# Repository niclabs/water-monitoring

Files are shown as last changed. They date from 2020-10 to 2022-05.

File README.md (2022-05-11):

# Sensores 🌡 

<!--
TODO: poner modelo de sensores de referencia.
TODO: poner cosas que salieron mal: medicion presión a 40cm, ...)
TODO: poner fotos de todos los experimentos para todos.
TODO: terminar de analizar íultimos datos.
TODO: poner tabla de resuemn resultados sensores.
-->

Se seleccionaron los sensores en la siguiente tabla para medir las variables fisicoquímicas de: Temperatura, Conductividad, pH, Nivel de agua y Turbidez.

| Variable | Modelo Sensor | Rango | Error | Resolución |
| --- | --- | --- | --- | --- |
| Tº | DS18B20 | \-10°C - 85°C | ±0.5 ºC | 0,0625 °C<br>(12 bit) |
| Presión | HK1100C | 0 - 1,2 MPa | 1.5% FS | 18 kPa<br>1.8 mt H2O |
| pH | Gravity: Analog pH Sensor/Meter  | 0 - 14 pH | ±0,1 pH | 0,014 pH<br>(12 bit) |
| Conductividad<br>Eléctrica | Gravity: Analog TDS Sensor/Meter | 0 - 1000ppm<br>0 - 2000 uS/cm<br>0 - 2mS/cm | ± 10% FS<br>200 uS/cm<br>0.2 mS/cm | 1,3 ppm<br>2,6 uS/cm<br>(12 bit) |
| Turbiedad | Grove - Turbidity Sensor/Meter | 0 - 3000 NTU | No indica | 4,5 NTU<br>(12 bit) |

- además se toma en cuenta los voltajes de funcionamiento de los sensores y el protocolo de comunicación.

Por lo general se sometió a los sensores a tipos de pruebas que permitieran evaluar dos dimensiones principales de su comportamiento: (1) su presición y (2) su desempeño por periodos prolongados de sumersión en medio acuático ('sensor drift'). 

## Temperatura

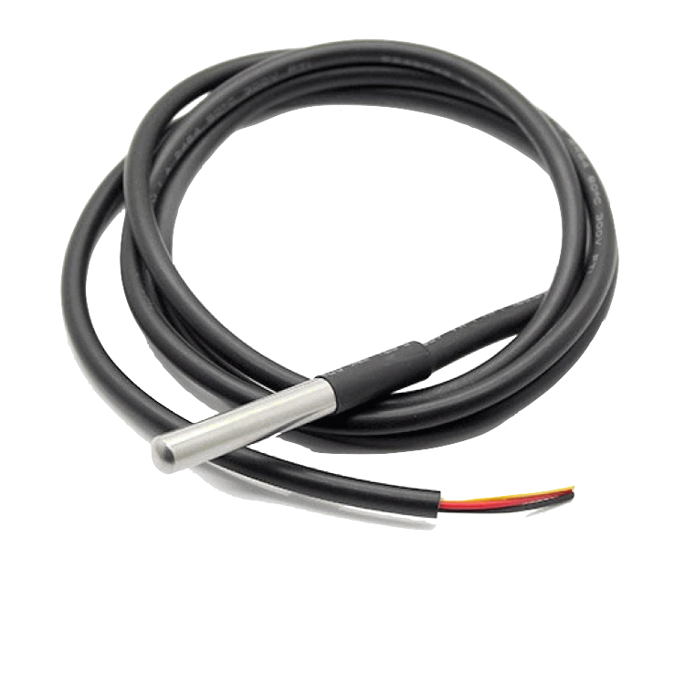
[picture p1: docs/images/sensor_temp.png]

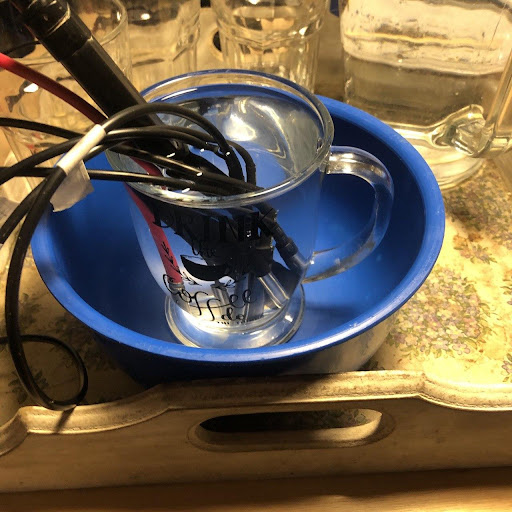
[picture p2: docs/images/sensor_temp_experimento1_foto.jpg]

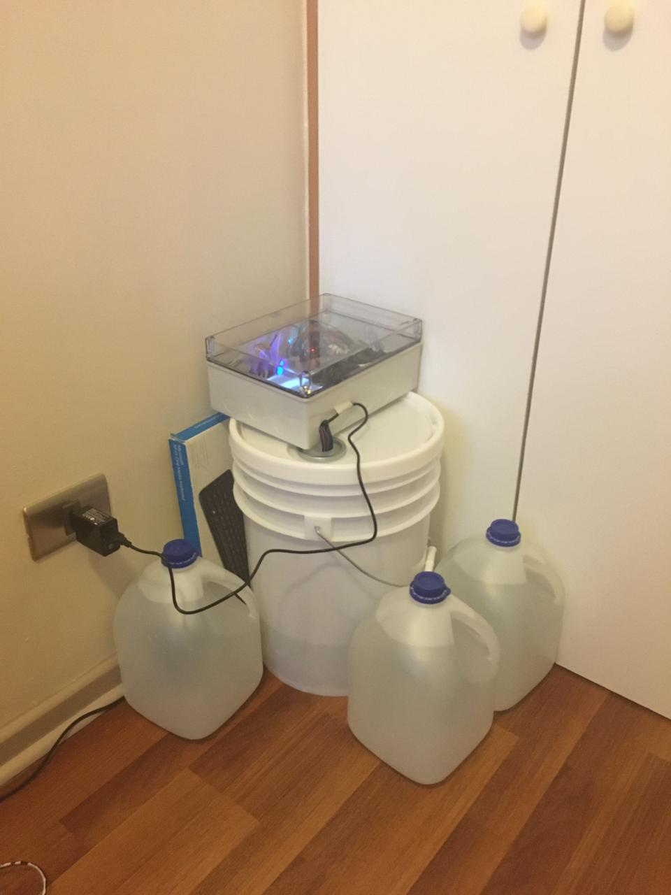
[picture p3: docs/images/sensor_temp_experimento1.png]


Experimentos demostraron un buen desempeño del sensor en su comportamiento en el tiempo

- comportamiento súper predecible.
- se debe ajustar el offset inicial.
- después de un tiempo se puede observar una leve desviación de la medidas, pero se puede corregir completamente reajustando el offset.
- errores menores a 0.5ºC y 1ºC

TODO: - Colocar sensor de referencia para saber cuál es.

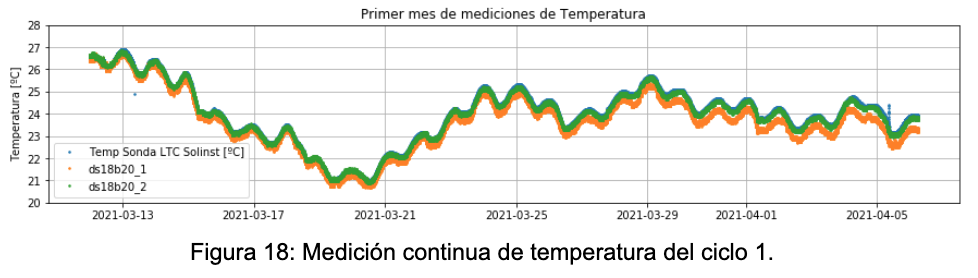
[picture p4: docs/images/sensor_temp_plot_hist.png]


- Error de dos sensores ds18b20 el primer mes de medición:
TODO: (se puede corregir por offset el error 1? indicar que sensores tenían un poco de uso ya?)

a title

- Error de sensores luego de 7 meses de uso. Experimento dura 1 mes.

a title

- Se desarrolla nueva metodología hacia últimos experimentos: ver perfil de medición en el rango. Se observa algo de histéresis en ambos sensores para la bajada.
TODO: (considerar rápidez en la toma de datos, existe histéresis en la bajada de temperatura para cambios rápidos)

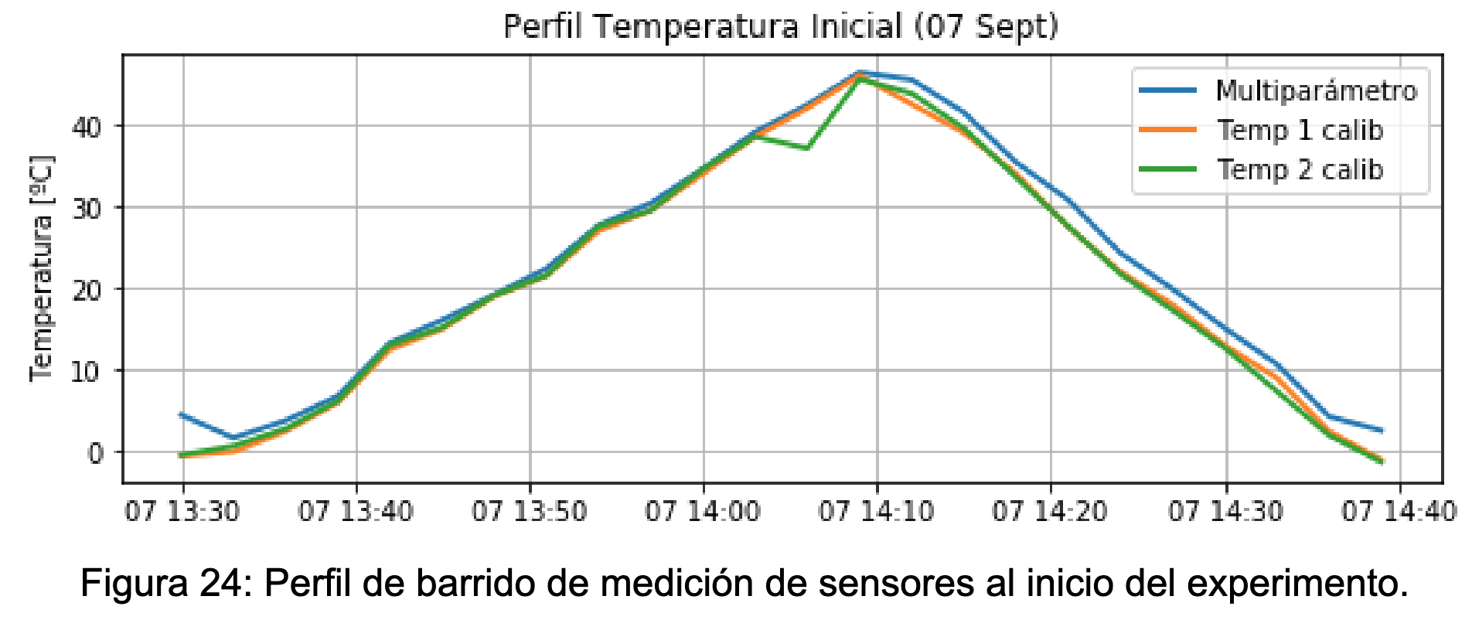
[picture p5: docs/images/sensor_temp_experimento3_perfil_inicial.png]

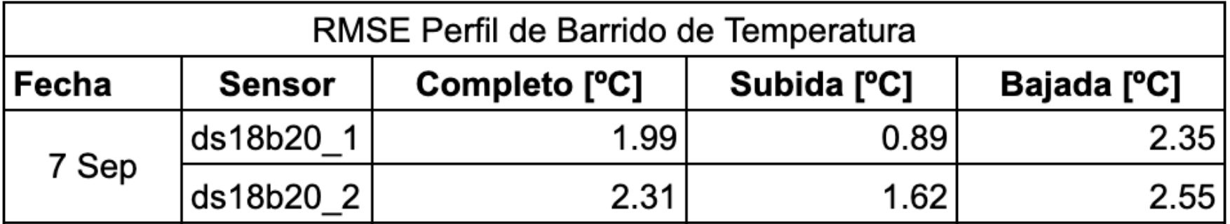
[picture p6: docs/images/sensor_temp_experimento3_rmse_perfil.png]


## Conductividad

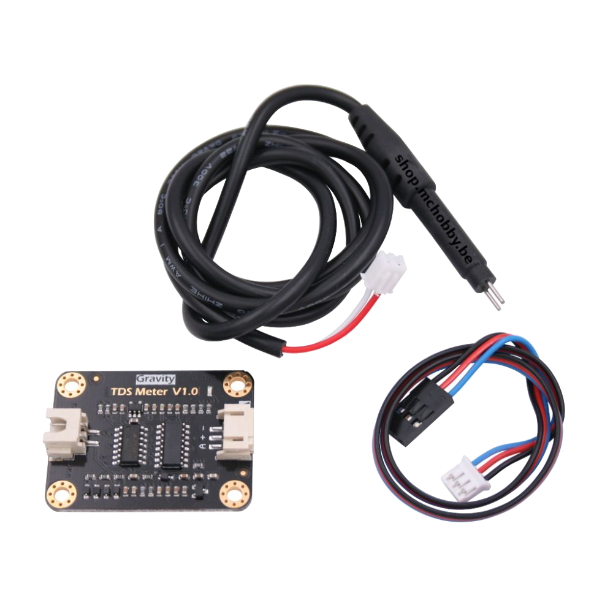
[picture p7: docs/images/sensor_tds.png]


TODO: (fotos del experimento)
TODO: al medir dos sensores de conductividad se afectan la medida. Pero el de conductividad con pH o presión o temp no.

- Ojo: Documentación indica rango [0,2000 uS/cm] ([link producto](https://www.dfrobot.com/product-1662.html))

- Perfil de medición luego de 1 mes de experimento:
    - metodología incluye sensor de control.
    - desgaste irrecuperable del sensor sumergido.
    - no se ve histéresis y tampoco en los datos

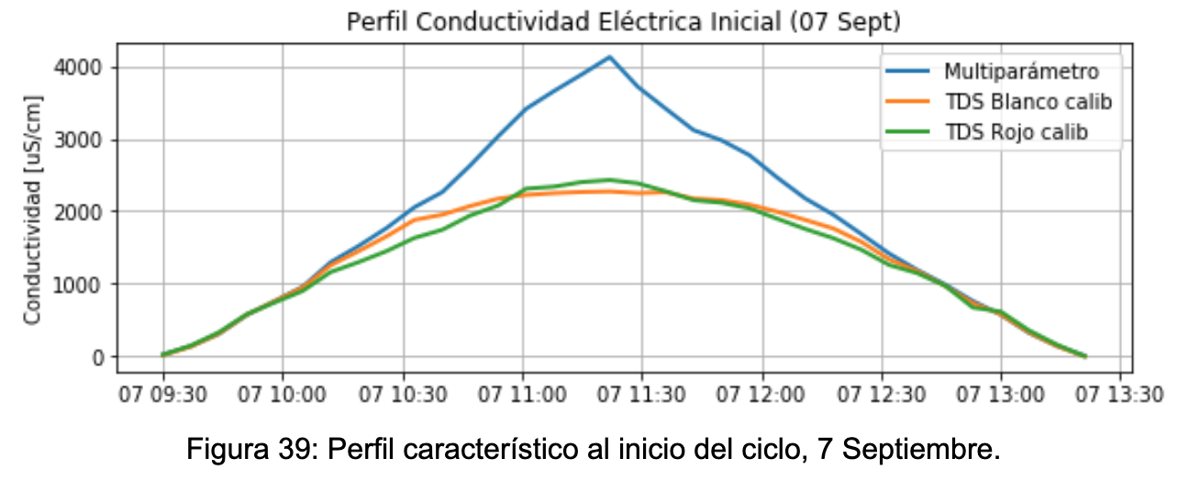
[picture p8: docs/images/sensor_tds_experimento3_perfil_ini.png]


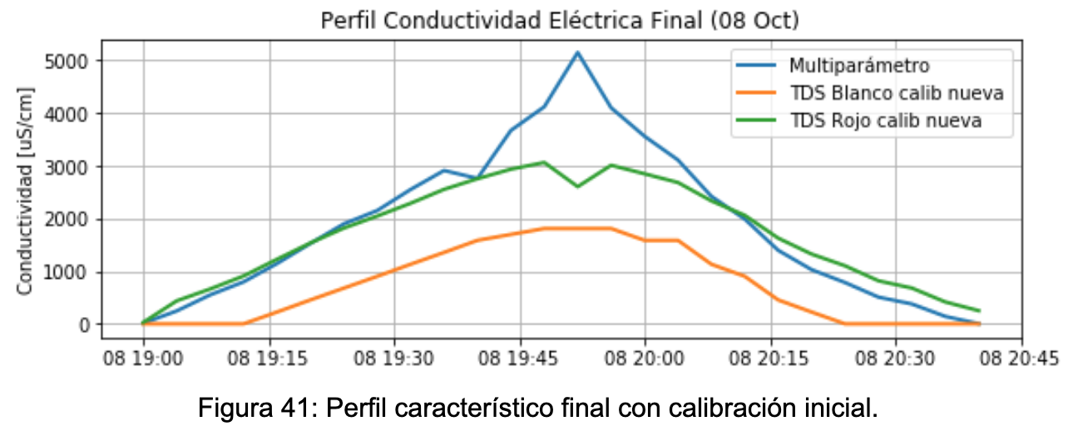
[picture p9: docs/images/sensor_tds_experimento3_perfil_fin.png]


- Si es importante la saturación sobre los valores ~1500 uS/cm y ~2000 uS/cm.

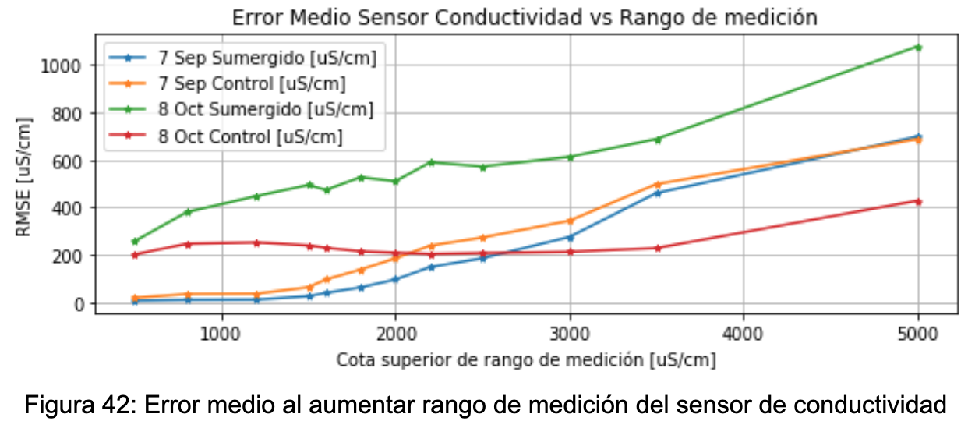
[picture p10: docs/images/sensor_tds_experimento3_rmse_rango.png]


- Se esperan más experimentos para ver si es por depositos de minerales en el sensor, o si es corregible, o fue un error puntual, o etc.

## pH

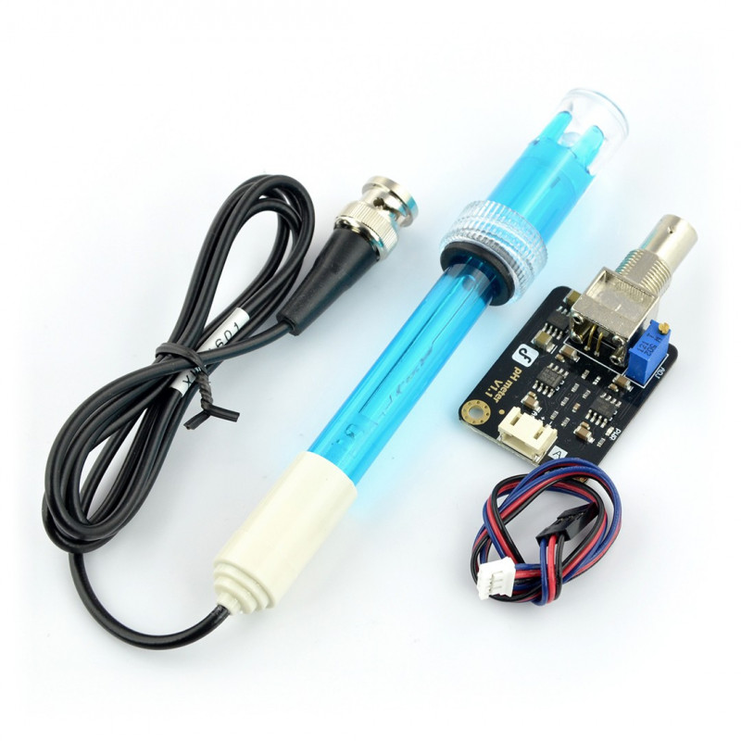
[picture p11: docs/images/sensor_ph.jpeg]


TODO: fotos experimento

- no se ve mucha histéresis
- hay harta variación en la calibración pero es posible recalibrarla y los sensores vuelven a funcionar.
- se esperar hacer más experimento para corroborar datos y además poder ir estimando que tan rápido se descalibran los datos, y cuánto se va perdiendo de presición con cada recalibración.

- Perfil inicial del experimento:
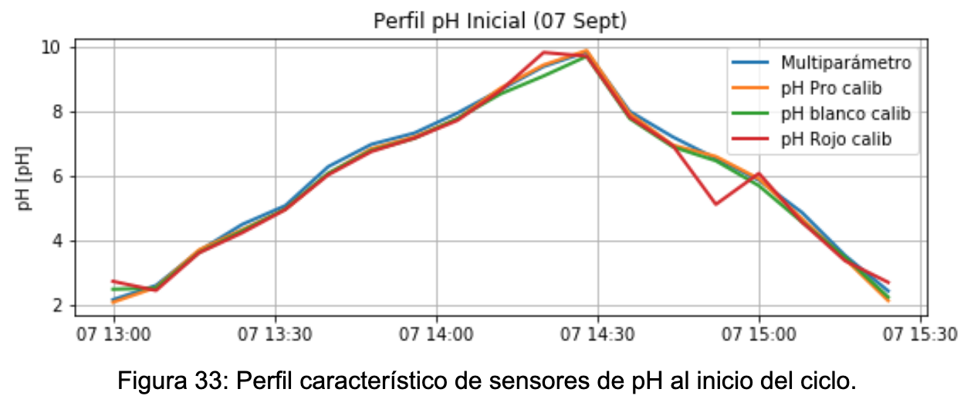
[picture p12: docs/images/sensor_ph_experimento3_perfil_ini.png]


- Perfil al final del experimento sin recalibrar:
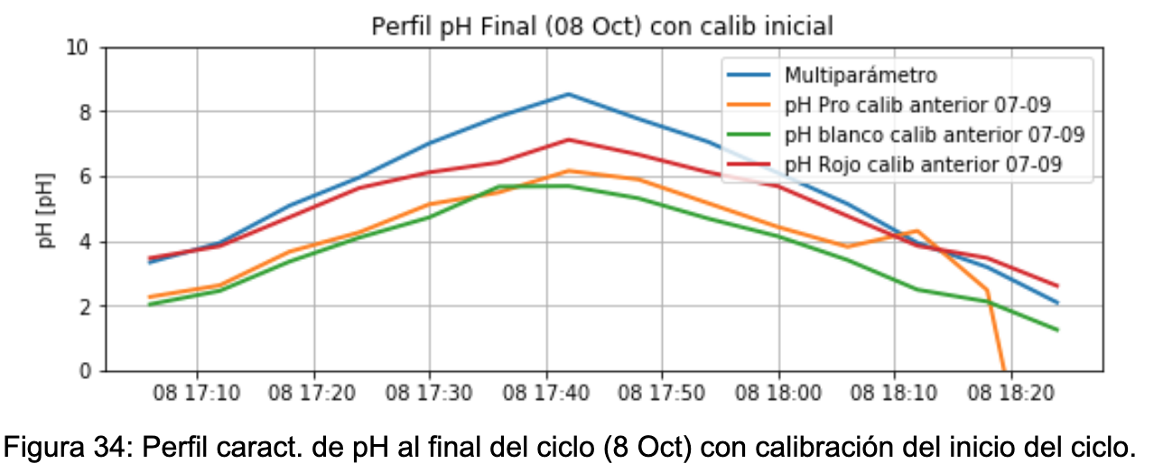
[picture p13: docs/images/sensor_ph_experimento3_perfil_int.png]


- Perfil final con recalibración de los sensores:
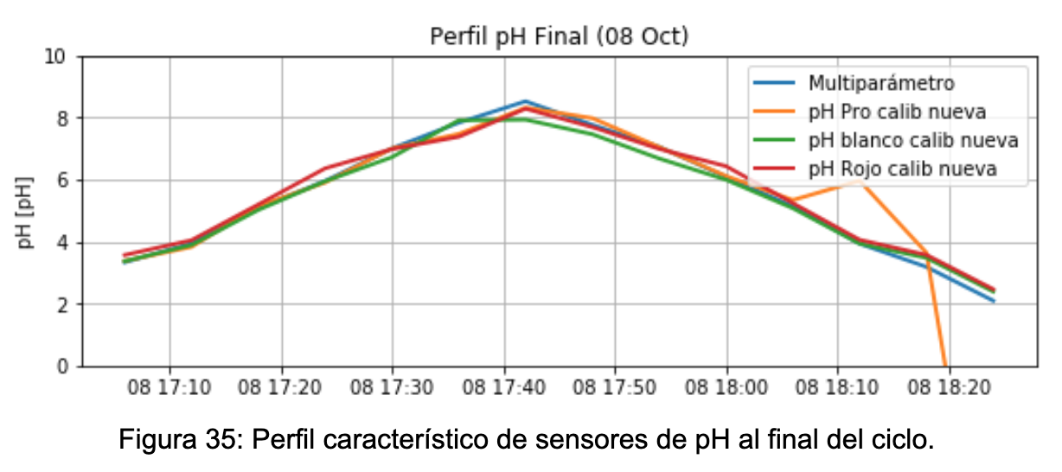
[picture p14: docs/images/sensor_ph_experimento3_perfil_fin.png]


## Nivel de Agua

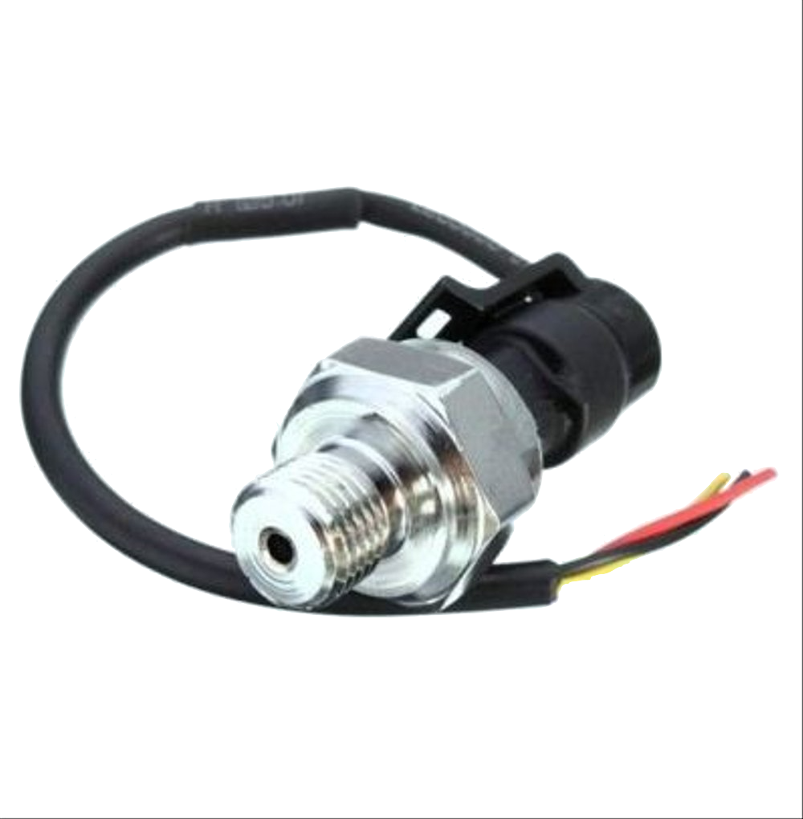
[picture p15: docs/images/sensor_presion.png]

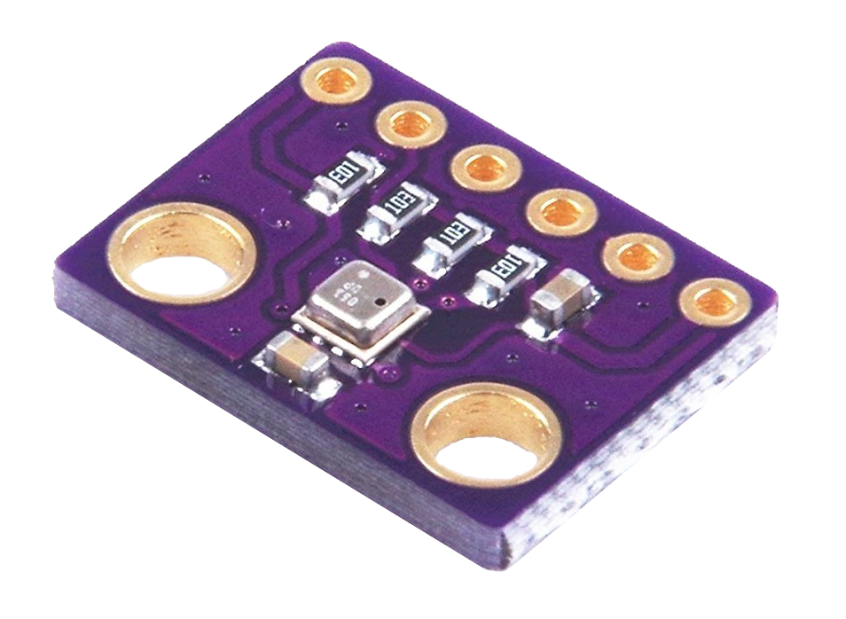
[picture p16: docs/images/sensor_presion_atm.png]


- Se utilizan dos sensores para calcular la columna de agua 
- TODO: Poner sensores dereferencia para ambos casos.

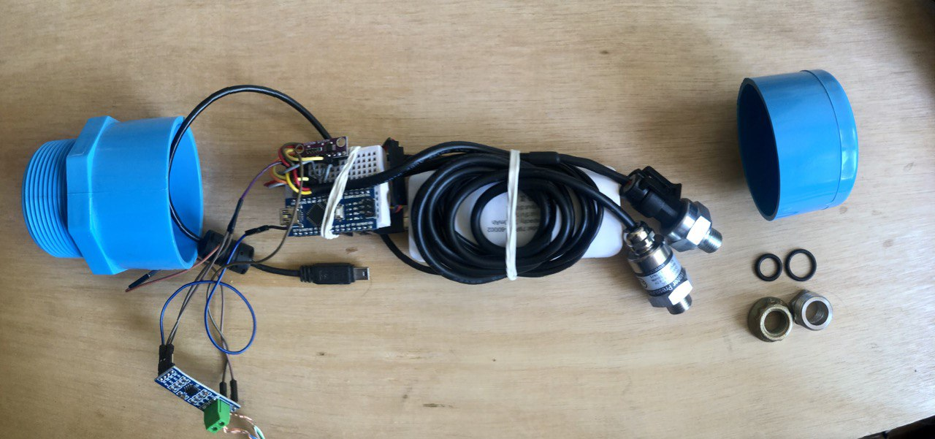
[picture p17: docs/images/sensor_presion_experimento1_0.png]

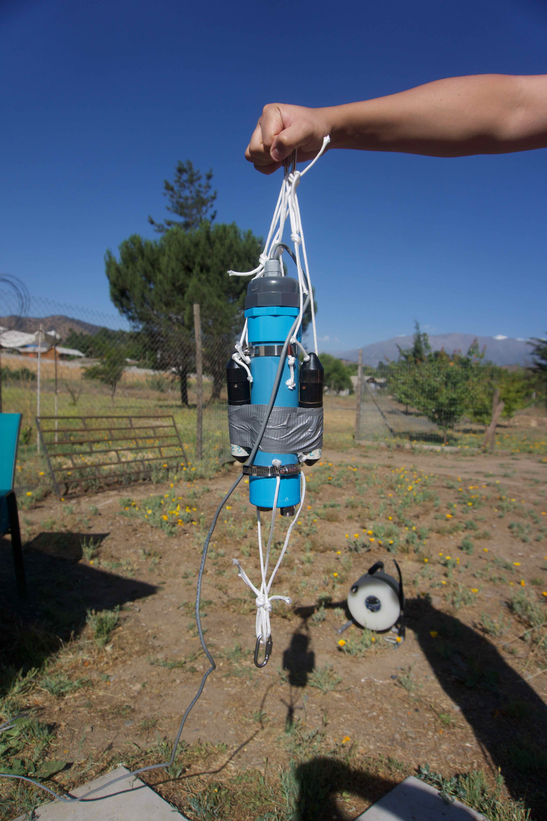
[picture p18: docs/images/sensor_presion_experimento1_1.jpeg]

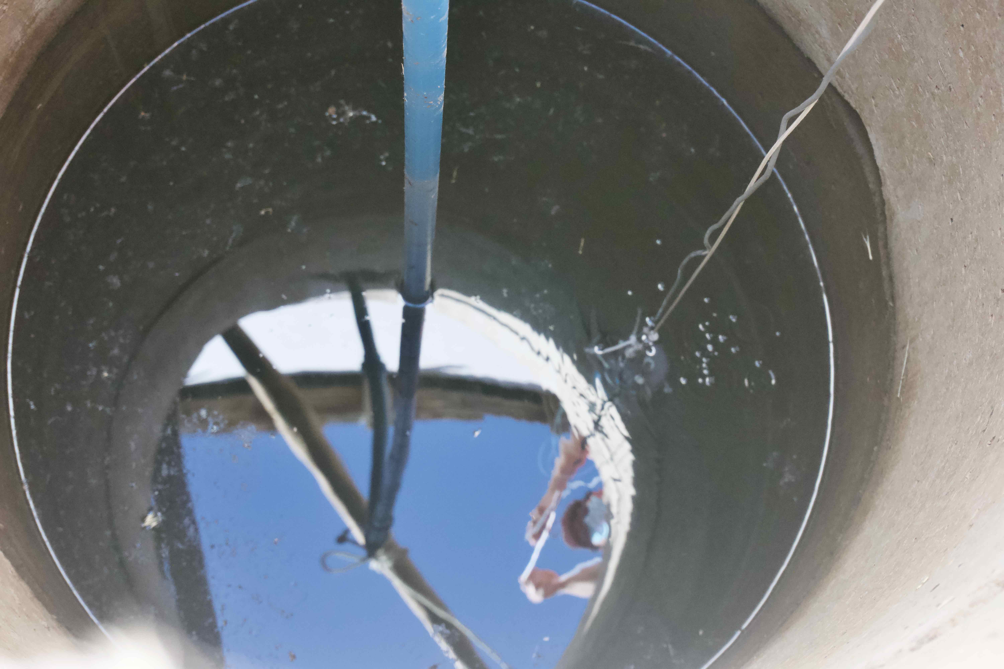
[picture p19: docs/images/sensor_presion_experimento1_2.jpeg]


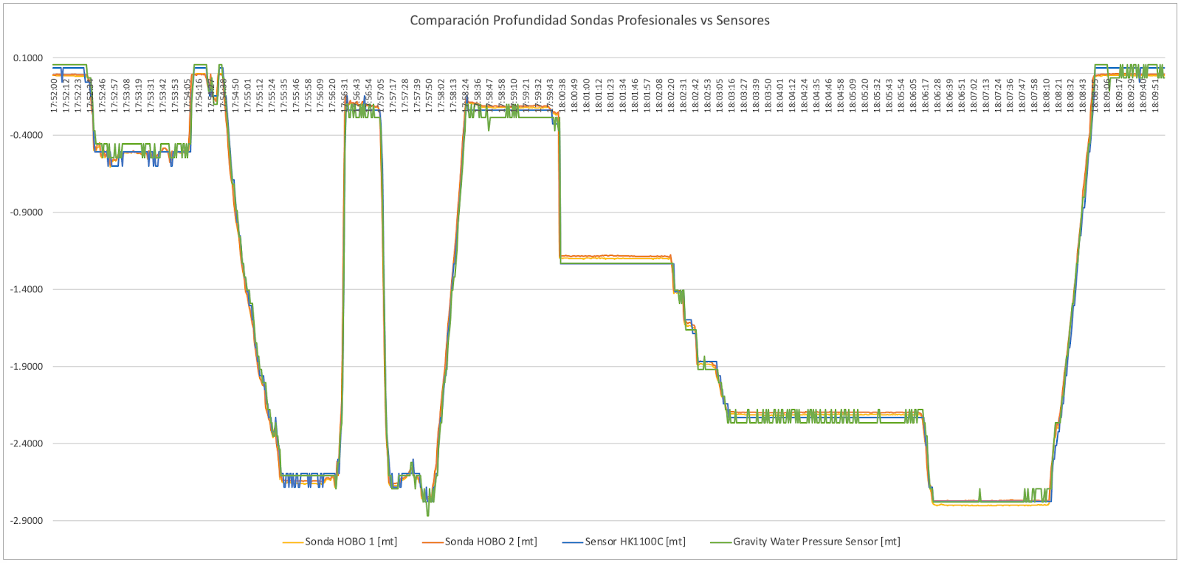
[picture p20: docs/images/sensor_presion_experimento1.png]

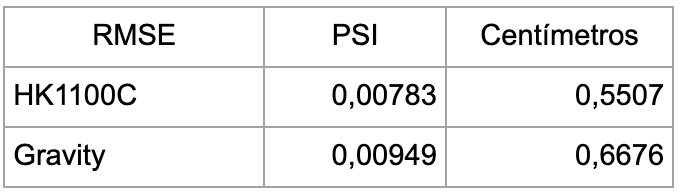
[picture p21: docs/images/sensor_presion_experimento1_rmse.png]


- últimos experimentos fueron en baldes de agua y mato, porque muy poca altura asi que el desempeño fue peor, pero este no empeoró luego de 6 meses con sensores sumergidos.

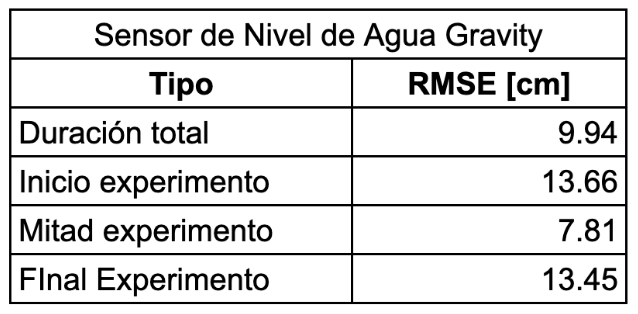
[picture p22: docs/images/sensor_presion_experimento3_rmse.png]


## turbidez

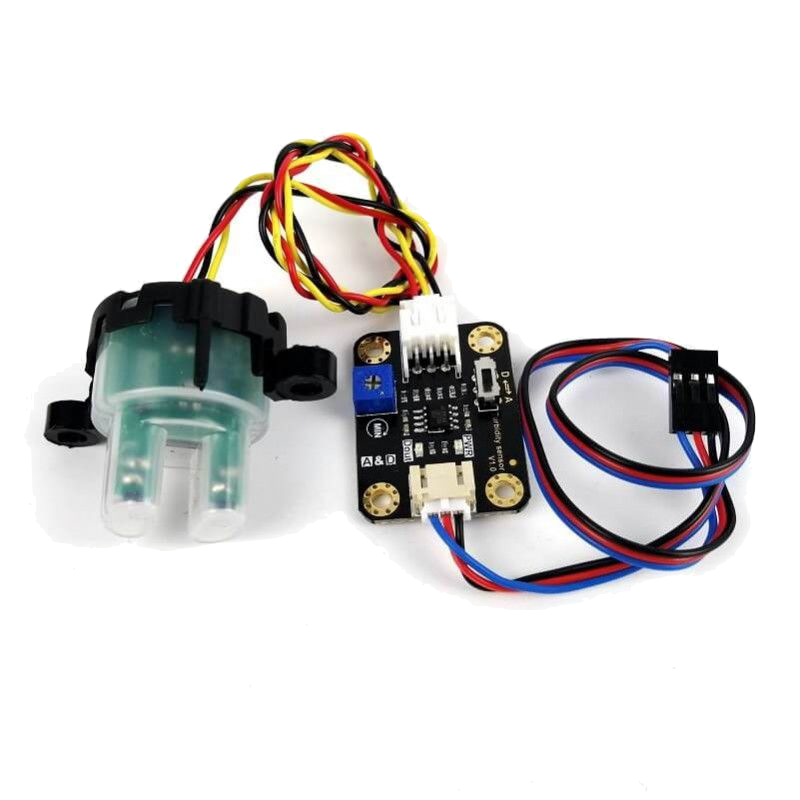
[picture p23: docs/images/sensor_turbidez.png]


- primeros experimento dieron cualquier cosa, dificultad en uso de sensor muy delicados a la luz y otras variables dificiles de controlar.

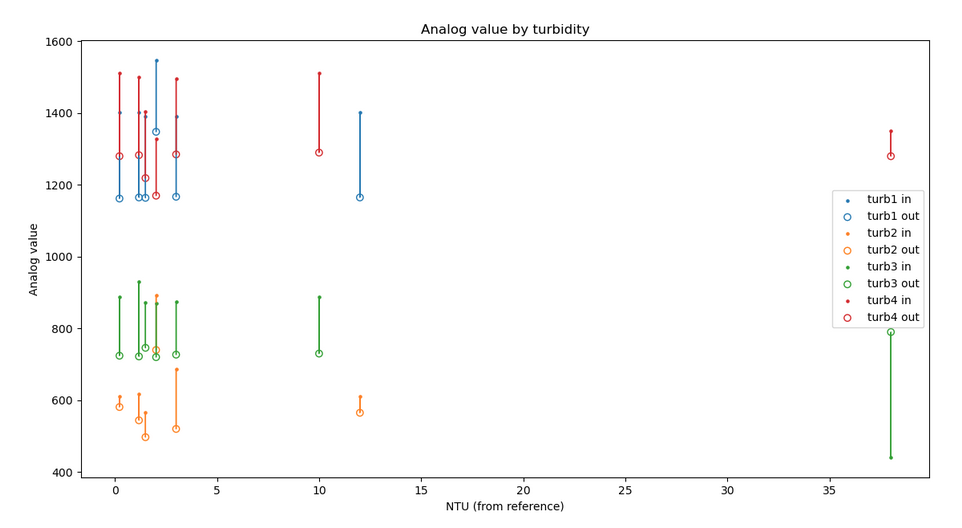
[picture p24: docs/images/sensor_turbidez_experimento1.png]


- Errores del rango de ~1000 NTU. No confiables, quizás solo apra alertas grandes pero mejor seguir buscando.

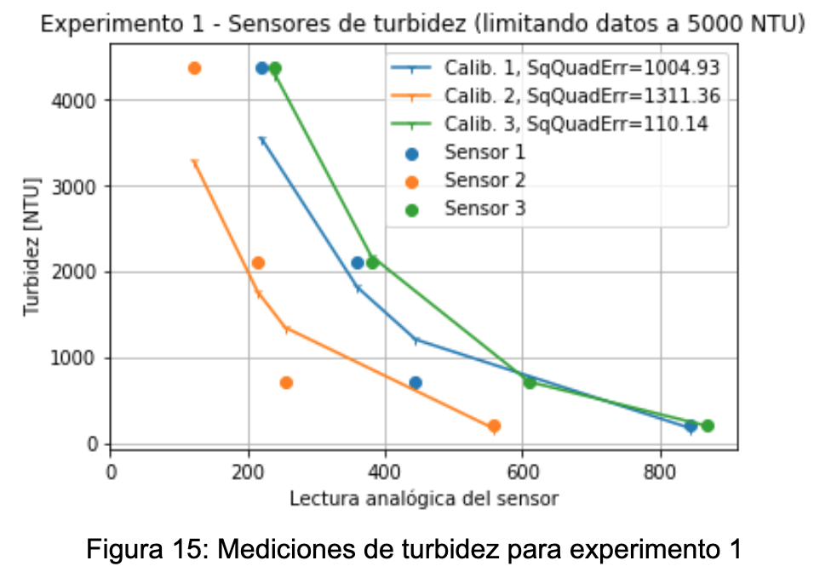
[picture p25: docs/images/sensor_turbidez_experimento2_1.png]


# 💻 Electrónica

## Diseño
El dispositivo de electronica (nodo sensor) diseñado para el monitoreo de de agua en intervalos de tiempo de manera autónoma, esta basado en tomar las medidas con sesores para ser enviadas mediante comunicación serial a un sistema de comunicación para el monitoreo de estas características, este dispositivo tomará medidas de pH, Condutividad, turbidez, temperatura y presión.

*imagen sistema completo resaltando el nodo sensor*

### Prototipo
Como prototipo  se realizó un circuito en Arduino para realizar pruebas con sesores, medidas y comunicación para obtener una versión funcional que pudiera enviar los datos. Este prototipo su funcionamiento principal se basa en dos estados principalmente Reposo (Sleep), estado en el cual se esta en bajo consumo y sin trabajo de meddidas y segundo activo que esta encargado de tomar las medidas de los sensores, guardar estos datos de manera codificada y enviarlos de manera serial con comunicación 485.

El funcinamiento básico se puede ver en el siguiente diagrama:

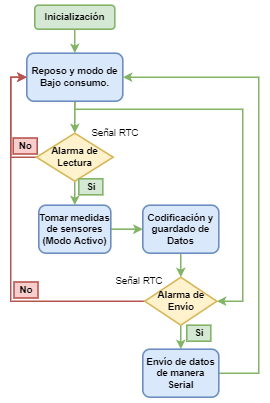
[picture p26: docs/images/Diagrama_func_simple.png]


#### Selección de componentes.
Dado lo anterior los componentes que integran este prototipo inicial son los siguientes:

1. **Arduino Nano:** Microcontrolador principal con el programa principal.
1. **ADC:** Lectura de señales analógicas a digitales de los sensores.
1. **RTC:** Encargado de establecer las alarmar de medida y envio al microcontrolaor para llevar a cabos estas tareas.   
1. **Modulo SD:** Para el guardado de los datos medidos de manera codificada.
1. **Sensores:** Temperatura, conducitividad, pH, Presión y Turbidez. 
1. **RS485:** Para realizar una comunicación serial de gran alcance(>10m).

Destacar que estos sensores seleccionados se sometieron a una serie de pruebas para comprobar su rendimiento, ver sus limitaciones y desgaste en el tiempo explicado en mas destalle en el apartado de sensores.

Por otra parte la conexión entre estos componentes esta dado se manera simplificada en el diagrama a continuación:

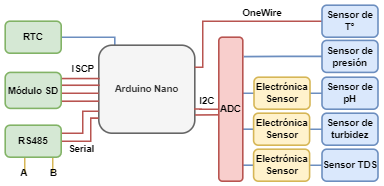
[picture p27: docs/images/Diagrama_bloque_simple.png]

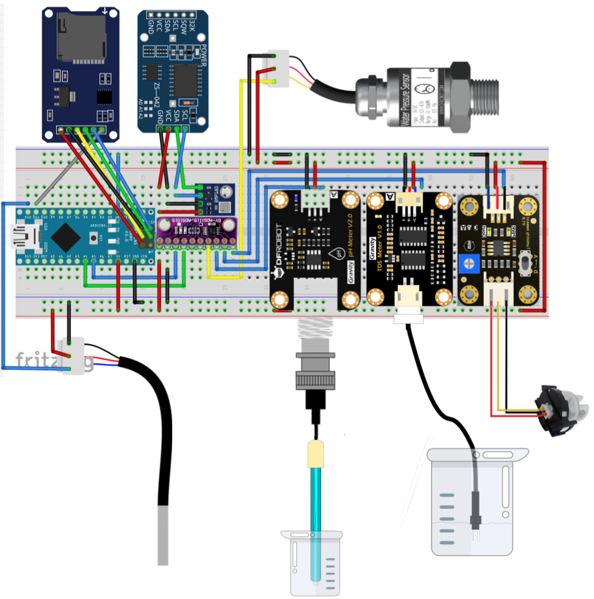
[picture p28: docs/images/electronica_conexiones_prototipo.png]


Donde los sensores TDS, pH y turbidez poseen su electrónica, el de presión entrega sus valores al ADC y el de temperatura mediante comunicación "OneWire" directamente al microcontrolador. El módulo SD se comunica con el microcontrolador a travez de conexion "ISCP", en cambio el ADC posee una conexión I2C para tener las señales de los 4 sensores y por último la imformación de los sensores es enviada de manera serial al componente 485 y es enviada mediante los canales A y B. 

Como resultados iniciales se tiene un nodo sensor capaz de obtener medidas, guardar estos datos en una microSD y además enviar estos datos de manera serial siendo un prototipo inicial lo suficientemente útil para la realización de pruebas en profundidad y analizar las limitaciones de los sensores bajo condiciones en profundidad controlada.

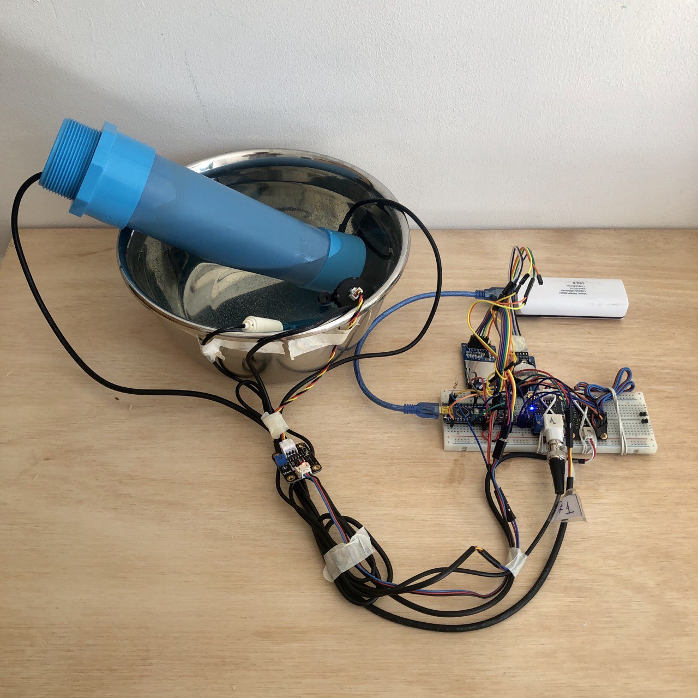
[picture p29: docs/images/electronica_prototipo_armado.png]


### PCB
Continuando con las mejoras del del nodo sensor, y el prototipo funcionando de manera adecuada, si bien es un dispositivo apto para la realización de pruebas controladas, se busca un dispositivo más apto en terrenos reales, como profundidasdes de aguas de al menos 30 metros. Para ello se relizó una integración den PCB con un frabicante local de PCB y diseño de circuitos, pasando prototipo a una PCB con mejoras incluidas dadas principalmente en el sistema de energía y espacio:

1. **Fuente energética con baterías:** Agregar al nodo un circuito de energía que sea alimentado a travéz de baterías de litio 18650 con toda su electrónica para un correcto funcionamiento (Cagardores y elevadores).
2. **Distribución energética de componentes:** Dividir la fuente de energía en una activa (5V) que siempre entrega alimentación al sistema y una de reposo (5Vs) que se apaga cuando el sistema no esta midiendo o enviado datos para aquellos componentes que puedan ser apagados para reducir el consumo lo mayor posible.
3. **Reducción de espación para Carcasa:** Optimizar el espacio creando un dispositivo con la electrónica más compacto para la utilización de la carcasa especial que fue diseñanada especialemnte para ser más apta al surmergirse.

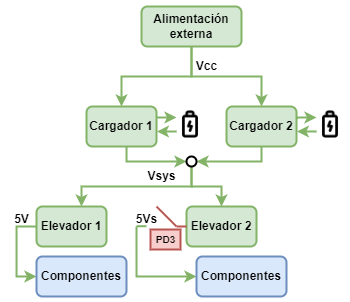
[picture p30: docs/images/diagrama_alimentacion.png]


La PCB incluye toda la electrónica de sensores y las necesarias  como reguladores de voltaje (-5V,3V,-3V y 3.3V) para compoenetes y electrónica siendo una pieza completa que se insertan los sensores para tomar las medidas. Posee además una conexion FTDI para realizar la programación del microcontrolador y un interruptor para utilizar comunicación serial directa al microcontrolador en vez de la 485 para la realización de pruebas.

a title

#### Historial de Versiones

Debido a diversos tipo de situaciones como falta de pistas o distribuciones de los componentes en diferentes fuentes de energía (5V y 5Vs) o simple optimización de esta, se obtuvieron diferentes versiones de PCB como modificaciones diferenciadas principalmente en la distribución energética a modo mejora,  estas versiones y modificaciones estan resumidas en la siguiente tabla.

| PCB | **Modificación** | **Características** | **Resultado** | **Problemas** |
|---|:---|:---|:---|:---|
| **Versión 1.a** | Primera PCB fabricada | Distribución de alimentación en reposo y continua. | Placa completamente funcional | La alimentación de resposo solo esta conectada con el compoente RS485. |
| Version 1.b | Corte y cambio de pistas para la PCB inicial | Distribucion energética de compoenetes mas eficiente. | Reducción del consumo en estado activo. | Componete RS485 de alto consumo en rposo |
| Version 1.c | Cambio de compoente RS485 manualmente | Optimización de consumo en rposo | Problema funcional de la placa, (mala practica de soldadura) | PCB sin funcionamiento. |
| **Versión 2.a** | PCB con enrrutado nuevo | Compoentes divididos en su mayoria correctamente | Placa completamente funcional | RS485 de alto consumo y en alimentación continua, falta de una pista.  |
| **Versión 3.a** | PCB con enrrutado nuevo | Correccion de la pista faltante de la version antrerior. | Placa completamente funcional | RS485 de alto consumo y en alimentación continua. |

Estas versiones se ejemplifican en esquemas a continuación para detallar los cambios de distribución energética de los compoentes que son alimentados con 5Vs y 5v respectivamente.

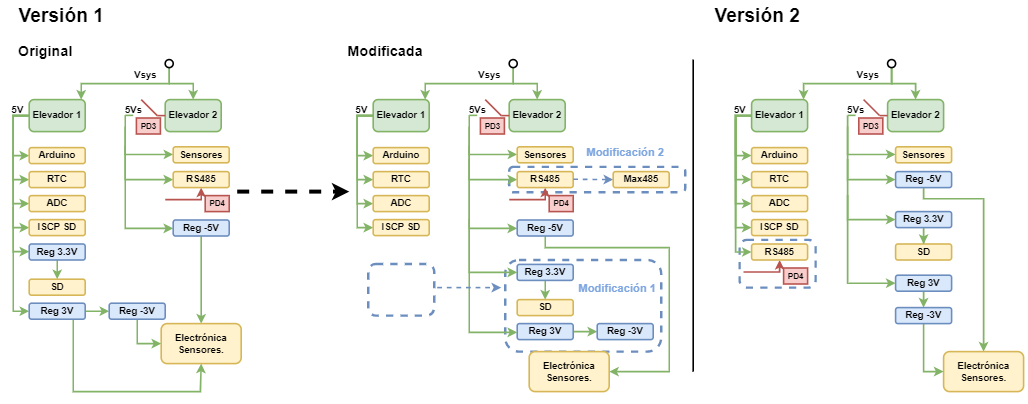
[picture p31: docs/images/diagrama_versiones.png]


<br>
- Mejoras no realizadas: como mejoras no realizadas se tiene el cambio del componente de comunicación 485 de alto consumo debido a que es antiguo, aun más en esta versión ya que esta conectado en la alimentación constante por lo que este consume con el sistema en reposo.
## Fabricación

Con los archivos de una versión funcional del sistema (Versión N°2), se realizó un estudio en la fabricación de esta placa para tener una idea y obtener un analisis en terminos de los costos que tiene finalmente el "nodo sensor". 

### Cotización:
Para cotizar se considero la posibilidad de una fabricación y ensablaje completamente externo con los componetes entregados por el fabricante.

#### 1. Fabricación y ensamblaje externo:
Consireaciones:
 * Para esta cotización se tomaron en cuenta los fabricantes: JLCPCB, PCBway, PCBgogo, EEcart, SeedStudio.
 * Los precios obtenidos son dados en base a cotizaciones rapidas entregadas por los fabricantes.
 * Los archivos requeridos para las cotizaciones Gerber (PCB), BOM (componentes) con un formato específico para cada fabricante y el *"pick and place"* en algunos casos.
 * La cotización fue realizada para una cantidad de 5 PCBs ensambladas (cantidad mínima aceptada).

 #### 2. Fabircación externa y ensamblado local:
 La cotización de esta opción la placa es fabricada de manera externa y los componetes cotizados a los distribuidores.

 Consideraciones:
* El ensamblaje se consideró de manera manual.
* Utilización de stencil para el ensamblado.
* Se realizó una cotización de 5 placas.
* No todos los componentes son fáciles de obtener, se tiene que buscar sustitutos dependiendo del stock.
* Digikey y Mouser como distribuidores de componentes (al ser los mas completos).
#### 3. Comparación de opciones:

Dado el detalle del valor de componentes se hace una comparación entre las 2 opciones de fabricado,se consideró EEcart y PCB como fabricantes por ser las mejores opciones. además de una fabricación completa externa con una optimización de precios en componentes (RTC,pH), por un lado el RTC tiene un precio elevado y por otro el conector de pH se adquiere con el sensor.

Resultados y precios:

| | **Total (5u)** | **Total+ 30%** | **Precio unitario** | **Tiempo**  |
|---|---|---|---|---|
| **Local** | $772.09 | $1003.72 | $200.74 | 3-4 semanas |
| **Externa EEcart** | $907.26 | $1179.44 | $235.89 | 5 semanas |
| **Externa PCBWay** | $888.45 | $1176.19 | $231.00 | 5.5 semanas |
| **Externa PCBWay (RTC,pH)** | $705.06 | $916.58 | $183.32 | 5 semanas |

Considerar además un precio extra en cuando a sensores y baterías del dispositivo de $100.92USD/unidad aprox.

#### 4. Pros y contras

| Fabricación Local | Fabricacion Externa |
|---|---|
| - Menos tiempo estimado de realización. <br> - Menor precio estimado. <br> - Ensamblado manual. <br> - Dificultad de obtención de algunos componentes (stock limitado).  | - La placa llega para usar directamente. <br> - Margen de optimización. <br> - Mayor tiempo de espera. <br> - Mayor precio. |

### Programación
Hablando del software del dispositivo nodo sensor se poseen 2 versiones  con y sin SD para su funcionamiento, estos posee las siguentes caracteristicas:
1. Posee variables de los períodos de medida y envvío de datos: Es una de las características más importantes para la definición de tiempos de funcinamniento del sistema. La variable "Freq_sens" indica cada cuantos segundos tomada una medida de los sensores y la variable "Freq_send" representa el intervalo en segundos en el que son enviados los datos, claramente  Freq_send > Freq_sens  ya que deben existir datos medidos para ser enviados.
2. Codificación de lectura de datos: Para realizar un envío más eficiente ya sea por velocidad, memoria, disminución de consumo energético en el momento de enviar datos se desarrolló una librería que codifique los datos para ello. Lo importante a destacar es qu exite una codificación de lectura y otra de envio explicada mas adelante.

La codificación de lectura simplemente pasa a bytes(9) la medida (valor) del sensor, tiempo(timestamp) dado por la alarma de medida del RTC en formato "Unix" y si ID del sensor (valor predeterminado).

3. Guardado de datos en un "DataBlock": Los datos de cada intervalo, es decir, el tipo (sensor ID), su valor y tiempo de medida (Timestamp) en cada sensor son codificados (explicado más adelante) en bytes al que llamaremos "sensor reading", estos son generados en cada medida y será guardado en el "Datablock" (arreglo) de 512 bytes que actuara como memoria RAM-buffer. Los "sensor reading" son lo que poseen la codificación de lectura con un largo de 9 bytes para el guardado de los datos. Dado esto la estructura del Datablock esta dada por 2 bytes para llevar el conteo de medidas, 504 bytes para "sensor reading" (56 medidas u 11 medidas de 5 sensores) y 6 bytes sobrantes como se puede ver a continuación.

Para el caso de la sd cuando el DataBlock esta lleno guarda los datos en archivos binarios dentro de la tarjeta SD y los envía junto a los valores del arreglo cuando sea el tiempo de enviado con una codificación nueva para el enviado. Si es la versión sin sd no se posee más memoria que la del arreglo por lo que esta limitado a medir una cantidad maxima de datos antes de enviar, por lo que la "Freq_send" tiene esta limitante, por ejemplo,un máximo de 11 veces la Freq_sens para 5 sensores para no perder datos en la codificación base.

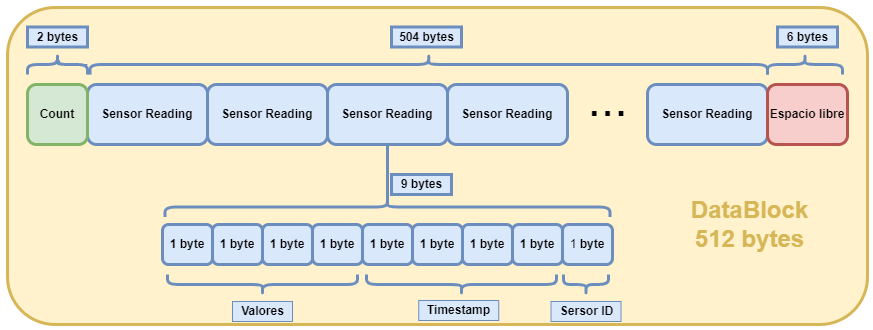
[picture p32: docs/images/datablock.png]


4. Codificación par envío de datos: Para reducir la cantidad de tamaño de los datos enviados y asi realizar un envío más rápido con menor consumo, se reali´zaron distitos tipos de codificación de enviado a modo de reducir el tamaño de los datos.
* Codificiación de envío base:  Para esta codificiación y las siguientes se define un nuevo bloque "Sensing Unit", que se divide en 1byte "Header" que posee la informacion del tipo de codificación y la ID del sensor y 6 bytes "Payload" que contiene 4bytes para el Tiemstamp y solo 2bytes para el valor del sensor, esta reducción ene le valor del sensor se debe a que los valores de los sensores al ser pequeños pueden ser prefectamente representados en 2bytes. Reduciendo la unidad "sensor reading" de 9bytes a la unidad "Sensong Unit Base" de 7bytes.

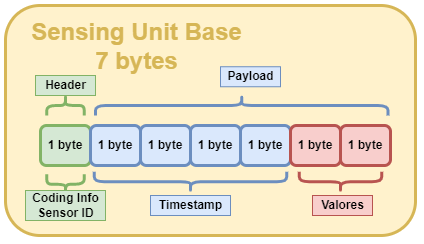
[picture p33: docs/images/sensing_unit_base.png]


* Codificación envío repetivvio:
* COdificacion envío diferencial:

4. Los datos son envidos mediante transmisión serial RS485  como paquetes de bytes: Como los datos son codificados a bytes estos son enviados de esta manera en paquetes de bytes a través de comunicación serial RS485 estos estan dados por un tamaño máximo de 51 bytes, es decir, 7 Sensing Unit (49 bytes) y 2 bytes para detección de errores. Este tamaño se define debido a que es el tamaño mínimo de un paquete en LoRa (módulo de comunicación inalámbrica utilizada en la superficie del sistema).

Código completo:
El primero es el codigo completo que utiliza la sd para el guardado de los datos, el codigo esta centro

Ejemplos del funcionamiento de medidas:

## Roadmap
backlog
pasos futuros

| N  | Título | Detalle |
| -- | --- | --- |
| 1  | Mover uSD a superficie | Hacer que la uSD sea controlada y alimentada desde el nodo de comunicaciones en vez del nodo sensor. |
| 2  | Bajar ciclos del oscilador a 8Mhz | Disminuir ciclos del oscilador de 16MHz a 8MHz. Esto disminuye la velocidad a la que opera el sistema sin afectar el funcionamiento de los programas. Funcionando a la mitad de ciclos se espera una disminución del consumo del procesador en el sistema. |
| 3  | Ocupar VCC 3.3V | Bajar alimentación del sistema de 5V a 3.3V. Se debe prototipar y validar el funcionamiento de componentes y electrónica. Con este cambio disminuye el consumo general de energía del sistema obteniendo mayor desempeño de estados de deep-sleep. |
| 4  | Amplificador universal multiplexado | Si se caracterizan debidamente las sondas y se verifica que el procesamiento de los circuitos intermediarios se pueden realizar de forma digital, una opción es tener un amplificador para todas las sondas, las cuales mediante multiplexión temporal entren a éste (opcionalmente un digipot puede ayudar a modificar la ganancia). Esto podría reducir drásticamente la cantidad de componentes en placa. |
| | Integrados de carga de baterías en paralelo | |
| 5  | Autonomía de sensores (drift) | Si se va a aumentar la autonomía del sistema, es necesario verificar si en ese horizonte de tiempo los sensores serán funcionales. |
| 8  | Optimización de componentes | Relacionado con los puntos 3 y 4, hay que repasar toda la selección de componentes en términos de funciones y equipos. También se relaciona con la programación. |
| | | |
| 6  | Autonomía energética (solar, electrónica) | Añadir un sistema de carga solar para recargar las baterías 18650 del nodo sensor podría en prácticamente cualquier caso mejorar la autonomía. |
| 7  | Batería de auto | Colocar una batería de auto para todo el sistema teóricamente aseguraría una mayor autonomía. |
| 9  | Programar nodo a distancia | \- Se podría cambiar el atmega por un esp que se programe a distancia. |
| 10 | Switch magnético de encendido | Se puede agregar un switching on/off del sistema que se puede activar desde fuera de la carcasa con un imán para de esta manera poder ahorrar energía cuando no se esté utilizando el dispositivo. |
| 11 | Modularizar datalogger de adaptadores sensores | Separar en placas separadas, pero conectables el datalogger (uC, RTC, SD, energía) de electrónica de amplificación de los sensores dfrobot (pH, turbidez, conductividad) | z<x

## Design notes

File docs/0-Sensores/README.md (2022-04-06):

# 🌡 Sensores

## Opciones

## Costo

## Resultados

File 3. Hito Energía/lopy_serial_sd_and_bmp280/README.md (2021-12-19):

# lopy_serial_sd_and_bmp280

Conexión de la LoPy con un Arduino mediante UART. Cada vez que la LoPy recibe un mensaje del Arduino, lo almacena utilizando el lector de microSD de la tarjeta de expansión.

- Código LoPy (`LoPy4_sd`) basado en `LoPy4_serial`
- Código Arduino (`dummy_data_sender`) basado en `arduino_nodo_sensor`

Cableado:
- Conectar, a través de un adaptador de nivel, los pines de comunicación serial de la LoPy y del Arduino según dice `LoPy4_serial/boot.py` y `dummy_data_sender/dummy_data_sender.ino`, respectivamente. *CAVEAT*: Usar pines P3 y P6. El P4 lo utiliza la LoPy para comunicarse con la tarjeta SD.
- Conectar la LoPy a la tarjeta de expansión
- El contenido del buffer del script de Arduino debería ser `0xF0000000000015F100000009001FF200000013000EF30000001D0010F4000000270006` (35 bytes). Esto también se incluye en el archivo `dummy.bin`.
- El mensaje recibido vía UART por la LoPy, una vez descartado el primer byte, debería ser `b'f0000000000015f100000009001ff200000013000ef30000001d0010f4000000270006'`. Esto calza con el mensaje enviado.
- Los datos decodificados son `[(0, 0, 2.1), (1, 9, 3.1), (2, 19, 1.4), (3, 29, 1.6), (4, 39, 0.6)]`, consistentes con lo codificado desde el Arduino.

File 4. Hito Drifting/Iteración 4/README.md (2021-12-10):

# Sketches Experimentos Sensores - Iteración 4

Experimentos de la <b>Iteración 4</b> corresponden a más experimentos de Presión y Conductividad. Se está evaluando nuevos experimentos de sensores de pH, junto con buscar nuevos modelos o equipos de medición para todos lo sensores anteriores.

Experimentos se desarrollan en casa de Pablo Martín y en Laguna Carén.

## Programas Arduino

### FONDEF_carcasa_arduino_datalogger

Programa para electrónica a sumergir en Laguna Carén dentro de carcasa fabricada por +D.

| Funcionamiento |
| - |
| - Lectura periódica de sensor de RTC, Sensor de Presión y BME280, almacenamiento en micro SD
- Carga de batería 18650 de 3200mAh desde alimentación externa |

| Componentes | | |
| - |  - | - |
| Arduino Mini Pro 3.3V 8MHz | Módulo SD | DS3231 |
| Batería 18650 |  TP4056 | ADS1015 |

| Sensores | |
| - | - |
| Presión | BME280 |

### FONDEF_drifting_arduino_datalogger_it4_serial2nodemcu

Programa para Iteración 4 de experimentos de presión y conductividad. Corresponde al sketch de arduino que captura periódicamente datos desde sensores y rtc, los guarda en micro SD y los envía por serial para que NodeMCU los suba a Servidor Niclabs y Telegram Bot.

### FONDEF_drifting_arduino_datalogger_it4_serial2nodemcu_v2

Igual al anterior (_FONDEF_drifting_arduino_datalogger_it4_serial2nodemcu_) pero con dos ADS1015 para medir 6 sensores en paralelo (capacidad de 1 - 8 sensores análogos).

### FONDEF_drifting_nodemcu_HTTP_POST_niclabs

Programa para Iteración 4 de experimentos de presión y conductividad. Corresponde al sketch del NodeMCU (ESP8266) que toma datos desde arduino por puerto serial y los envía a Servidor Niclabs y Telegram Bot.

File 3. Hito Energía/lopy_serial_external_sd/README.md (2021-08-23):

# lopy-serial-external-sd

Conexión de la LoPy con un Arduino mediante UART. Cada vez que la LoPy recibe un mensaje del Arduino, lo almacena utilizando un lector de SD externo (SPI)

- Código LoPy (`LoPy4_sd`) basado en `LoPy4_serial`
- Código Arduino (`dummy_data_sender`) basado en `arduino_nodo_sensor`

Cableado:
- Conectar, a través de un adaptador de nivel, los pines de comunicación serial de la LoPy y del Arduino según dice `LoPy4_serial/boot.py` y `dummy_data_sender/dummy_data_sender.ino`, respectivamente
- Conectar un módulo SD SPI del lado de 5V a la LoPy (del lado de 3,3), a los pines según dice `LoPy4_serial/boot.py`
- El contenido del buffer del script de Arduino debería ser `0xF0000000000015F100000009001FF200000013000EF30000001D0010F4000000270006` (35 bytes). Esto también se incluye en el archivo `dummy.bin`.
- El mensaje recibido vía UART por la LoPy, una vez descartado el primer byte, debería ser `b'f0000000000015f100000009001ff200000013000ef30000001d0010f4000000270006'`. Esto calza con el mensaje enviado.
- Los datos decodificados son `[(0, 0, 2.1), (1, 9, 3.1), (2, 19, 1.4), (3, 29, 1.6), (4, 39, 0.6)]`, consistentes con lo codificado desde el Arduino.

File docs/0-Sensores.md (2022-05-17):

# Sensores 🌡 

<!--
TODO: poner modelo de sensores de referencia.
TODO: poner cosas que salieron mal: medicion presión a 40cm, ...)
TODO: poner fotos de todos los experimentos para todos.
TODO: terminar de analizar íultimos datos.
TODO: poner tabla de resuemn resultados sensores.
-->

<!--
- poner figura de calidad de la medición vs costo
    - buscar tmbn alguna explicación en los informes
- poner figura del sistema completo donde sensores es input
-->

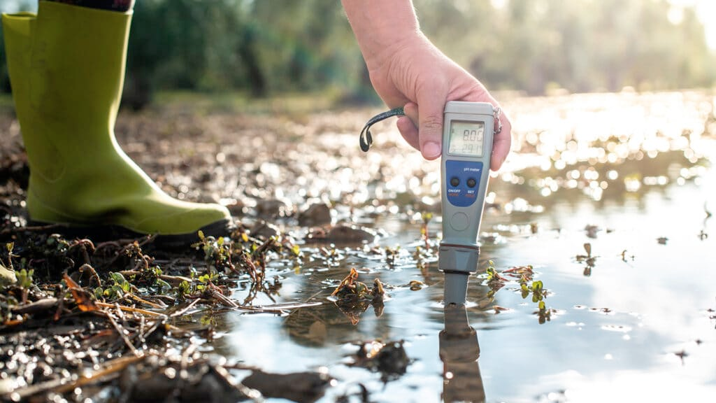
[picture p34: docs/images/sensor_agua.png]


La calidad de los datos generados que alimenten el sistema afecta directamente su desempeño y la calidad de información presentada a los usuarios del sistema, por esto los sensores a utilizar son de vital importancia. Pero a la vez mejores sensores implican un mayor precio, y el objetivo del proyecto es generar un sistema de bajo costo.

Dada esta carcterística, la caracterización del comportamiento de los sensores y definición de sus alcances permite generar un óptimo equilibrio entre costo de los equipos y desempeños esperados del sistema para los casos relevantes de uso, en los rangos definidos.

El objetivo es encontrar dispositivos de un costo bajo pero cuya calidad de medición sea la suficiente para operar el sistema. Muchas veces sensores industriales o profesionales pueden estar sobrestimados para la aplicación específica y tener una presición mayor de la necesaria para un análisis de las dinámicas y anomalías de acuíferos.

En la siguiente table encontramos los sensores en proceso de pruebas para medir 5 variables fisicoquímicas relevantes:

| Variable | Modelo Sensor | Rango | Error | Resolución |
| --- | --- | --- | --- | --- |
| Tº | - [DS18B20](https://altronics.cl/sensor-sonda-temperatura-ds18b20?search=ds18b20)  | \-10°C - 85°C | ±0.5 ºC | 0,0625 °C<br>(12 bit) |
| Presión  | - [HK1100C](https://altronics.cl/sensor-presion-hk1100c) <br> - [Gravity Pressure](https://www.dfrobot.com/product-1675.html)| 0 - 1,2 MPa | 1.5% | 18 kPa<br>1.8 mt H2O |
| pH | - [Gravity: Analog pH Sensor/Meter](https://www.dfrobot.com/product-1025.html)  | 0 - 14 pH | ±0,1 pH | 0,014 pH<br>(12 bit) |
| Conductividad Eléctrica | - [Gravity: Analog TDS Sensor/Meter](https://www.dfrobot.com/product-1662.html) <br> -[]()| 0 - 1000ppm<br>0 - 2000 uS/cm<br>0 - 2mS/cm | ± 10% FS<br>200 uS/cm<br>0.2 mS/cm | 1,3 ppm<br>2,6 uS/cm<br>(12 bit) |
| Turbiedad | - [Grove - Turbidity Sensor/Meter](https://www.dfrobot.com/product-1394.html) <br> - [Sensor turbidez](https://altronics.cl/sensor-turbidez-liquidos) | 0 - 3000 NTU | No indica | 4,5 NTU<br>(12 bit) |

Se sometió a los sensores a tipos de pruebas que permitieran evaluar dos dimensiones principales de su comportamiento: (1) su presición y (2) su desempeño por periodos prolongados de sumersión en medio acuático ('sensor drift').

Para esto se utilizó baldes de agua en condicinoes controladas que simulan las condiciones en un acuífero y un sistema de captura de datos para luego procesarlos.

a title

El resumen de los experimentos actuales puede verse en la siguiente tabla:

| Variable | Estado | Comentario |
| --- | --- | --- |
| Temperatura | ✅ Aprobado para proseguir experimentos | Operación dentro de lo esperado. Error menor a 0.5 ºC y buen desempeño en sumersión continua |
| Presión | ✅ Aprobado para proseguir experimentos | Operación dentro de lo esperado. Error menor a 1cm y buen desempeño en sumersión continua |
| pH | ✅ Aprobado para proseguir experimentos | Operación dentro de lo esperado. Error menor a 1 y buen desempeño en sumersión continua |
| Conductividad Eléctrica | ⚠️ En evaluación | Buena calidad de medición pero presentó problemas en sumersión continua. Se realizarán nuevos experimentos |
| Turbiedad | ❌ Reprobado | Error muy alto (mayor a 1000 TPU) y sensor muy sensible a variables externas |

#### Notas

Algunos comentarios sobre los diferentes sensores:
##### - Temperatura:

a title

Experimentos demostraron un buen desempeño del sensor en su comportamiento en el tiempo. Algunas observaciones:

- Comportamiento muy predecible, después de un tiempo se puede observar una muy leve desviación lineal constante de la medidas, pero se puede corregir completamente reajustando un offset.
- Errores menores a 0.5ºC luego de 2 meses  de uso prolongado sin recalibrar. Luego de 9 meses de uso error en mediciones aumento pero se mantiene menor a los 0.5ºC al recalibrar. 

a title

##### - Conductividad:

a title

Algunas observaciones:
- Al medir dos al mismo tiempo se afectan la medida.
- Es súper clara la medición dentro del rango de 0-1500 uS/cm.
    - Al medir hasta 1500 uS/cm errores se mantienen bajo los 50 uS/cm. Al medir hasta 2000 uS/cm error medio se mantiene entre 100-200 uS/cm.
- Luego de 3 meses de uso continuo, sensor pierde su calibración Se esperan más experimentos para ver si es por depositos de minerales en el sensor, o si es corregible, o fue un error puntual, o etc.
- No se ve histéresis importante.

##### - pH:

a title

- No se ve mucha histéresis. Hay harta variación en la calibración pero al recalibrar los sensores vuelven a funcionar.
- Se esperar hacer más experimento para corroborar datos y además poder ir estimando que tan rápido se descalibran los datos, y cuánto se va perdiendo de presición con cada recalibración.

##### - Nivel de Agua:

a title
a title

- Para medir el nivel de una columna de agua se usan dos sensores: uno en el fondo del pozo y otro en la superficie para corregir las variaciones en la presión atmosférica que también siente el sensor sumergido. 
- Experimentos fueron positivos, el error de medición fue menor a 1 cm en diferentes experimentos y luego de 3 meses de medición continua equipo sigue midiendo correctamente, no se observa desviación en su medición.

a title
a title
a title

##### - Turbidez:

a title

- Sensores son muy sensibles a la luz, entonces mediciones varían ampliamente dependiendo de la luz ambiente y la posición en que se coloquen, cualquier movivmiento o cambio de alguna de estas condiciones afectará la medición.
- Errores del rango de ~1000 NTU. No confiables, quizás solo apra alertas grandes pero mejor seguir buscando.

<!--
## Aprendizajes
- tener un buen setup del experimento
-->

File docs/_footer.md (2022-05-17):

<div style='opacity: 0.75; border-top: 1px dashed #9f9f9f;'>

## Licencia

Licencia :size=200

CC BY-NC-SA 4.0

**Attribution-NonCommercial_ShareAlike 4.0 International**

Open Water: Fondef IDeA ID19I10363 © 2022 by Universidad de Chile is licensed under CC BY-NC-SA 4.0. To view a copy of this license, visit http://creativecommons.org/licenses/by-nc-sa/4.0/

This license requires that reusers give credit to the creator. It allows reusers to distribute, remix, adapt, and build upon the material in any medium or format, for noncommercial purposes only. If others modify or adapt the material, they must license the modified material under identical terms.

</div>

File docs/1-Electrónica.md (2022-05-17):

# 💻 Electrónica

Primeras versiones 2 del sistema de captura de datos tenían el objetivo de ser utilizados para realizar los experimentos con los sensores y prototipar primeras versiones de la electrónica que se sumergiría en el agua.

Las funcionalidad de ambos es casi la misma: leer sensores ambientales, almacenar datos temporales. Para el caso del prototipo a sumergir en los acuíferos la información además debe ser comunicada al exterior y debe poder funcionar de manera autónoma por semanas a las vez.

a title

Como resultados iniciales se tiene un nodo sensor capaz de obtener medidas, guardar estos datos en una microSD y además enviar estos datos de manera serial siendo un prototipo inicial lo suficientemente útil para la realización de pruebas en profundidad y analizar las limitaciones de los sensores bajo condiciones en profundidad controlada.

a title

Junto a la electrónica anterior, se trabajó en la integración de todos los componentes en una PCB. Esta nueva placa debe tener el tamaño y funcionalidades suficientes para ser sumergida junto a la carcasa diseñada (más información en XXXX).

Se agregan dos nuevas funcionalidades:
1. **Fuente energética con baterías:** Agregar al nodo baterías de litio 18650 con toda su electrónica para un correcto funcionamiento (cargadores y elevadores).
2. **Distribución energética de componentes:** Dividir la fuente de energía en una que apaga los sensores cuando no están midiendo para reducir el consumo.

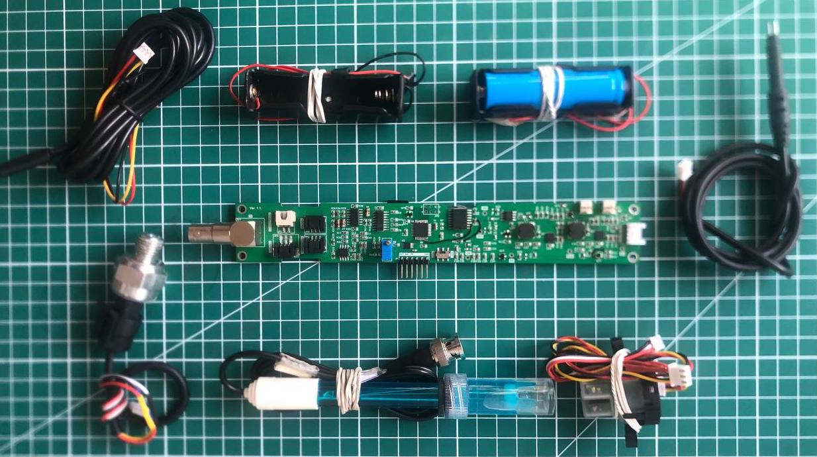
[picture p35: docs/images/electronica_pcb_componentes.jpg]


Se reviso factibilidad y detalles del proceso para fabricación de la placa, se vieron dos opciones principales:

1. Opción Externa: Fabricar y ensamblar en el extranjero
2. Opción Local: Fabricar placa en el extranjero y ensamblar componentes localmente.

<!-- La segunda opción implica hacer el trabajo de comprar todos los componentes de la placa y soldarlos. Sus ventajas son la posible reutilización de componentes dificiles de encontrar desde la electrónica original de los sensores y una consecuente optimización de costos. -->

Ambas opciones tiene un costo cercano a los 200 dolares americanos por placa. Puede ser importante evaluar la disponibilidad de componentes para decidir por una opción.

**Importante:** Considerar además un precio extra en cuando a sensores y baterías del dispositivo de $100.92USD/unidad aprox.

<!--
| Cotizaciones  | **Total (5u)** | **Total+ 30%*** | **Precio unitario USD** | **Tiempo**  |
|---|---|---|---|---|
| **Opción Local** | $772.09 | $1003.72 | $200.74 | 3-4 semanas |
| **Opción Externa EEcart** | $907.26 | $1179.44 | $235.89 | 5 semanas |
| **Opción Externa PCBWay** | $888.45 | $1176.19 | $231.00 | 5.5 semanas |
-->

## Uso y programación

a title

Para utilizar la placa considerar:

- Componentes externos
    - Baterías 18650
    - Tarjeta SD
    - Pila Reloj
- Para programar
    - Cable de energía
    - Cable de programación (FTDI)
- Sensores

Para programar la placa esta debe estar **siempre alimentada**:

6. Conectar un **adaptador FTDI-USB** para su programación en el puerto FTDI y un adaptador RS485-USB si se realiza esta comunicación en la salida 485 de la PCB.
5. Dejar el **interruptor en FTDI** (se encuentra al lado de conexión a programador).
7. Conectar **solo** el adaptador USB-FTDI al computador para pruebas.

La programación se realiza en Arduino IDE y el programa se encuentra en el siguiente [enlace](https://github.com/niclabs/water-monitoring/tree/master/6.%20Electr%C3%B3nica/PCB-MCI/Codigo_Final).

8. Seleccionar **el puerto** de conexión correspondiente en la pestaña herramientas.
9. Seleccionar  **Arduino Uno** en la pestaña herramientas.
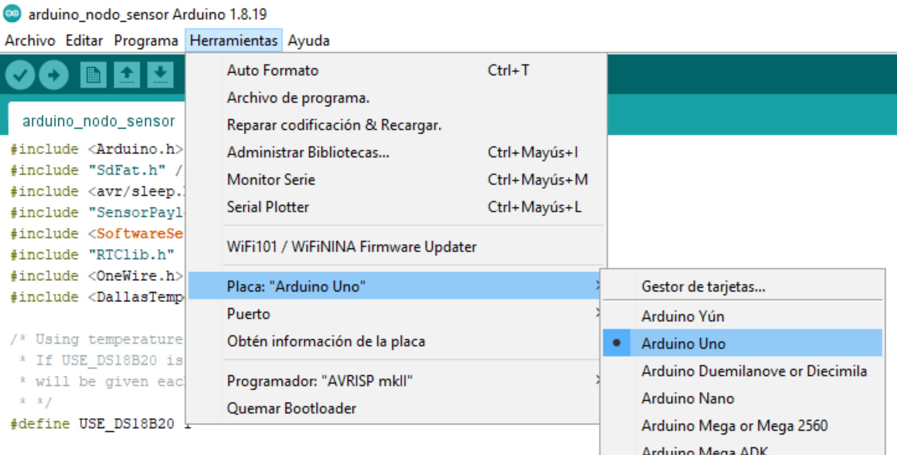
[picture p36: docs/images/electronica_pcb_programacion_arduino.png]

10. Cargar el código correspondiente.

Para realizar cambios en el código o generar uno propio se tiene:
1. Considerar el dispositivo como un **Arduino Uno**.
2. Importante habilitar el pin D3(alimentación) para la iniciar la SD.

Conexiones:

3. El **pin D2** es entrada asociada a la señal de interrupción del **RTC**.
4. El **pin D3** es salida y habilita la **Alimentación 5Vs**.
5. El **pin D4** es salida y habilita el **RS485** para que trabaje (Receptor y Emisor).
6. El **pin D9** es entrada con la señal del sensor de **temperatura** (1-wire).
7. **PC4 y PC5** conexión I2C proveniente del **ADC** que contiene los sensores de presión, turbidez, conductividad y pH.
8. La **SD** tiene una conexión **ISCP (pin 10-13)**.

## Oportunidades de mejora

#### To Do's

1. Disminuir costo de fabricación.
2. Mejorar autonomía del sistema.

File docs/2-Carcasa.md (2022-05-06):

# 📦 Carcasa sumergible

Revisaremos el diseño y construcción de una carcasa incorporada al nodo sensor con factibilidad de ser desplegada en aguas superficiales y subterráneas. Se han realizado pruebas en ambiente controlado (laboratorio) sumergiendo la carcasa en tanques de agua por diferentes períodos de tiempo y evaluando efectividad en la protección del interior de acuerdo al grado de protección IP alcanzado (norma internacional CEI 60529 Degrees of Protection).

Se fabricó un primer prototipo para realizar pruebas con los sensores de presión (nivel de agua) para sumergirlos en un pozo de unos ~5 metros. Se usaron materiales de plomería genéricos y se rellenó con arroz para absorver la humedad en caso de filtraciones.

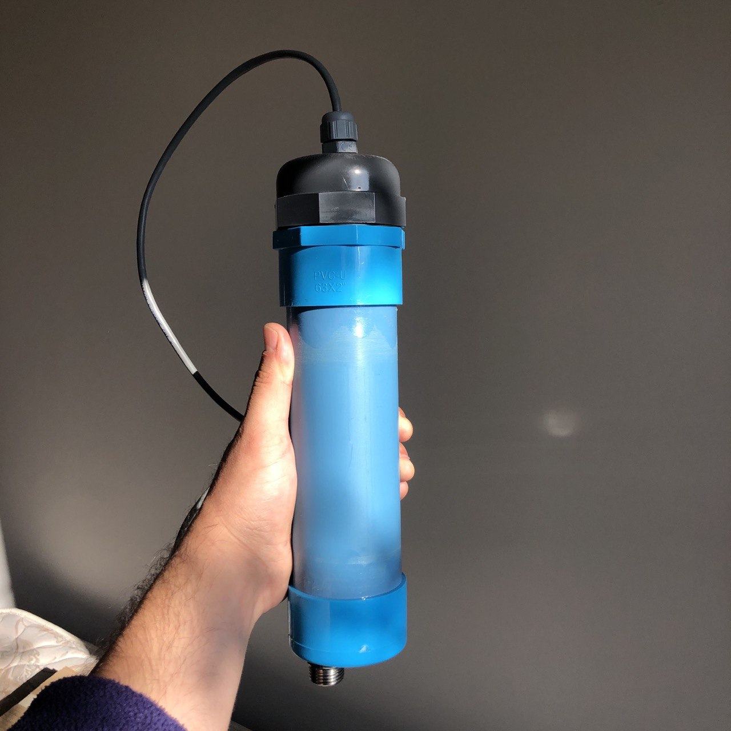
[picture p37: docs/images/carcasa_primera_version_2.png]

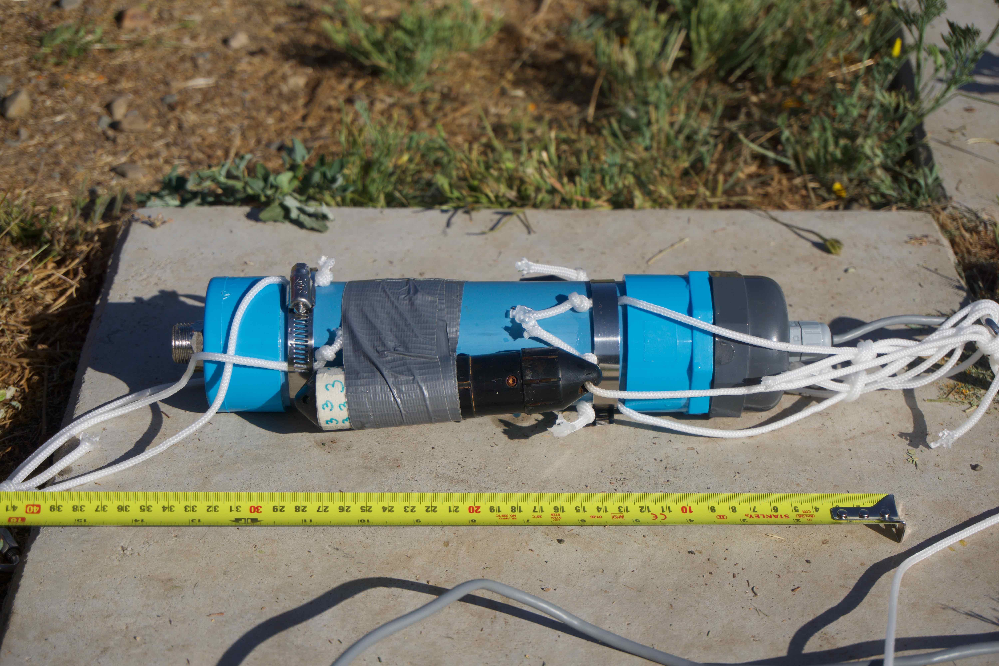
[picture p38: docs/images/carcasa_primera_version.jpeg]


Este prototipo estuvo sumergido unos 45 minutos y al sacarlo si tenía bastante humedad dentro, pero no tenía un "pozo de agua", la humedad si era suficiente para que en el tiempo dañara la electrónica. Se cree que las filtraciones fueron por las tapas de los sensores de presión.xzx

En la siguiente etapa se comenzó a diseñar a nivel general el dispositivo priorizando materiales accesibles y disponibles en el mercado local. La geometría inicial contempla un tubo de acrílico transparente, tapas y un soporte interno para la electrónica, además de espacios laterales para la salida de los sensores y cable UTP, como se muestra en la Figura 11. Las tapas laterales (Figura 12) realizan el sello total del dispositivo en esta versión, mediante o'rings y fijándose al soporte interno que es lo que mantendrá las tapas a presión dentro del sistema generando la protección deseada IP69.

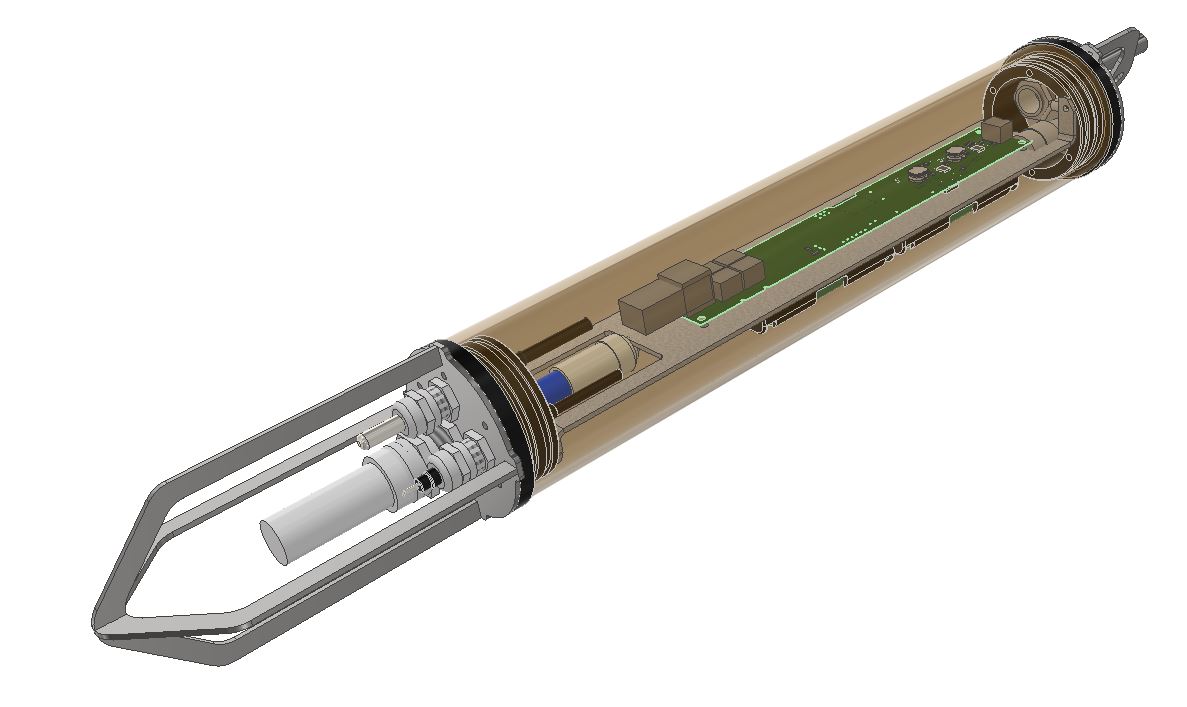
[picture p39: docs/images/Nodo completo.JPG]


El sistema se prototipo y se realizaron diferentes pruebas a  los componentes de sello de los sensores y el equipos completo en un tubo de pvc de 6 metros.

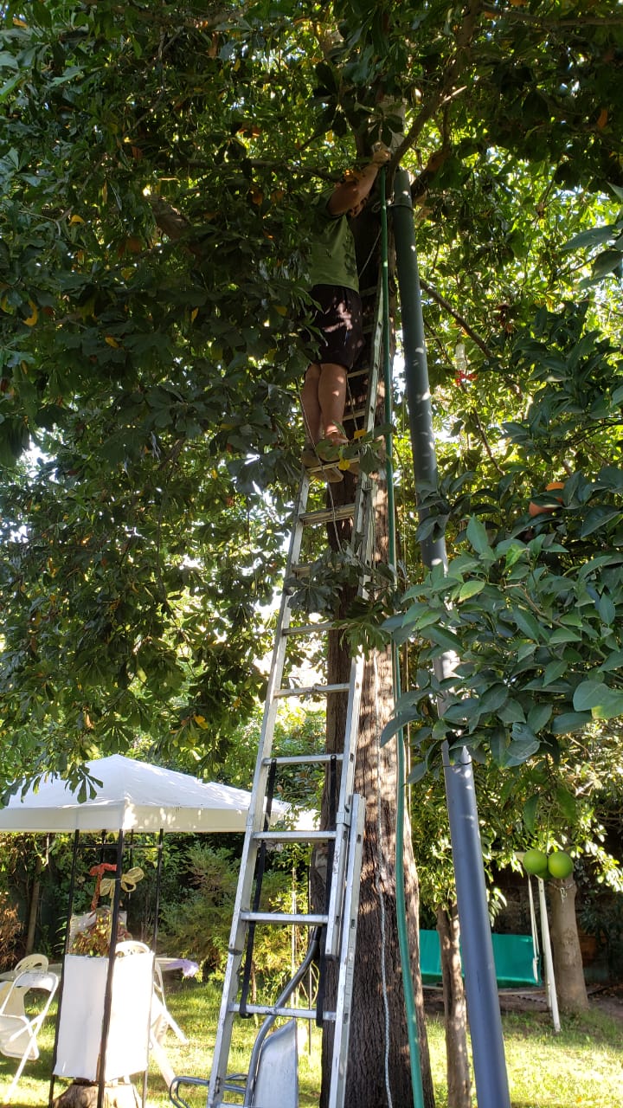
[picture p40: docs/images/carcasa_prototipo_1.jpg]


Se fueron ajustando partes hasta que no hubo filtraciones. :)

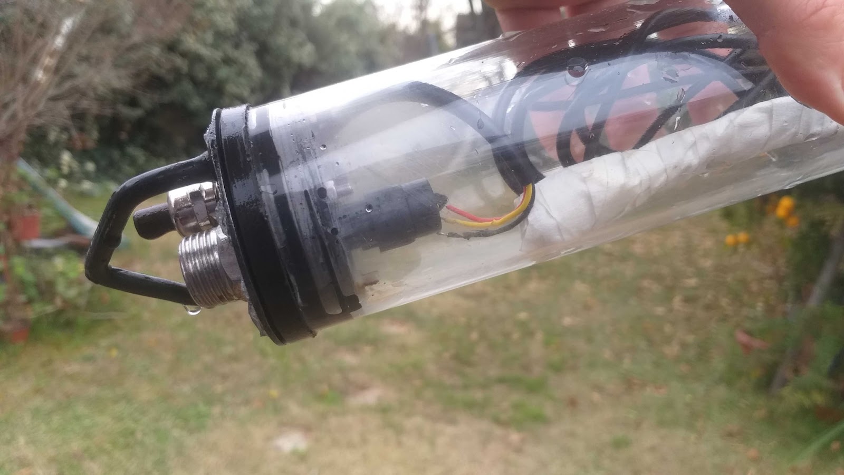
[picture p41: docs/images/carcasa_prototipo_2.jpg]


Se probó este ptototipo luego en un pozo en el sector de Laguna Caren, aquí se realizaron pruebas sumergiendolo a mayores profundidades progresivamente (10, 20, 30 y 40mt).

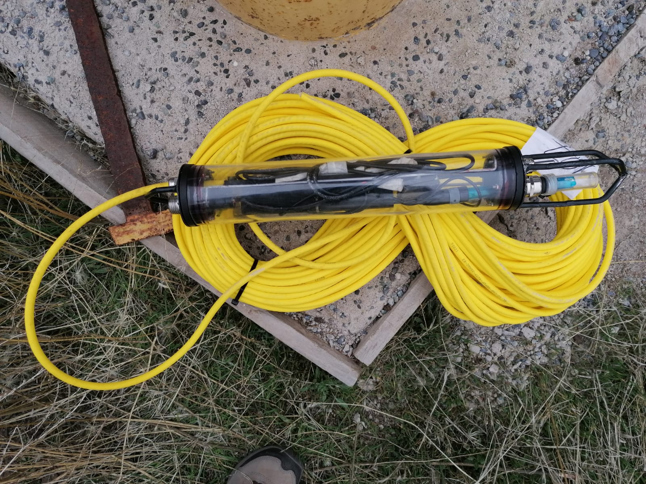
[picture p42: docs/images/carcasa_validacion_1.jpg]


Hubo de todos los resultados, positivos donde el permanecio sumergido sin filtraciones y también con filtraciones. Se observan algunos casos de carcasa con filtraciones más abajo.

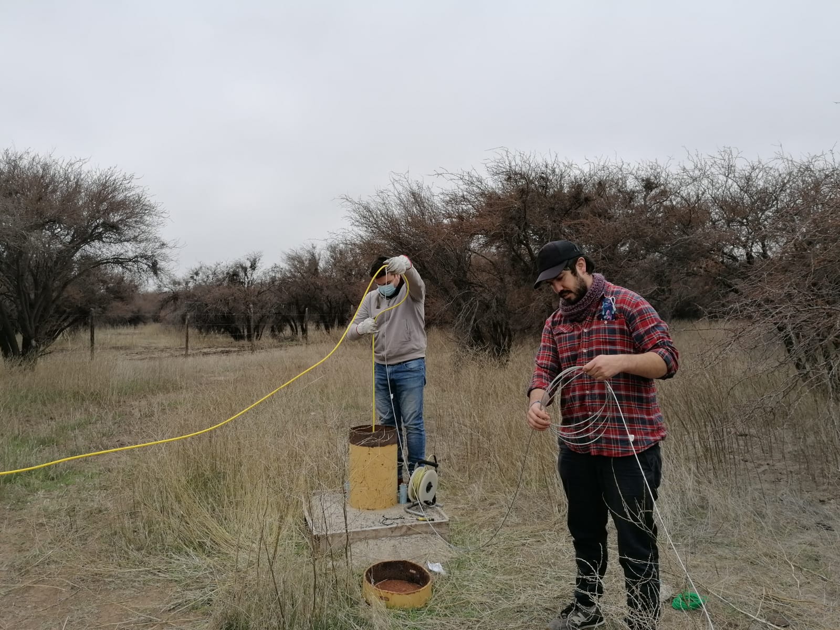
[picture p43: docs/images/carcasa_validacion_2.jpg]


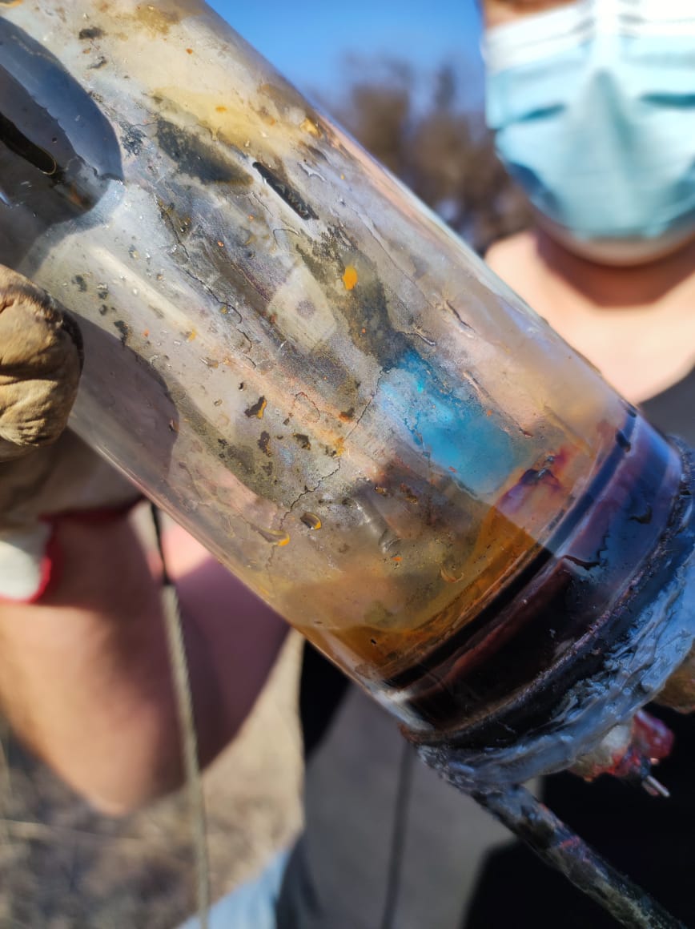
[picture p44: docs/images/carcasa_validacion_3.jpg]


### Archivos de diseño y fabricación

Se pueden encontrar los archivos de diseño, materiales e instrucciones en el siguiente link.

https://github.com/niclabs/water-monitoring/tree/master/5.%20Hito%20Carcasa

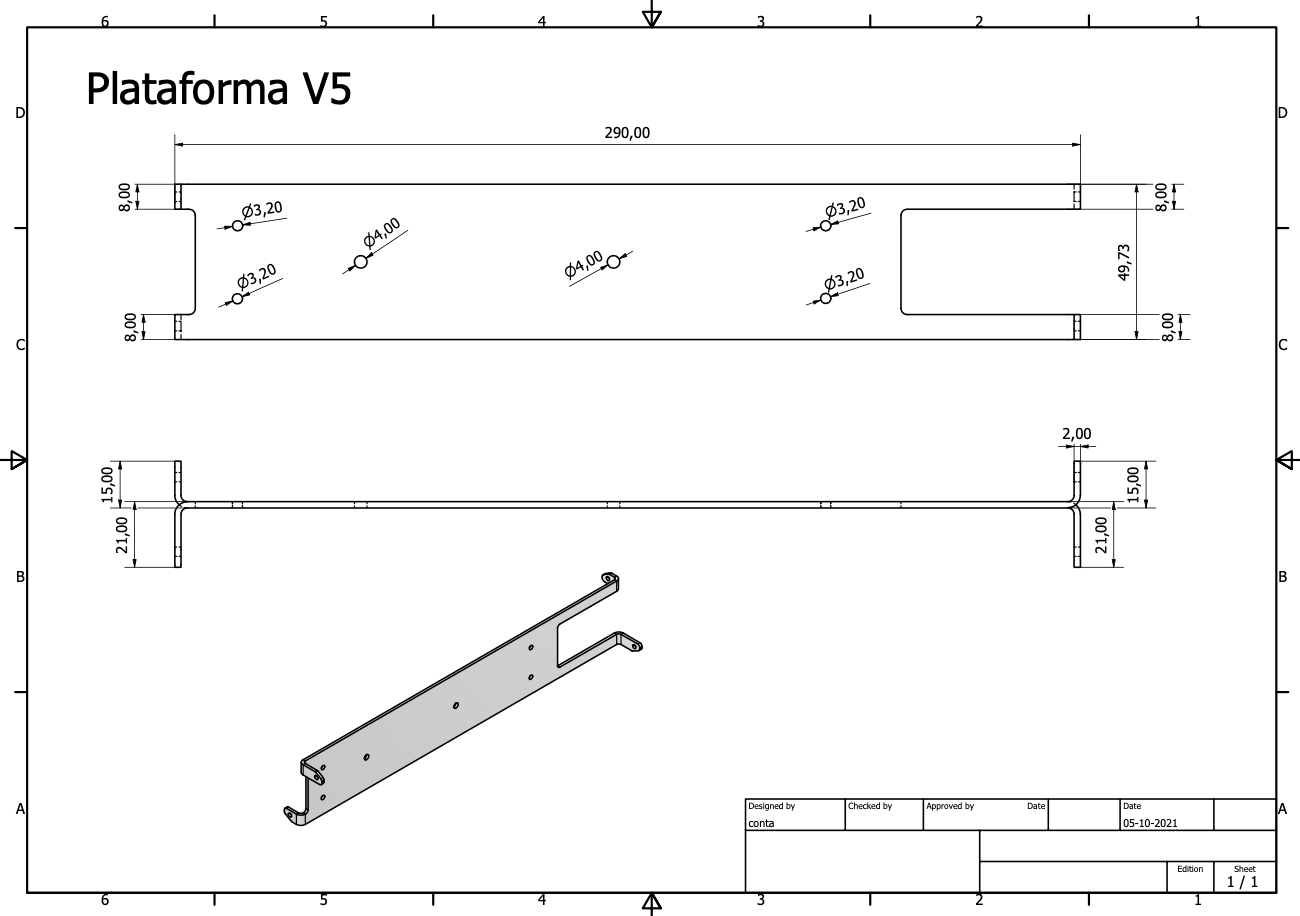
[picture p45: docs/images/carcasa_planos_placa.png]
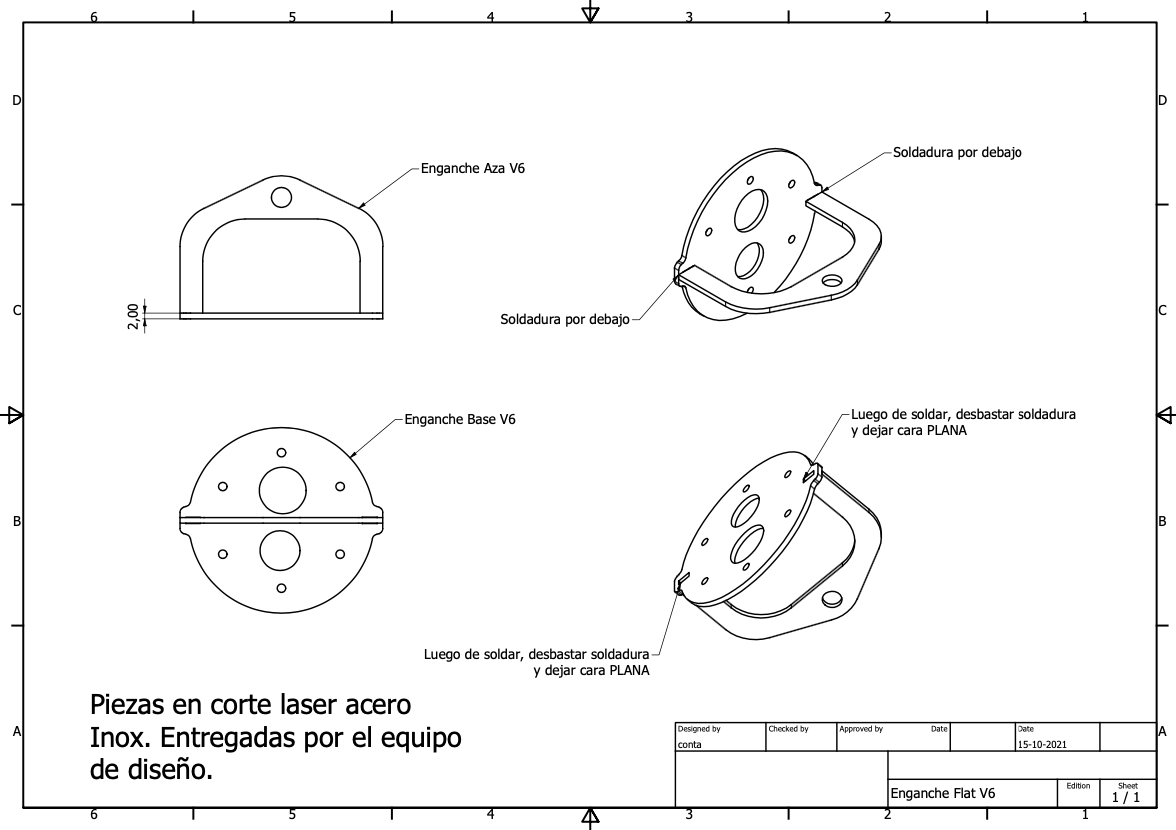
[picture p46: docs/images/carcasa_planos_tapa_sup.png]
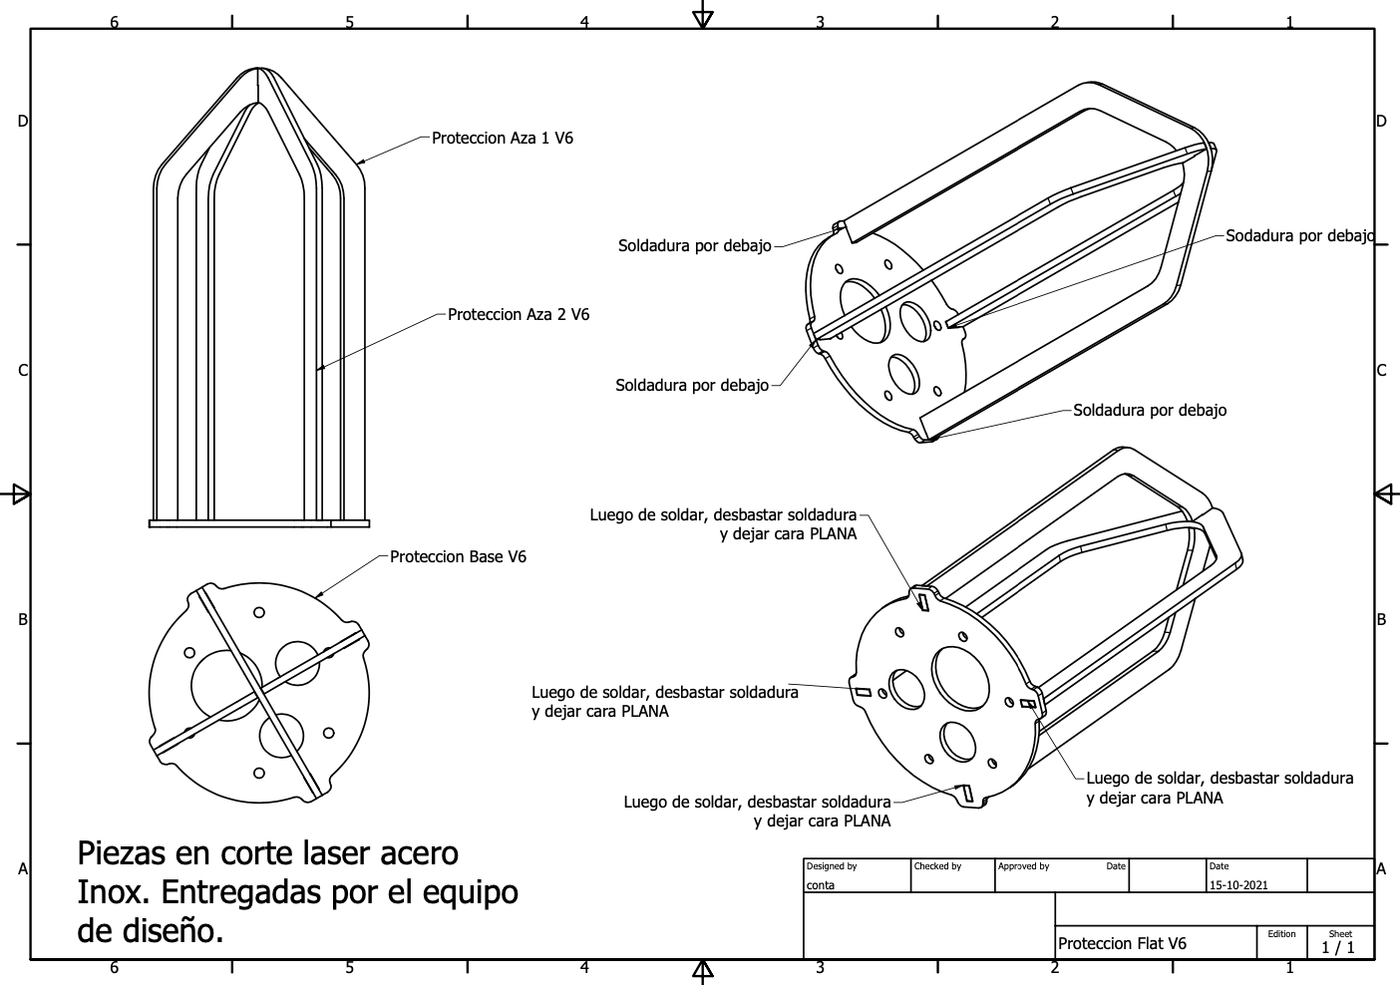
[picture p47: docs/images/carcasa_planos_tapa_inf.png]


## Siguientes pasos

Se puede ordenar el trabajo futuro en dos categorías dependiendo de su objetivo:

##### To Do's:

1. Disminución de costo de materiales.
2. Estandarización de proceso de fabricación.

##### To Fix:

1. Revisar mecanismo de sellado y filtraciones.

<!--

- mayores dificultades, tipos de pruebas, desafíos.

Diseño final y partes

## Instrucciones armado

Manual (Adjunto)

## Resultados pruebas

Método de las pruebas

pruebas en tubo rancagua

pruebas en terreno

pruebas antes de llevar a terreno

Resumen de resultados y roadmap siguiente.

Comparación de costos cable vs cable nosotros.

- Tips
- Consejos
- Desafíos

Aprendizajes.

-->

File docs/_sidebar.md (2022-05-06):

- [💧 Homepage](/)
- [🌡 Sensores](0-Sensores.md)
- [💻 Electrónica](1-Electrónica.md)
- [📦 Carcasa](2-Carcasa.md)
- [📡 Comunicación Inalámbrica](3-Comunicación-inalámbrica.md)
- [🤖 Sistema Experto](4-Sistema%20Experto.md)

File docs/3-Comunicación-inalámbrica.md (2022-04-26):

# 📡 Comunicación Inalámbrica

## Introducción
La figura 1 muestra el diagrama completo de conectividad de la solución. El sistema de comunicación a implementar utiliza un medio guiado para la comunicación entre el módulo de captura, ubicado en el fondo de la masa de agua y el módulo de comunicación, ubicado en la superficie. Se utiliza la tecnología LoRaWAN para la transmisión de datos entre el módulo de comunicación y el network server. Finalmente la comunicación entre el Network Server y el Sistema Experto es a través de tecnología Web utilizando el protocolo HTTP. Los datos de los sensores son almacenados en una Base de Datos para ser posteriormente procesados por el sistema experto.

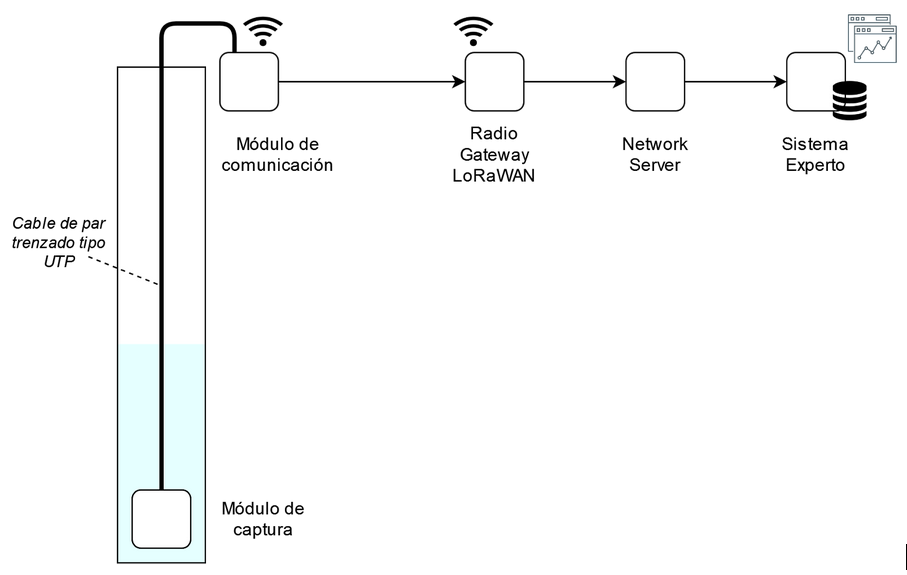
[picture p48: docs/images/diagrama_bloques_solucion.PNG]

Figura 1. Diagrama de bloques de la solución

## Nodo Sensor
### Módulo de Captura
El módulo de captura está compuesto por cuatro elementos:

 * Transductores (Presión, pH, Turbidez, Temperatura y Conductividad Eléctrica): Estos elementos son los encargados de convertir una medida física a una corriente o voltaje interpretable por un circuito electrónico.
 * Placa Electrónica o PCB: encargada del procesamiento de la información además del envío de ella hacia el módulo de comunicación ubicado en la superficie. Este módulo además cuenta con un reloj encargado de marcar las muestras con la hora de su captura.
 * Cable de par trenzado. Este cable es el encargado de transportar los datos entre el módulo de captura y el módulo de comunicación. Para ello se utiliza un cable UTP dentro de una manguera para evitar su corrosión.
 * Carcasa sumergible: Encargada de dar la protección necesaria para poder sumergir todos los elementos anteriores.

La figura 2 muestra una imagen de la placa electrónica y los transductores antes de ser ensamblados dentro de la carcasa sumergible. Esta placa incluye las funcionalidades de captura de datos de los transductores, envío de cada muestra hacia el módulo de comunicación. Cada muestra es estampada con la hora de captura más un indicativo del transductor que obtuvo la muestra.

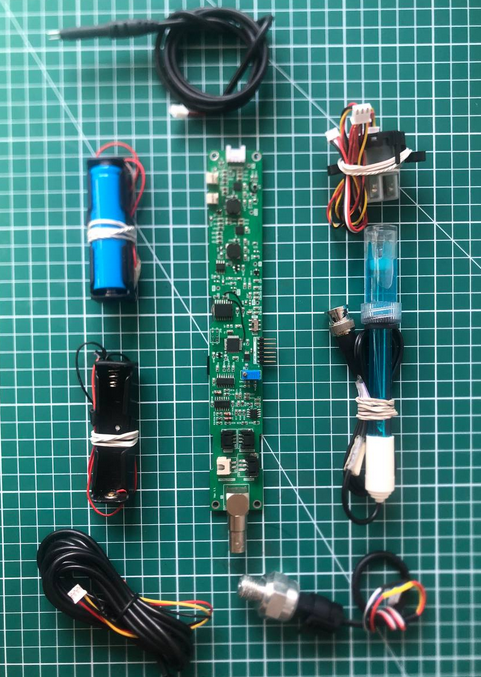
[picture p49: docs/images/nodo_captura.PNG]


Figura 2. Placa Electrónica junto a los transductores

El envío de datos desde el módulo de captura al módulo de comunicación es a través del protocolo serie RS485. Para ello ambos módulos cuentan con un conversor de protocolo de comunicación UART a RS485 como muestra la figura 3. El medio físico que une ambos módulos es un cable de par trenzado del tipo UTP (unshielded twisted pair). Para poder resistir el agua, el cable es recubierto con una manguera flexible (ver figura 4). En los extremos se utiliza un mecanismo para introducirlo a la carcasa sumergible.

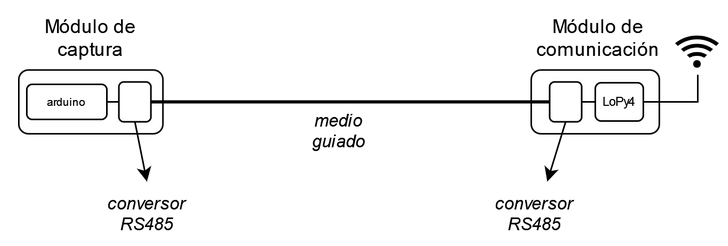
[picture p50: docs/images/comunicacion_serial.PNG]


Figura 3. Diagrama de bloques para la comunicación entre módulos en el nodo sensor

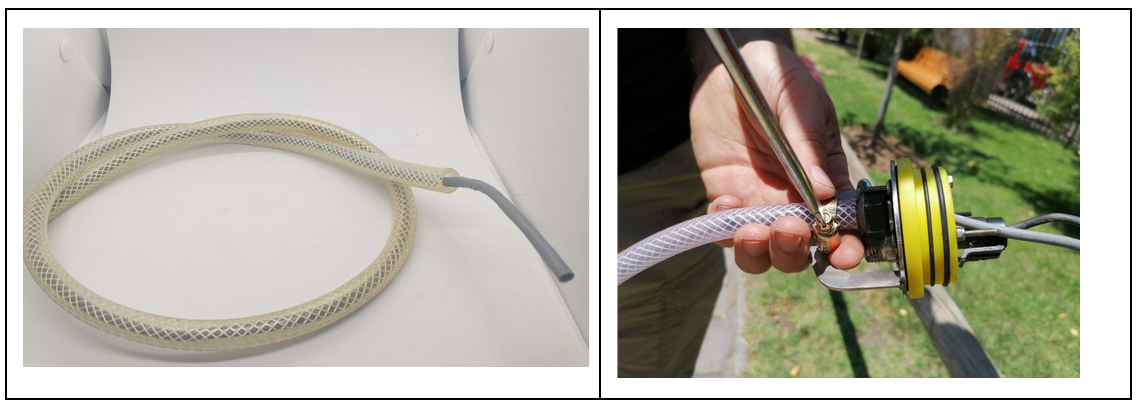
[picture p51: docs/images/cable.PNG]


Figura 4. Cable de datos UTP para la comunicación entre el módulo de captura y el módulo de comunicaciones.

La figura 5 muestra la carcasa sumergible. La carcasa está compuesta por un tubo central de acrílico de 3 pulgadas de diámetro interior y espesor de 3 mm, más dos piezas de ajuste (con sus respectivas tapas) y 3 o'rings de sellado. Las piezas que reciben los orings se han realizado en un proceso de torneado de Technyl debido a su universalidad, las tapas por otro lado, se han cortado en un proceso láser cnc por su bajo coste y precisión.

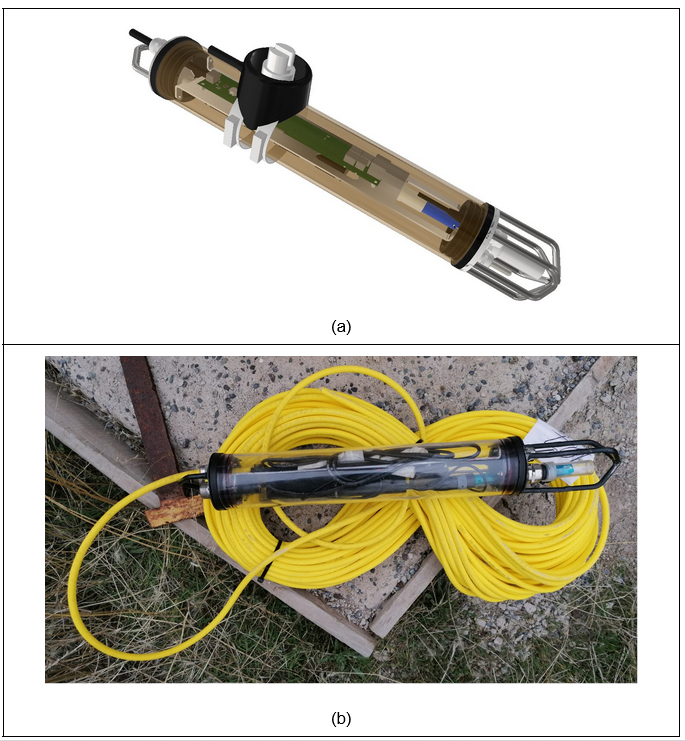
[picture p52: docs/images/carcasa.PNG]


figura 5. Carcasa Sumergible. (a) imagen renderizada de la carcasa 3D completa, con el anclaje, sensores y placa electrónica. (b) Fotografía de la carcasa con anclaje y sensores.

### Módulo de Comunicación

El módulo de comunicación está compuesto por 2 elementos:

 * submódulo LoPy4: encargado del procesamiento de la información serial proveniente del módulo de captura. Además tiene la responsabilidad de enviar las medidas a través del canal inalámbrico utilizando tecnología LoRaWAN.
 * submódulo RS-485: encargado de convertir la comunicación serial RS-485 proveniente del módulo de captura a estándar UART para que pueda ser procesada por el submódulo LoPy4.

Para poder realizar la implementación se considera el diagrama de una red LPWA (Low Power Wide Area) definida en *[1]*, el cual considera cuatro bloques: End-Nodes, Concentrado/Gateway, Network Server y Application Server tal como lo muestra la figura 6. El módulo de comunicación del nodo sensor representa a un End-Node en la arquitectura LPWA.

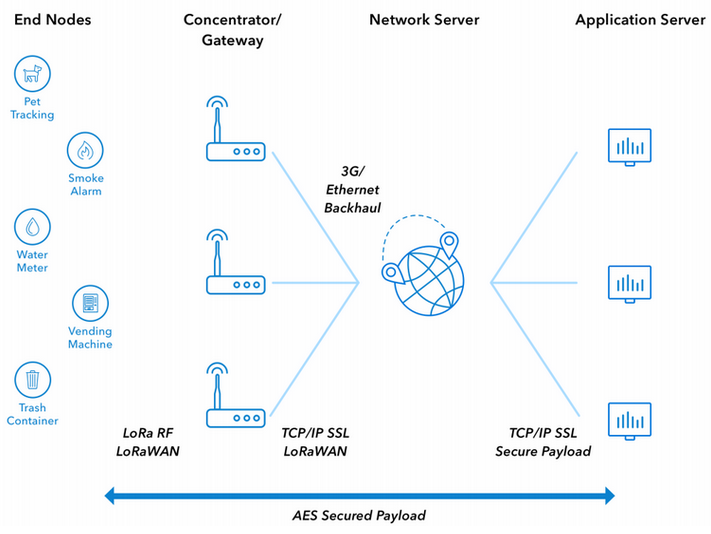
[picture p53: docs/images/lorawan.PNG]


Figura 6. Arquitectura LoRaWAN. Tomada de [1].

El nodo LoPy4 es una placa de desarrollo que soporta cuatro tipos de red (LoRa, Sigfox, WiFi, Bluetooth). Además implementa MicroPython, una versión eficiente del lenguaje de programación Python 3 que incluye un pequeño subconjunto de la biblioteca estándar de Python y está optimizado para ejecutarse en microcontroladores y en entornos restringidos, como el microcontrolador ESP32. La figura 7 muestra el módulo de comunicación antes de ser ensamblado. La figura 8 muestra el módulo de comunicación ensamblado.

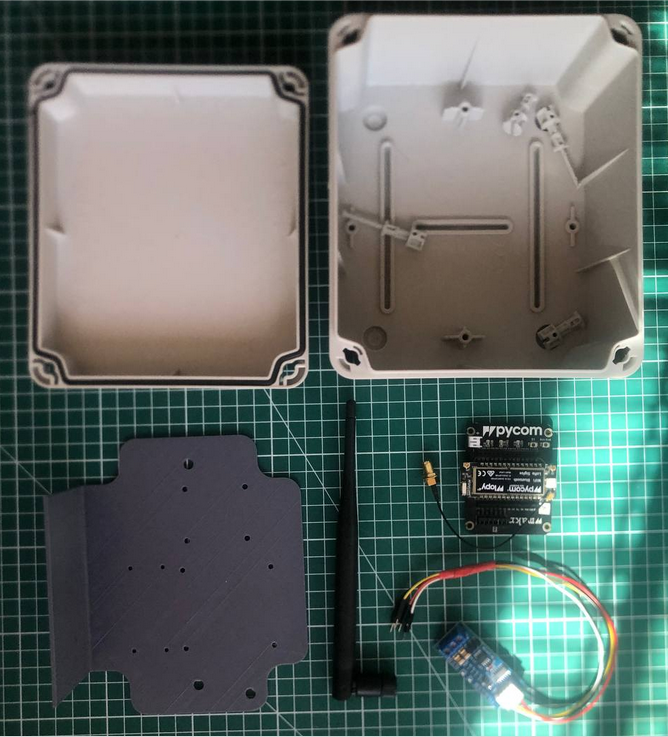
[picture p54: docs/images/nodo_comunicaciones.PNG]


Figura 7. Módulo de Comunicaciones con todas sus partes (antes de ser ensamblado)

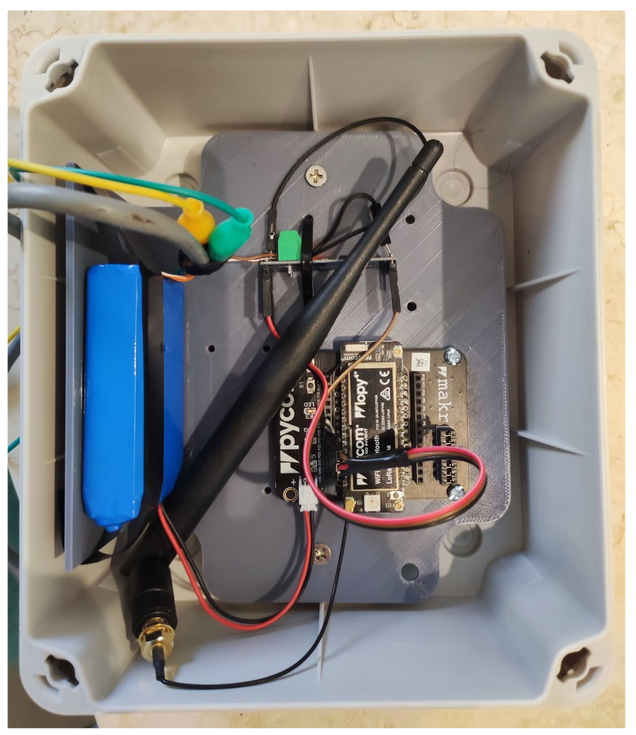
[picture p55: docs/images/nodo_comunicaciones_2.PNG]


Figura 8. Módulo de Comunicaciones con todas sus partes (después de ser ensamblado)

## Red LPWA

Como se indicó en la sección anterior, el módulo de comunicación del nodo sensor, cumple el rol de End-node en una red LoRaWAN (ver figura 6). Los otros componentes de la red son implementados de la siguiente manera:

 * El Concentrador o Gateway: este elemento es desplegado utilizando un Radio Gateway marca RAK modelo 7240.
 * El Network Server: es implementado a través del proyecto opensource The Things Network (https://www.thethingsnetwork.org/). Este proyecto permite crear aplicaciones que reciben los mensajes LoRaWAN provenientes desde los End-Nodes y los reenvia hacia un Application Server, que en nuestro caso es el Sistema Experto.

## Sistema Experto
El sistema experto representa al Application Server de una arquitectura LoRaWAN (ver figura 6). Luego que los mensajes LoRaWAN son recibidos por el Network Server, son enviados al Sistema Experto a través de mensajes HTTP. El flujo de mensajes se describe en la figura 9.

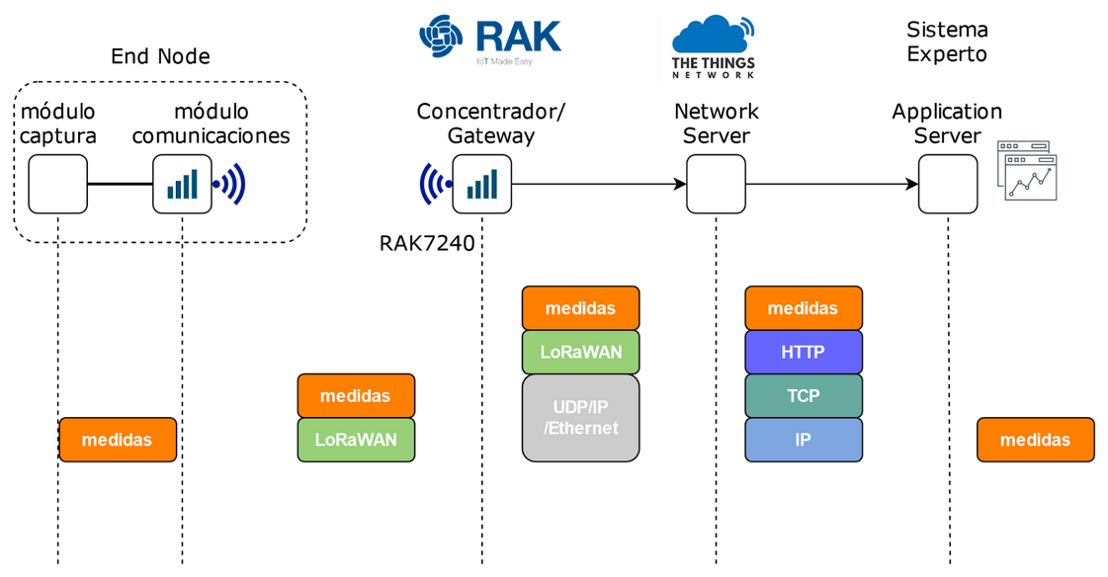
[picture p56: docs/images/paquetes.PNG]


Figura 9. Flujo de mensajes entre el módulo de captura y el Sistema Experto

El sistema experto procesa los mensajes HTTP y extrae las medidas provenientes de un nodo sensor. Luego, por cada medida obtenida, se almacena en la base de datos los siguientes datos:

 * ID del nodo sensor
 * ID del transductor
 * Marca de tiempo en la que se realizó la medida
 * Valor de la medida

----

[1] http://thethingsnetwork.org/docs/lorawan/architecture.html

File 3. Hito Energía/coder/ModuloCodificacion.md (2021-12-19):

# Librería SensorPayload

La librería SensorPayload para Arduino codifica las lecturas de los sensores de los datalogger en arreglos de bytes para ser transmitidos. Las lecturas se empaquetan en Sensing Units y luego se concatenan, generando un payload final con la siguiente estructura:

        SensingUnit1 SensingUnit2 SensingUnit3 ... SensingUnitN

## Sensing Unit

Cada Sensing Unit se conforma como sigue:

| 1 byte | 6 Bytes |
|---|---|
| Unit Header | Payload |

Donde la sección Unit Header está conformada de la siguiente forma:

| 2 bits | 2 bits | 4 bits | 
|---|---|---|
| Coding Info | Reserved  | Sensor ID |

### Coding Info

El campo Coding Info determina la estructura del payload de la Sensing Unit.

| Tipo de Payload | Coding Info |
|---|---|
| Payload Base | 11 |
| Payload Repetido | 10 |
| Payload Diferencial | 01 |

### Sensor ID 

La siguiente tabla determina los ID asociados a los distintos tipos de sensores

| Sensor | Variable a medir | Sensor ID |
|---|---|---|
| DS18B20 | Temperatura | 0000 |
| SHT20 I2C | Temperatura | 0001 |
| Gravity: Analog Water Pressure Sensor | Presión | 0010 |
| Pressure Sensor HK1100C | Presión | 0011 |
| Gravity: Analog pH Sensor/Meter Kit V2 | PH | 0100 |
| Gravity: Analog Electrical Conductivity Meter | Electroconductividad | 0101 |
| Gravity: Analog TDS Sensor/Meter for Arduino | Electroconductividad | 0110 |
| Grove: Turbidity Sensor (Meter) for Arduino V1.0 | Turbidez | 0111 |
| BMP280 Barometric Pressure Sensor | Presión | 1000 |

## Payload Base

La estructura del Payload Base considera 6 bytes en total, divididos en dos secciones:

| 4 bytes | 2 bytes |
|---|---|
| Timestamp | Sensed Value |

* Timestamp: tiempo Unix que determina la fecha y hora, con precisión de segundos, donde se realizó una medida.
* Sensed Value: valor entero con signo entre -32767 y 32767 que representa un número real con precisión de un decimal. Así por ejemplo, el número 2354 se interpreta como 235.4

## Payload Repetido

Un Payload Repetido se genera cuando existen tres o más lecturas de datos sucesivas que reportan un mismo valor de senseo. Cuando esto ocurre, se codifica una primera Sensing Unit con Payload Base, pero con cabecera de Payload Repetido (Coding Info = 10). A continuación le procede un Sensing Unit con cabecera de Payload Repetido y un payload de 6 bytes con la siguiente estructura:

| 2 bytes | 4 bytes |
|---|---|
| Time interval | Number of Values |

* Time interval: Intervalo de tiempo, en segundos, entre las medidas repetidas.
* Number of values: Cantidad de veces que debe repetirse el valor repetido del Sensing Unit que le antecede.

De esta manera, para la transmisión de un Payload Repetido, serán necesarios 14 bytes contiguos que sigan la siguiente estructura:

| 1 byte | 4 bytes | 2 bytes | 1 byte | 2 bytes | 4 bytes |
|---|---|---|---|---|---|
| Unit Header | Timestamp | Sensed Value | Unit Header | Time interval | Number of Values |
^                                        ^
10                                       10

## Payload Diferencial

Un Payload Diferencial es una estructura que representa paquetes de datos a partir de diferencias numéricas con respecto a un Payload Base de referencia. Para clarificar esto, se define un conjunto de tres muestras para un mismo sensor con los siguientes valores:

        Muestras = [(sensor: 1, timestamp: 333333333, value: 27.8),
                    (sensor: 1, timestamp: 333333345, value: 29.3),
                    (sensor: 1, timestamp: 333333357, value: 27.5)]

Las últimas dos muestras pueden representarse de manera diferencial con respecto a la primera muestra, mostrando solamente las diferencias numéricas de los valores alojados en los campos timestamp y value, quedando la nueva representacion de la siguiente manera:

        Muestras_Dif = [(sensor: 1, timestamp: 333333333, value: 27.8),
                        (sensor: 1, d_timestamp: +12, d_value: +1.5),
                        (sensor: 1, d_timestamp: +24, d_value: -0.3)]

Considerando lo anterior, se define un Payload Diferencial de 6 bytes con la siguiente estructura:

| 2 bytes | 1 byte | 2 bytes | 1 byte |
|---|---|---|---|
| Dif Timestamp1 | Dif Value1 | Dif Timestamp2 | Dif Value2 |

* Dif Timestamp: valor entre 0 y 65535, representando la diferencia en segundos con respecto a un Payload Base de referencia. La codificación asume que las muestras codificadas están en orden ascendente con respecto al timestamp de cada una.
* Dif Value: valor con signo, entre 127 y -127 que representa la diferencia del valor sensado con respecto a un Payload Base de referencia. El valor además debe interpretarse como un número real con un décimal de precisión. Por ejemplo, el valor 100 debe interpretarse como 10.0, el valor 10 como 1.0 y el valor 1 como 0.1.

Con lo anterior, la transmisión de un Payload Diferencial se efectuará mediante la siguiente estructura de Sensing Units

        SensingUnitBase SensingUnitDiferencial1 SensingUnitDiferencial2 ... SensingUnitDiferencialN

Donde el SensingUnitBase tendrá en su campo de cabecera Coding Info el valor 01, indicando así su calidad de Payload Base de Referencia para las SensingUnitDiferenciales que le siguen.

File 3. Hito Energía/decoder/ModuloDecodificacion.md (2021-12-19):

# Librería PayloadDecoder

La siguiente librería decodifica una cadena de bytes proveniente de un nodo sensor

# Modo de uso

```python
import payloadDecoder as pd

base64_string = '8F+SrMMA8g==' #Input del decoder
readings = pd.decode_payload(base64_string)
print(readings)
```

## Funcionamiento

El decodificador asume la entrada de un string codificado en base64, representando una cadena de N bytes:

		b1b2b3...bN

el cual puede interpretarse como una secuencia de M unidades de senseo concatenadas de la forma:

		s1s2s3...sM

donde cada unidad de senseo está definida por los dos primeros bits que la componen. De esta manera, la decodificación se realiza con una determinada estrategia de decodificación, dependiendo de estos bits.

## Estructura general de un Sensing Unit o Unidad de Senseo:

La estructura a nivel de bytes de una unidad de Senseo es la siguiente:

| 1 byte | 6 bytes |
|---|---|
| Unit Header | Payload |

donde el campo Payload sigue una estructura dependiendo de la información presente en el campo Unit Header. Por su parte, el campo Unit Header presenta la siguiente estructura en bits:

| 2 bits | 2 bits | 4 bits | 
|---|---|---|
| Coding Info | Reserved  | Sensor ID |

* Coding Info: valor que determina el tipo de formato que tendrá el Payload adjunto
* Reserved: bits reservados, deben tener el valor 11 siempre
* Sensor ID: ID del sensor que realizó la medición

## Estrategias de decodificación

### Definición previa:

Llamaremos **lectura** a una tupla de tres elementos numéricos con la siguiente forma (sensor_id, timestamp, value). La lectura representa un valor medido por el sensor identificado por *sensor_id*, en el tiempo *timestamp* con una magnitud de *value*.

### Decodificación base

La decodificación se realiza cuando los dos primeros bits de una Sensing Unit son 11. La estructura a decodificar es la siguiente:

| 1 byte | 4 bytes | 2 bytes | 1 byte | 2 bytes | 4 bytes |
|---|---|---|---|---|---|
| Unit Header | Timestamp | Sensed Value | Unit Header | Time interval | Number of Values |

donde la sección Unit Header contiene los siguientes campos:

| 2 bits | 2 bits | 4 bits | 
|---|---|---|
| Coding Info | Reserved  | Sensor ID |

siendo Coding Info la secuencia 11 en bits y Sensor ID el ID del sensor que realizó la lectura.

Luego de la decodificación, se entrega una lectura, con los valores respectivos presentes en la Sensing Unit.

### Decodificación repetida

La decodificación se realiza cuando los dos primeros bits de una Sensing Unit son 10. Cuando esto ocurre, se decodifican 14 bytes con la siguiente estructura:

| 1 byte | 4 bytes | 2 bytes | 1 byte | 2 bytes | 4 bytes |
|---|---|---|---|---|---|
| Unit Header | Timestamp | Sensed Value | Unit Header | Time interval | Number of Values |

cumpliéndose que ambos campos Unit Header almacenan igual Coding Info, con valor binario 10 e igual valor de Sensor ID.

Luego de la decodificación, se entrega una lista de lecturas, conteniendo un total de Number of Values + 1 lecturas en total. Las lecturas generadas consisten en la lectura presente en los primeros 7 bytes y las siguientes Number of Values lecturas se generan añadiendo una suma acumulativa de Time Interval al Timestamp de la primera lectura.

### Decodificación diferencial

Esta decodificación se realiza cuando los dos primeros bits de una Sensing Unit son 01. Cuando esto ocurre, se decodificarán por lo menos 14 bytes, agregando a la decodificación todas las Sensing Units que contengan 01 en su cabecera. La estructura a decodificar es la siguiente:

| 1 byte      | 4 bytes   | 2 bytes      | 1 byte      | 2 bytes        | 1 byte     | 2 bytes        | 1 byte     |...
|-------------|-----------|--------------|-------------|----------------|------------|----------------|------------|...
| Unit Header | Timestamp | Sensed Value | Unit Header | Dif Timestamp1 | Dif Value1 | Dif Timestamp2 | Dif Value2 |...

Luego de la decodificación, se entrega una lista con lecturas. El número de lecturas será igual a (N-7)*2, siendo N el número total de bytes decodificados. Las lecturas dentro del arreglo corresponderán a la lectura alojada en los primeros 7 bytes, la cual será la lectura de referencia, y las lecturas generadas al sumar los valores Dif Timestamp y Dif Value a la lectura de referencia.

## Tabla de sensores

| Sensor | Variable a medir | Sensor ID | Rango | Error  | Resolución |
|---|---|---|---|---|---|
| DS18B20 | Temperatura | 0000 |-10 - 85 °C | ±0.5°C  | 9 bit: 0.5 °C, 10 bit: 0.25°C, 12 bit: 0.0625 °C |
| SHT20 I2C | Temperatura | 0001 |-40 - 125 °C | 0.3% | 14 bit: 0.01 °C |
| Gravity: Analog Water Pressure Sensor | Presión | 0010 | 0 - 1.6 MPa | 0.7% | |
| Pressure Sensor HK1100C | Presión | 0011 | 0 - 1.2 MPa | 1.5% | |
| Gravity: Analog pH Sensor/Meter Kit V2 | PH | 0100 | 0 - 14 | ±0.1 | |
| Gravity: Analog Electrical Conductivity Meter | Electroconductividad | 0101 | 10 - 100 mS/cm | ±5% | |
| Gravity: Analog TDS Sensor/Meter for Arduino | Electroconductividad | 0110 | 0 - 1000 ppm | ±10% | |
| Grove: Turbidity Sensor (Meter) for Arduino V1.0 | Turbidez | 0111 | | | |
| BMP280 Barometric Pressure Sensor | Presión | 1000 | 0.3 - 1.1 MPa  | ±120 Pa | |

## Debugging
El módulo `payloadVerboseDecoder` provee la misma funcionalidad que `payloadDecoder`, pero mostrando la información de cada paquete de datos decodificado.
Para utilizarlo, basta reemplazar la línea
```python
import payloadDecoder as pd
```
por
```python
import payloadVerboseDecoder as pd
```

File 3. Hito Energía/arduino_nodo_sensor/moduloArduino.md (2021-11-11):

# Documentación Arduino Nodo Sensor V1

El siguiente documento tiene por fin explicar el módulo arduino_nodo_sensor.ino, código desarrollado para el módulo Arduino del Nodo 
Sensor. El orden de la información detallada en este documento es congruente con la estructura del código implementado.

## Información general

El código implementado puede dividirse en 4 secciones principales, las cuales respetan el siguiente orden de aparición:

1. Importación de librerías
2. Definición y declaración de variables globales
3. Definición de funciones
4. Funciones setup() y loop() del entorno Arduino.

En las secciones 2 y 3 se utilizan comentarios separadores de la forma "// ------ Nombre Sección --------", con el objetivo de separar el código implementado y detallar su uso. Así, hablaremos de la sección del código Nombre Sección, cuando queramos referirnos al código ubicado desde el separador "// ------ Nombre Sección ------" hasta la aparición del siguiente separador.

## Importación de librerías

En esta sección de código se importan las distintas librerías necesarias para la gestión de los distintos dispositivos conectados al Arduino Nano. Dentro de éstas, destaca la librería "SensorPayload.h", la cual implementa las codificaciones utilizadas para la reducción de consumo energético en el proceso de transmisión inalámbrica.

## Definición y declaración de variables globales

A continuación se detallan las distintas secciones presentes en el código, con explicaciones breves de su uso y finalidad.

### Debug option

Esta sección define una macro DEBUG, la cual se utiliza para condicionar el uso de prints Seriales en el Arduino. Cuando la macro DEBUG toma el valor 1, se definen los métodos debugPrint y debugPrintln, los cuales implementan los métodos Serial.print y Serial.println de Arduino, respectivamente. Cuando la macro DEBUG toma el valor 0, los metodos debugPrint y debugPrintln se definen como vacíos, omitiéndose los prints del programa y ahorrando el espacio en memoria de los strings a imprimir.

Por último, se define la macro ENCODE_MODE, la cual establece el tipo de codificacion que se usará en el proceso de codificación de las lecturas de los sensores. Las opciones disponibles para el valor de esta macro son BASE_MODE, DIF_MODE y REP_MODE, para el caso de las codificaciones base, diferencial y repetición, respectivamente.

### Software Serial port

El Arduino Nano cuenta únicamente con un puerto para comunicación serial, el cual se usa al conectar el dispositivo mediante USB. Por esta razón, se utiliza un puerto Serial por Software en los pines digitales 8 y 9, con el cual se realizan los envíos de información desde el Arduino Nano hacia la LoPy4.

### DS18B20

Se define la macro ONE_WIRE_BUS, la cual establece el pin digital en que estará conectada la salida de datos del sensor  DS18B20. Luego, se definen dos objetos utilizados para la gestión con el sensor.

### SensorPayload

Se define una macro que establece la cantidad máxima de lecturas de 7 bytes que se codificarán antes de ser enviadas. El valor que se utiliza en la implementación es 7, pues al codificar 7 lecturas de 7 bytes cada una se asegura el envío de todos los datos codificados en un paquete LoRa de tamaño mínimo (51 bytes).

### RTC

En esta sección se definen macros y variables asociadas al funcionamiento del módulo RTC y su respectiva rutina de interrupciones.

La macro CLOCK_INTERRUPT_PIN establece el pin digital donde se recibirá la señal de interrupción gatillada por el módulo RTC.

Las macros SENSE_FLAG y SEND_FLAG establecen valores arbitrarios utilizados para diferenciar los eventos de Senseo de Datos y Envío de Datos, gatillados por la rutina de interrupción del RTC.

El objeto rtc se usa para gestionar el módulo RTC a nivel de software, utilizando la librería RTClib.

La variable alarm_time se utiliza para almacenar la hora en la que se ejecutará la siguiente interrupción gatillada por el módulo RTC.

La variable elapsed_time se utiliza para medir el tiempo transcurrido desde el último evento de envío de datos. Se utiliza para configurar las alarmas venideras dentro del sistema.

La variable volatil alarm_flag almacena el evento que debe ejecutarse posterior a una interrupción de reloj.

### LoPy timer

La variable startTime se utiliza para medir el tiempo transcurrido desde que se dio aviso al módulo LoPy4 para comenzar el envío de datos.

### File configuration variables

En esta sección se establecen macros y variables asociadas a la gestion de los archivos a generar dentro de la tarjeta SD.

La macro FILE_BASE_NAME establece el nombre de los archivos a generar, mientras que TMP_FILE_NAME establece el nombre del archivo de trabajo en que se almacenarán temporalmente los datos.

La variable FILE_BLOCK_COUNT establece el número de bloques de 512 bytes que almacenará un archivo.

La variable binName almacena el nombre del último archivo generado en la tarjeta SD. Respeta el patrón "dataXXX.bin", donde XXX es el número de archivo generado. Se inicializa con el valor data000.bin.

El arreglo first_pending_file almacena el primer archivo a ser enviado cuando el evento de envío de datos sea ejecutado. La generación de archivos es secuencial sobre el identificador XXX, por lo que si en este arreglo se almacenan los valores 005, se enviarán los datos desde el archivo data005.bin hasta el último archivo con mayor numeración que esté presente en la tarjeta SD. 

La variable pending_blocks almacena la cantidad de bloques pendientes por enviar en el archivo de trabajo data###.bin. Esta variable se utiliza para establecer que el primer dato a ser enviado está presente en el archivo de trabajo.

La variable next_to_send almacena la posición dentro del buffer de trabajo del siguiente elemento que debe ser enviado.

### SD configuration variables

En esta sección se definen las macros y variables asociadas a la gestión de la tarjeta SD.

La macro CHIP_SELECT almacena el pin CS del Arduino.

La macro error(msg) define un método para la impresión de un error asociado a la tarjeta SD, deteniendo la ejecución del programa.

El objeto sd se utilza para gestionar la tarjeta SD en el sistema.

El objeto binFile se utiliza para el manejo de un archivo dentro de la tarjeta SD. Dado que el archivo binFile es una única instancia de un SdBaseFile, el programa está pensado para trabajar con un único archivo abierto a la vez.

La variable sd_block es una estructura de datos de tipo block_type. Esta estuctura de datos es la que se escribe en los archivos binarios usados en la gestión de la tarjeta SD. Para detalles de la estructura, ver el archivo dataTypes.h

La variable written_blocks es un contador utilizado para llevar la cuenta de los bloques escritos en el archivo de trabajo utilizado.

### Sensors configuration variables

En esta sección se definen macros asociadas a la configuración tanto de muestreo como de envío de datos. Además, se define un typedef para estandarizar las funciones asociadas a la lectura de datos.

La macro SENSING_FREQ_SECS se utiliza para definir el tiempo que debe transcurrir entre cada muestreo de los sensores.

La macro SENDING_FREQ_SECS establece el tiempo que debe transcurirr entre cada envío de datos hacia el módulo de transmisión LoPy4

La macro N_SENSORS se usa para definir la cantidad de sensores que se están utilizando en el Nodo Sensor.

El typedef sensorValueFunction define un tipo que representa una función que no recibe argumentos y retorna un float.

El arreglo registered_sensors se utiliza para identificar los distintos sensores que se encuentran dentro del Nodo Sensor. La identificación de estos sensores se genera mediante los identificadores únicos asociados a cada uno de los sensores, definidos dentro del archivo dataTypes.h

Posterior al arreglo registered_sensors, se deben definir las funciones asociadas a la lectura de cada uno de los sensores registrados en arreglo.

Finalmente, se define el arreglo de sensorValueFunction sensors_functions, el cual debe almacenar las funciones asociadas a cada uno de los sensores registrados en registered_sensors, cuidando respetar el orden de registro de cada uno de los sensores. Ejemplo de esto se encuentra comentado en el código.

## Definición de funciones

En esta sección, se definen funciones asociadas a distintas tareas dentro del Nodo Sensor. Las funciones están documentadas en el código, especificando la tarea que realizan. Cabe destacar que, debido a la arquitectura del programa desarrollado en el Arduino, las funciones trabajan con las variables globales definidas en la sección anterior, por lo que generalmente no reciben parámetros y modifican estos valores a lo largo de la ejecución.

## Debugging
La carpeta `decode_sd_binaries` contiene el archivo `lectura_datos.cpp`, el cual una vez compilado decodifica un directorio que contenga archivos binarios de bloques de lecturas de datos. *Ojo:* estos archivos binarios son los que se almacenan en la SD (son arreglos de `reading_type`), **no son** paquetes de datos codificados con `SensorPayload`.
Se incluye un ejecutable `lectura_datos` compilado sobre GNU/Linux x86_64

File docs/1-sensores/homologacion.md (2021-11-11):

# Homologación de sensores

Por completar

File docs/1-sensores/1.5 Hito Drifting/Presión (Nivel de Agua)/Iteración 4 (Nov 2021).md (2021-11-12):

# Sensor de Presión (Nivel) - Iteración 4

## Introducción

Finalizados los experimentos de 

## Costo

## Etc

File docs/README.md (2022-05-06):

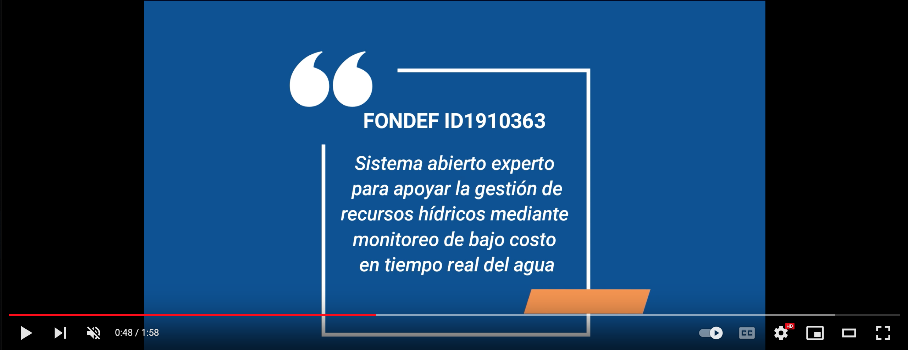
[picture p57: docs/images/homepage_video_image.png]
Everything Is AWESOME (https://www.youtube.com/watch?v=SJs9-OBhGeA)


<h1 style="text-align:center;color:#000610"> Open Water: Fondef IDeA ID19I10363</h1>

<h5 style="text-align:center;color:DodgerBlue;"> Sistema abierto experto para apoyar la gestión de recursos hídricos mediante monitoreo de bajo costo en tiempo real de aguas superficiales y subterráneas </h5>

<p style="text-align:justify;">
En enero del 2020 el consorcio formado por NIC Labs, el Departamento de Ingeniería Eléctrica y Geología de la Universidad de chile, y además empresas externas, propusieron diseñar y desarrollar un prototipo experimental con el objetivo de ligrar tener un sistema de medición multiparamétrico abierto, con el cual se pueda masificar el monitoreo de la calidad de agua tanto superficial como subterranea, con la adaptación de la tecnología de bajo costo.

La investigación científica es llevada a desarrollo mediante fondos otorgados por FONDEF ID19I10363.
</p>

<br>

<h2 style="text-align:center;color:#000610"> Noticias </h2>

<br>

<h2 style="text-align:center;color:#000610"> Equipo </h2>

<br>

<h2 style="text-align:center;color:#000610"> Licencia </h2>

<br>

<!--
<b>Editar bitacora</b>

Referirse a la página [como editar](old/como-editar.md).
-->

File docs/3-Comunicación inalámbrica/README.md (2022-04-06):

# 📡 Comunicación Inalámbrica

## Diseño

## Versiones

## Codificación

## Programación

## Pruebas/Resultados

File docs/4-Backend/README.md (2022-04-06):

# 🚀 Backend

## Arquitectura

## Tecnologías

## Base de datos

## Proceso de diseño general, parámetros de diseño, participantes del proceso de diseño

## Fotos del sistema

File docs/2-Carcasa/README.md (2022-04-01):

# 📦 Carcasa sumergible

## Diseño

Directrices de diseño (”requerimientos”)

Condiciones de uso

## Versión final

Diseño final y partes

## Instrucciones armado

Manual (Adjunto)

## Resultados pruebas

Resumen de resultados y roadmap siguiente.

Aprendizajes.

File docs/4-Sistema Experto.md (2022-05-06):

# 🤖 Sistema Experto

El monitoreo continuo en el tiempo y análisis de caudales superficiales, niveles de agua subterránea y calidad química del recurso hídrico son esenciales para comprender el funcionamiento de un sistema hidrogeológico. Estos, a su vez, forman la base para que un/a experto/a en recursos hídricos, logre entender el funcionamiento natural de dicho sistema y distinguirlo de aquellos comportamientos anómalos. Algunos ejemplos de anomalías en los sistemas hidrogeológicos pueden ser los periodos de sequía, donde la disponibilidad, así como también la calidad del recurso hídrico, pueden verse afectados notablemente. Otro ejemplo también son los eventos de contaminación, donde la composición química del agua se ve afectada. De este modo, una rápida detección ante instancias anómalas es crítica para la planificación y toma de decisiones.

## Lógica de detección

La detección de instancias anómalas a través de variables medidas desde sistemas hidrogeológicos, como los acuíferos, se puede entender como una fusión de diversas herramientas de modelamiento, datos históricos, datos medidos (estado actual acuífero) y conocimientos de expertos con el fin de poder discriminar de manera eficiente la presencia de anomalías. Si este procedimiento de detección de anomalías se hace de manera automática, entonces podríamos definir esta “fusión” mediante el concepto de Sistema Experto, el cual es ampliamente usado en distintas áreas para apoyar a los operadores en la toma de decisiones. En el caso puntual de los acuíferos, el Sistema Experto puede ser de utilidad como apoyo en la toma de decisiones para la operación de estos acuíferos en cuanto a la ejecución de procedimientos preventivos o correctivos necesarios, dada alguna(s) anomalía(s) detectada(s).

<!-- El presente proyecto de investigación y desarrollo comprende dentro de su propuesta la elaboración de un Sistema Experto, el cual, mediante la información recopilada a partir de datos históricos, conocimiento experto humano, y mediciones actuales (desde nodos sensores) de temperatura, conductividad eléctrica y pH, turbiedad y nivel piezométrico sea capaz de detectar anomalías en acuíferos monitoreados. Un esquema que ejemplifica el concepto de Sistema Experto se muestra en la Figura 1. -->

a title

El diseño considerado para el Sistema Experto consta del funcionamiento de dos herramientas (o modelos) de machine learning entrenadas para trabajar en paralelo, y cuyas salidas serán fusionadas a través de alguna estrategia determinada. Las herramientas de machine learning escogidas para esta propuesta son LightGBM y TabNet, las cuales, una vez que son entrenados, irán detectando anomalías en los acuíferos monitoreados, a medida que reciban mediciones en línea. Un ejemplo del flujo de información en el funcionamiento de esta metodología se muestra en la Figura 7.

a title

Es importante mencionar que el Sistema Experto no se limita solamente a utilizar dos modelos (LightGBM y TabNet), su diseño hace que sea flexible para que puedan incorporarse otros tipos de modelos para trabajar en paralelo juntos a los ya propuestos.

En términos gráficos, la base de datos de validación, junto con las anomalías detectadas mediante la fusión de los modelos LightGBM y TabNet a través de la función lógica OR son visualizados en la Figura 15.

a title

De resultados obtenidos se desprende que ambos modelos por separado tienen un desempeño por sobre un 75% en prácticamente todas las métricas (solo el Recall para TabNet está por bajo un 75%, llegando a ser un 73%). Sin embargo, al fusionar ambos modelos, todas las métricas propuestas sobrepasan el 75% de desempeño requerido para alcanzar el hito, y considerando solo el Accuracy, éste logró alcanzar aproximadamente un 95%.

<!--
Tipos de Alarma
detección de anomalías
Ejemplos

Decir que esos tres elementos se encuentran para poder generar el tema.
Se busco poder juntar dos tipos de conocimientos, dato histórico más conocimiento humano. Que 
Anomalía. Comportamiento extraño de lo que se ha visto históricamente. De lo que se ve en el pasado una anomalía es un comportamiento no visto.

Diseño de s e se traduce en el acoplamiento de dos herramientas de ML, esta juntura con conocimiento humano se conforma en la detección de anomalías. Conjunga dos herramietnas de ML que al juntarse aumentan el diagrama de selección

Se tienen datos de P, T y Hum, en negro es el sistema experto y lo de abajo es lo que de verdad es anomalía.

Diseño
herramientas
y producto de sistema experto con datos que tenemos disponibles.

La interfaz es la visualización de todo un trasfondo que hay detras. Es la que toma todo el trabajo realizado por el ambiente de base de datos, es la conexión que permite a la per

-->

## Lógica de visualización

El Sistema Experto debe contemplar una capa de visualización, la cual ponga a disposición del usuario la información relacionada al acuífero que está siendo monitoreado. Esto implica la visualización de las variables medidas, así como también las anomalías detectadas por el sistema experto.

El sitio web es la culminación, y toma el trabajo realizado por todos los sistemas previos a él para presentar al usuario con la información y recomendaciones relevantes. Esto queda representado en la siguiente figura.

a title

Para revisar el sitio web se puede entrar al  [enlace](http://agua.niclabs.cl:3001/) con las siguientes credenciales:

| Usuario | Pass |
|-|-|
| pruebas | fondefagua |

Se pueden observar algunos mock-ups.

|a title|
|-|
|Sitio web de visualización de datos|

|a title|
|-|
|Pestaña de descarga de datos|

|a title|
|-|
|Visualización de datos recientes, es posible comparar entre estaciones|

|a title|
|-|
|Visualización histórica de datos|

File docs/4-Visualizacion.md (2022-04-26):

# 🚀 Interfaz Gráfica

## Diseño

El diseño de la interfaz gráfica desarrollada en el presente proyecto se delineó bajo 3 ejes principales: estructura de la interfaz gráfica, usabilidad, y experiencia de usuario. Estos ejes apuntan a desplegar la mayor información de interés para el usuario, permitiéndole interactuar con los datos medidos desde los acuíferos de una manera intuitiva y similar a otras plataformas existentes que cumplan los mismos propósitos.

### Estructura de la interfaz gráfica
La estructura que debe seguir la interfaz gráfica comprende 3 paneles principales que están interrelacionados entre sí, en la Figura 1 se muestra un esquema que ejemplifica estos 3 paneles mencionados.

a

Figura 1. Esquema de ejemplo distribución de los 3 paneles principales que constituyen la interfaz gráfica.

1. El primer panel debe incluir una cartografía en donde se presente un mapa con las estaciones geolocalizadas. Este mapa debe cumplir con ser interactivo, para que se puedan realizar operaciones de acercamiento o alejamiento, para ir a zonas específicas con el fin de ubicar las estaciones (nodos sensores).
2. El segundo panel, debe corresponder a un panel de visualización de datos, en donde se desplieguen las gráficas de las estaciones seleccionadas en el mapa. Las gráficas a su vez corresponderán a series de tiempo que muestren los datos medidos y almacenados de cada uno de los sensores instalados en las estaciones.
3. El tercer panel corresponde a un listado en el lado derecho de la interfaz gráfica con las estaciones que están visibles en el mapa. Además, este panel incluye una descripción geográfica de las estaciones, más los datos de las últimas mediciones de adquiridas. Dentro de este panel se agregan dos pestañas:
   * i) una pestaña para la descarga de datos, y
   * ii) una pestaña con una descripción del sistema de visualización (información que puede estar asociada a la versión de la interfaz gráfica, los/las desarrolladores involucrados, y/o formas de uso de la interfaz gráfica).

### Usabilidad

La interfaz gráfica requiere de un sistema interconectado de datos, es decir, cuando se selecciona una estación para visualizar sus estadísticas, éstas deben poder ser seleccionadas de distintas formas, por ejemplo, a través del mapa interactivo, como también, mediante un menú desplegable. Cualquiera de las formas de seleccionar las estaciones, debe hacer que se carguen los datos correspondientes. Una vez cargados los datos, se deben desplegar las gráficas con las series de tiempo de los datos medidos por los sensores de la estación.

El mapa interactivo, por su parte, puede tener la opción de cambiar su fondo, otorgando distintas perspectivas del despliegue de estaciones (visualización satelital, o visualización con un sistema de límites geo-políticos).

Se le debe proporcionar la mayor cantidad de información al usuario en cuanto a los datos medidos y almacenados en la base de datos, tanto a nivel temporal como espacial (comparación entre estaciones).

## Implementación interfaz gráfica

La implementación de la interfaz gráfica debe ser capaz de resolver distintos tipos de tareas, como por ejemplo, interactuar con un servidor que contiene aplicaciones, tener acceso a la base de datos que contiene los datos medidos por los sensores, desplegar la información necesaria para el usuario (o cliente) a través de algún software o aplicación web.

En el campo de la programación web, y “dependiendo del lugar” en donde se encuentren las tareas/aplicaciones, se definen los conceptos de back end y front end. El back end se refiere a todas las aplicaciones que están “del lado del servidor”, y por su parte el front end, se refiere a todas las aplicaciones que están “del lado del cliente” [3]. En el caso de la implementación de la interfaz gráfica desarrollada en el presente proyecto, el back end y el front end se resumen y ejemplifican en la Figura 2.

a

Figura 2. Ejemplo de lo que incluye el back end y el front end en la implementación de la interfaz gráfica

De acuerdo a lo anterior, la implementación de la interfaz gráfica apuntó a elaborar y configurar tanto el back end como el front end. El detalle de los softwares y aplicaciones utilizadas para el desarrollo de esta implementación se detallan a continuación y se resumen en la Figura 3.

a

Figura 3. Esquema de la implementación de la interfaz gráfica.

#### Front End

El front end fue desarrollado en React [4], que es una biblioteca de JavaScript [5] que ayuda a crear interfaces de usuario interactivas. Existen muchas librerías propias de React, que facilitan el uso de librerías JavaScript externas en un mismo ambiente. Para el caso de la implementación desarrollada en el presente proyecto, se utilizaron las librerías Leaflet [6] para visualizar e interactuar con el mapa, y Plotly.js [7] para mostrar los gráficos con sus interacciones. React se renderiza usando Node [8], que es un entorno de ejecución para JavaScript.

Versiones utilizadas:

 * React: v17.0.2
 * Leaflet: v1.7.1
 * Plotly.js: v2.2.1
 * Node: v12.18.3

#### Back End
La obtención de los datos de los sensores instalados en los acuíferos, se realizó a través de una interfaz de programación de aplicaciones (API, por sus siglas en inglés) desarrollada en Flask [9], que es un framework de desarrollo web escrito en Python [10]. La API se conecta con las bases de datos en MySQL [11] y en influxDB [12] y genera rutas de acceso que son posteriormente utilizadas en la interfaz web para obtener los datos solicitados. Esto permite que el front end pueda tener acceso a los datos cuando sea necesario, y de este modo, dejarlos a disposición del cliente.

Versiones utilizadas:
 * MySQL: v8.0.21
 * Influx: v1.8.3
 * Flask: v1.1.2
 * Python: v3.7.3

---

 * [3] “Front End vs. Back End: What’s the Difference?” https://kenzie.snhu.edu/blog/front-end-vs-back-end-whats-the-difference/ (accessed Jan. 14, 2022).
 * [4] “React. Una biblioteca de Javascript para construir interfaces de usuario.” https://es.reactjs.org/ (accessed Jan. 08, 2022).
 * [5] “JavaScript.” https://www.javascript.com/ (accessed Jan. 08, 2022).
 * [6] “Leaflet. An open-source JavaScript library for mobile-friendly interactive maps.” https://leafletjs.com/ (accessed Jan. 09, 2022).
 * [7] “Plotly JavaScript Open Source Graphing Library.” https://plotly.com/javascript/ (accessed Jan. 09, 2022).
 * [8] “Node.js.” https://nodejs.org/es/ (accessed Jan. 09, 2022).
 * [9] “Flask web development, one drop at a time.” https://flask.palletsprojects.com/en/2.0.x/ (accessed Jan. 09, 2022).
 * [10] “Python.” https://www.python.org/ (accessed Jan. 09, 2022).
 * [11] “MySQL The world’s most popular open source database.” https://www.mysql.com/ (accessed Jan. 10, 2022).
 * [12] “Act in Time. Build on InfluxDB. The platform for building time series applications.” https://www.influxdata.com/ (accessed Jan. 10, 2022).

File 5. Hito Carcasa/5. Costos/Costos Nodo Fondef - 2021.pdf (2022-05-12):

| Precio con IVA x 1 | Precio con IVA x 10 | Precio con IVA x 50 | Precio con IVA x 100
Piezas technyl torno | 70000 | 700000 | 3.500.000 | 7.000.000
Tubo acrílico 30 cm (formato 1.8 M) | 7.333 | 88000 | 396000 | 748000
Prensas estopa | 12.000 | 120.000 | 600.000 | 1.200.000
Sellos orings | 2.500 | 25000 | 125000 | 250000
Sistema descenso-enganche | 8501 | 30262 | 96509 | 163030
Sistema protección | 15007 | 55037 | 185462 | 322728
Soporte interno-plataforma | 17007 | 67473 | 196945 | 360332
Soldaduras piezas acero | 20000 | 200000 | 200000 | 200000
Teflón líquido | 5000 | 15000 | 75000 | 150000
TOTAL | 157348 | 1300772 | 5.374.916 | 10.394.090
Precio Unitario | 157.348 | 130.077 | 107.498 | 103.940

*Costos referenciales en base a proveedores tentativos, tarifas 2021

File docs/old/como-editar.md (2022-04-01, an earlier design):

# Cómo editar bitácora

Esta documentación está almacenada en el directorio `/docs` del repositorio [github.com/niclabs/water-monitoring](https://github.com/niclabs/water-monitoring) y utiliza [docsify](https://docsify.js.org/#/?id=docsify) para generar la versión web. Cualquier cambio de los archivos del repositorio actualizarán automáticamente este sitio.

### Resumen de docsify
En el directorio raíz de la documentación (`/docs`) hay un archivo `README.md` y otros directorios. El archivo `README.md` de cada directorio es el archivo principal que será cargado por defecto al acceder a una nueva ubicación; por ejemplo, este texto está en la ruta `/docs/README.md`. Si desea modificar la página principal de [Grupo Sensores](1-sensores/README.md), basta editar el archivo `/docs/1-sensores/README.md`. Si desea modificar otra página de dicho directorio, como [Homologación](1-sensores/homologacion.md), basta editar `/docs/1-sensores/homologacion.md`.

### Sidebar
En el directorio raíz también hay un archivo llamado `_sidebar.md`. Si desea agregar una nueva página a la barra lateral, sólo debe editar `/docs/_sidebar.md` y agregar el hipervínculo a la lista Markdown. Si agrega páginas de un subdirectorio, procure mantener la jerarquía de la lista indentando con espacios.

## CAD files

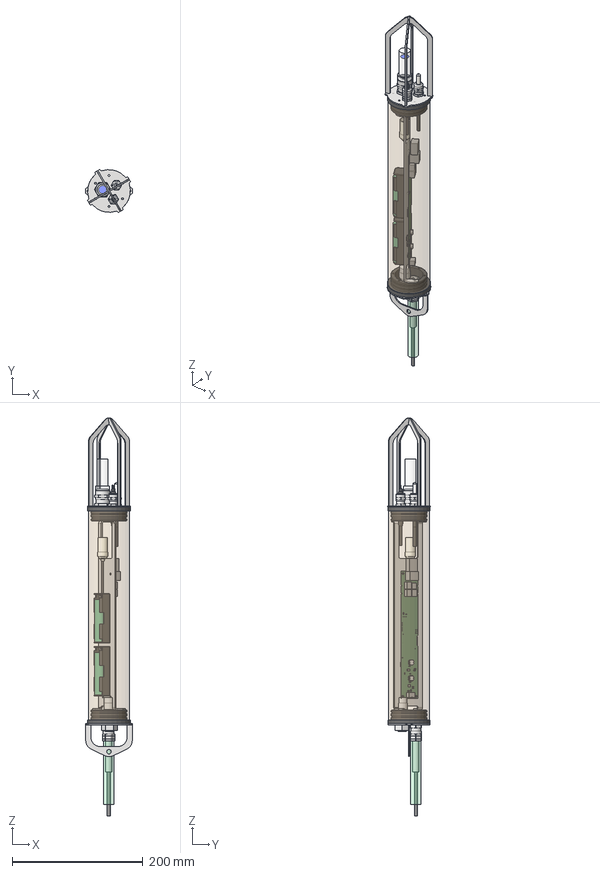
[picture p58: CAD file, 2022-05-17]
5. Hito Carcasa/3. Modelo 3D/Armado Ensamble.stp
71.5 x 65.3 x 609.9 mm
Sello V5 x 2
Tubo 63.5 200mm
Plataforma V5
Enganche Flat V6
Proteccion Flat V6
Uchile5
Bateria V2 x 2
Estopa Grande
Golilla Chicha x 3
Estopa Chica x 2
Golilla Grande
Tuerca PG13.5 Metal
Tuerca PG7 Metal x 2
SNR PH
SNR Conductividad
SNR Temperatura
SNR Presion V2
Estopa PG9
Tuerca PG9 Metal
Tuerca SNR Presion
Estopa G9 Modelo Cable

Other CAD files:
5. Hito Carcasa/1. Planos fabricación de piezas/1. CorteLáser_ Piezas acero inoxidable 2 mm/Proteccion Aza 1 V6 x 1 unidad.dwg
5. Hito Carcasa/1. Planos fabricación de piezas/5. Caja de montaje exterior/1. Pieza montaje electrónica interna caja/Corte láser acero inoxidable 2mm/Placa Caja V2.dwg
5. Hito Carcasa/1. Planos fabricación de piezas/5. Caja de montaje exterior/2. Pieza montaje pozo-caja/Corte láser acero inoxidable 2 mm/Fijación pozo.dwg
5. Hito Carcasa/1. Planos fabricación de piezas/1. CorteLáser_ Piezas acero inoxidable 2 mm/Proteccion Aza 2 V6 x 1 unidad.dwg
5. Hito Carcasa/1. Planos fabricación de piezas/1. CorteLáser_ Piezas acero inoxidable 2 mm/Plataforma V5 x 1 unidad.dwg
5. Hito Carcasa/1. Planos fabricación de piezas/1. CorteLáser_ Piezas acero inoxidable 2 mm/Enganche Base V6 x 1 unidad.dwg
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

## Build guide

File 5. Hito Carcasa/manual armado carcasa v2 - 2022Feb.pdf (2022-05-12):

# Instrucciones Armado Carcasa v2

### 24 de Febrero

# 1. Introducción

Nueva versión del manual de instrucciones de la carcasa trabajado en base a versión 1. Esta versión cuenta con comentarios adicionales y detallados para armado de carcasa desde cero. Se reutilizan gráficas y estructura general de instrucciones generales añadiendo detalles sobre ellas.

Probablemente puedan existir detalles no especificados, en caso de cualquier duda favor referirse a apoyo gráfico del manual o correo de contacto en sitio web del proyecto :)

# 2. Lista de Materiales y Piezas

## 2.1. Referencia gráfica de partes y piezas

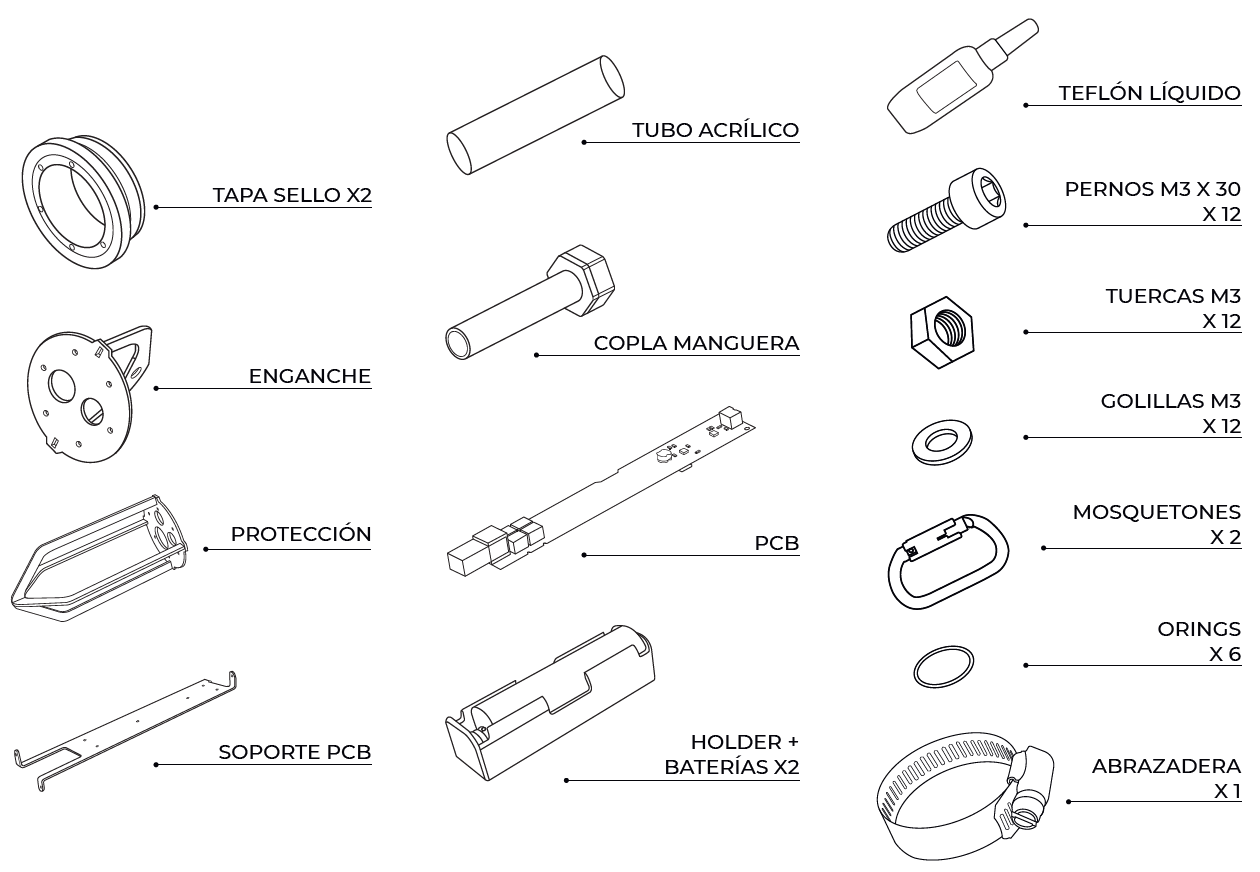
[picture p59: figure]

## 2.2. Lista de Materiales

### 2.2.1. Materiales Carcasa

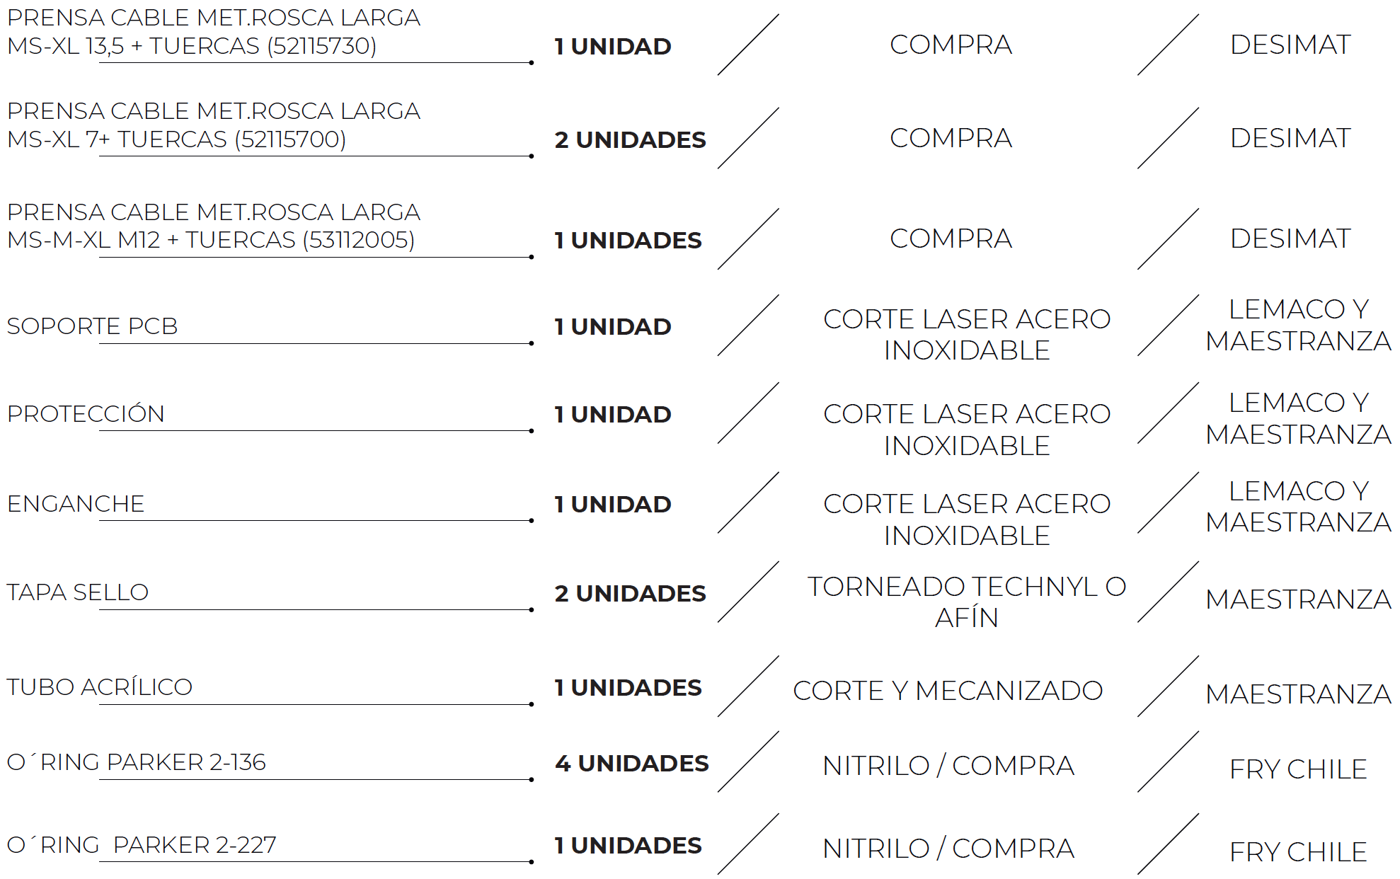
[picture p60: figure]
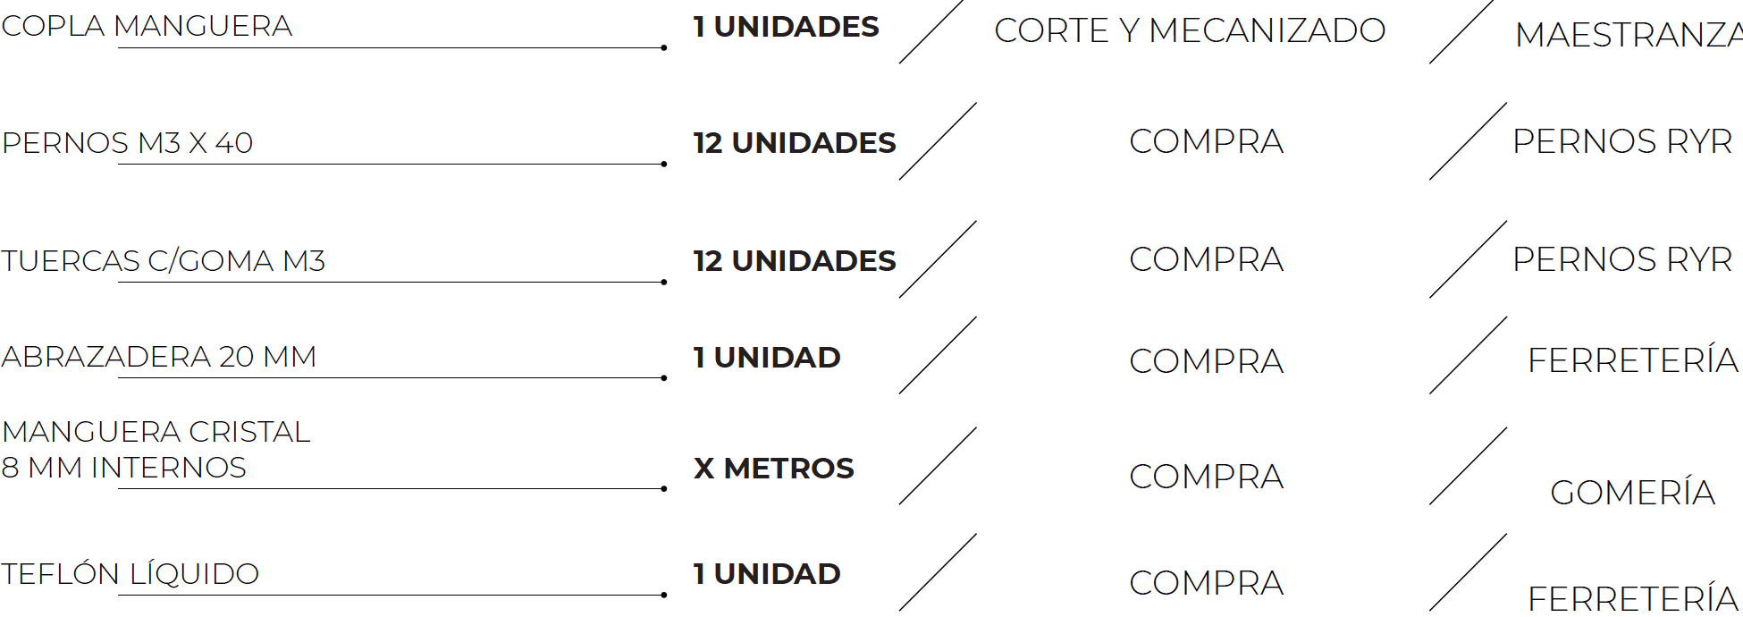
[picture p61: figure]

- Sensores y electrónica
- Sensor de presión
- Sensor de pH
- Sensor de conductividad
- Sensor de temperatura
- 2x baterías 18650 cargadas
- 2x porta baterías 18650 con jumpers soldados
- Micro SD
- Batería CR1225

** Tubo de acrílico mide 32.3 cm.

### 2.2.2. Materiales Cable

- Manguera
- Cable UTP
- Alambre para lauchear

- Vaselina o grasa para pasar el alambre por la manguera

### 2.2.3. Herramientas

- Cartonero
- Destornillador línea
- Herramientas para hacer hoyos en cinturón
- Sierra y lija de metal para cortar pernos M3 largos
- Atornillador pernos M3 con cabeza hexagonal
- Teflón líquido
- Silicona Pro de alta temperatura.
- Acetona (para limpiar teflón y silicona)
- Vaselina (para engrasar juntura de las tapas al acrílico)
- Tuerca sensor de Presión (es la misma medida que la utilizada en pieza que conecta al cable-manguera)
- Pro-tape de goma (para hacer o-rings)

# 3. Instrucciones

## 3.1. Paso 1

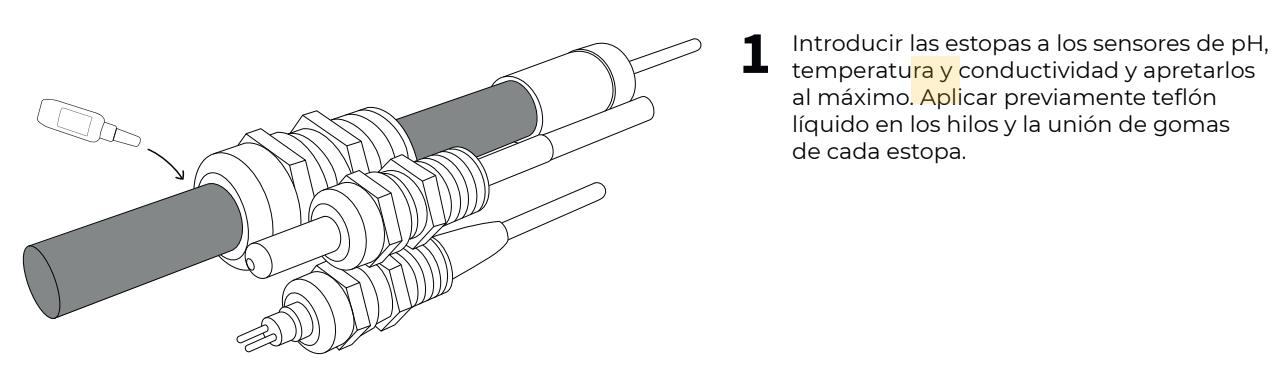
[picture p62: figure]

- Cortar o-rings desde Protape para pernos M3 a usar en Paso 3.
- Tener cuidado para que el teflón líquido no manche los sensores en las partes que miden. Para el sensor de pH poner la tapa.
- Aplicar teflón líquido en: la unión de pieza pH plástica, hilo superior y en parte del sensor que queda en contacto con prensa estopa y se sellará.

## 3.2. Paso 2

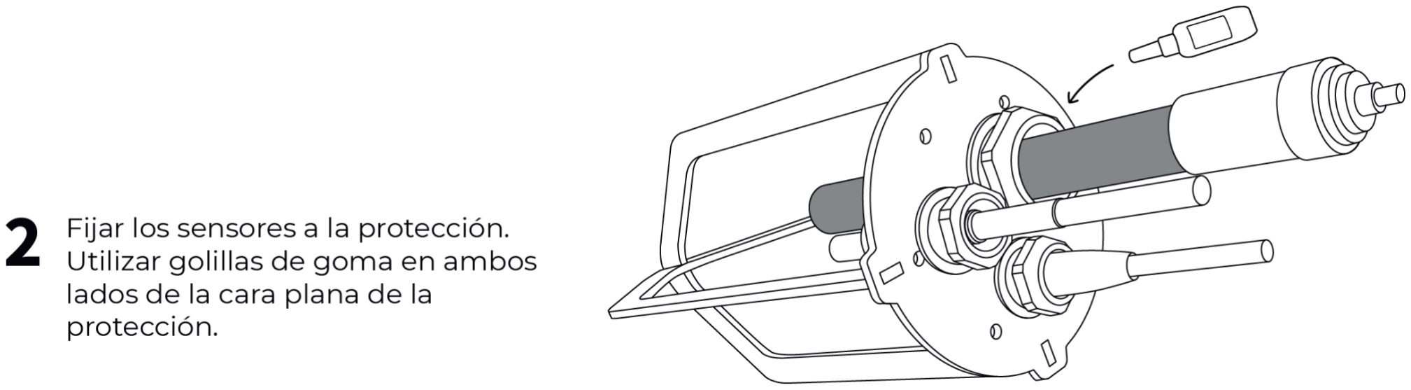
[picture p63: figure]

- Probar previamente la pieza de plexi (pieza amarilla) para ver en qué posición deben quedar las tuercas.
- Puede
- En caso de no haber o-rings se pueden fabricar con goma y cortarla dándole la forma. Se puede utilizar cámara de bicicleta o cinta Pro-tape.

## 3.3. Paso 3

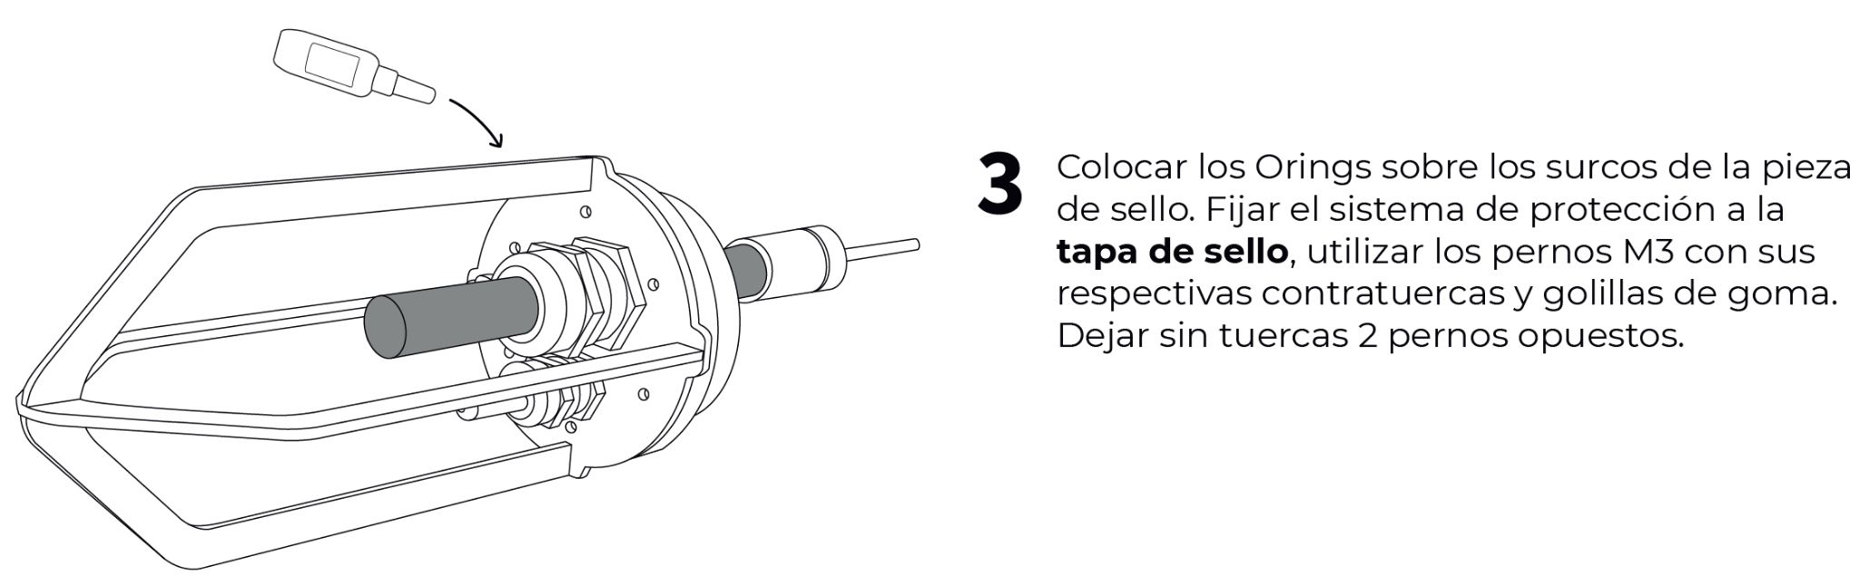
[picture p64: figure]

- OJO: Hay que hacer calzar tuercas de las prensa estopa con las tuercas M3 de la tapa porque si no toparán y no podrá cerrarse.
- Presentar todo previamente: estopas, o-rings, tapa plexi, perros tapa, etc.
- Lijar la pieza en caso de ser necesario para que no tope con las tuercas de los sensores.
- Que los pernos M3 opuestos que se unirán a la placa de la PCB, sean los que tienen más espacio en la superficie para poder apretarlos fácilmente con la herramienta.
- Hasta que el o-ring quede apretado. No es necesario más porque se pueden dañar los o-rings hechos a mano con pro-tape u otro material. Es poco probable que o-rings de goma sean dañados.
- O-rings se deben hacer de manera manual en caso de no tenerlos.

## 3.4. Paso 4

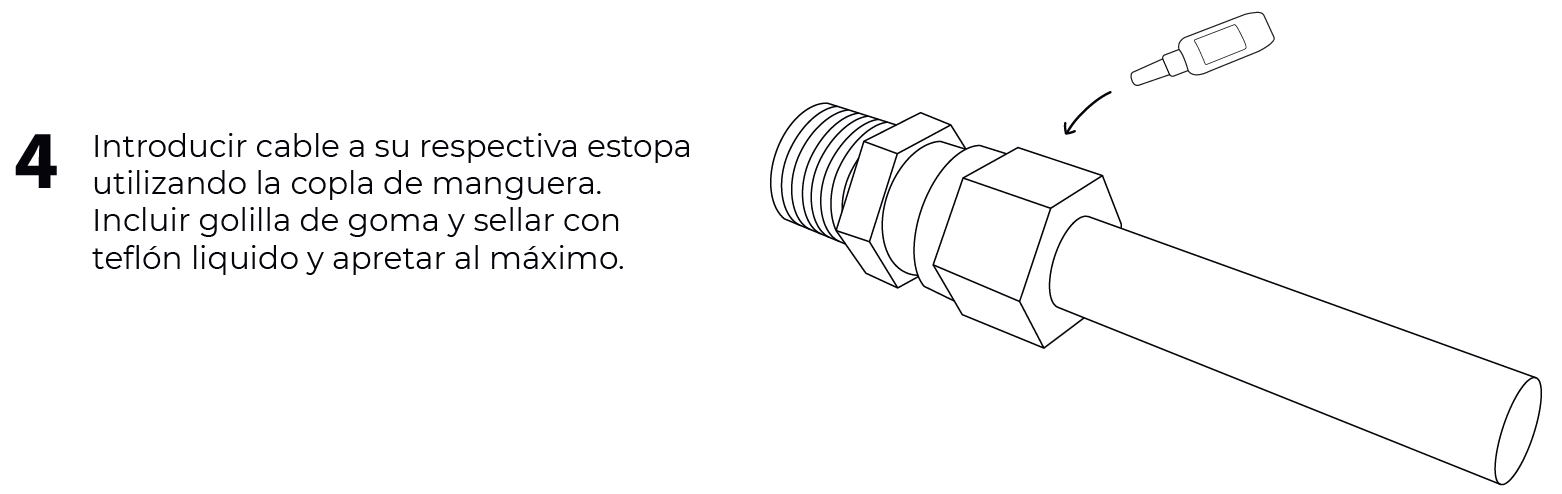
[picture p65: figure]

- No es estrictamente necesario hacer este paso ahora, puede ser cuando la pieza ya esté armada.
- Agregaría considerar hacer un nudo en el cable para que quede fijo y no pueda desaparecer dentro de la manguera.

## 3.5. Paso 5

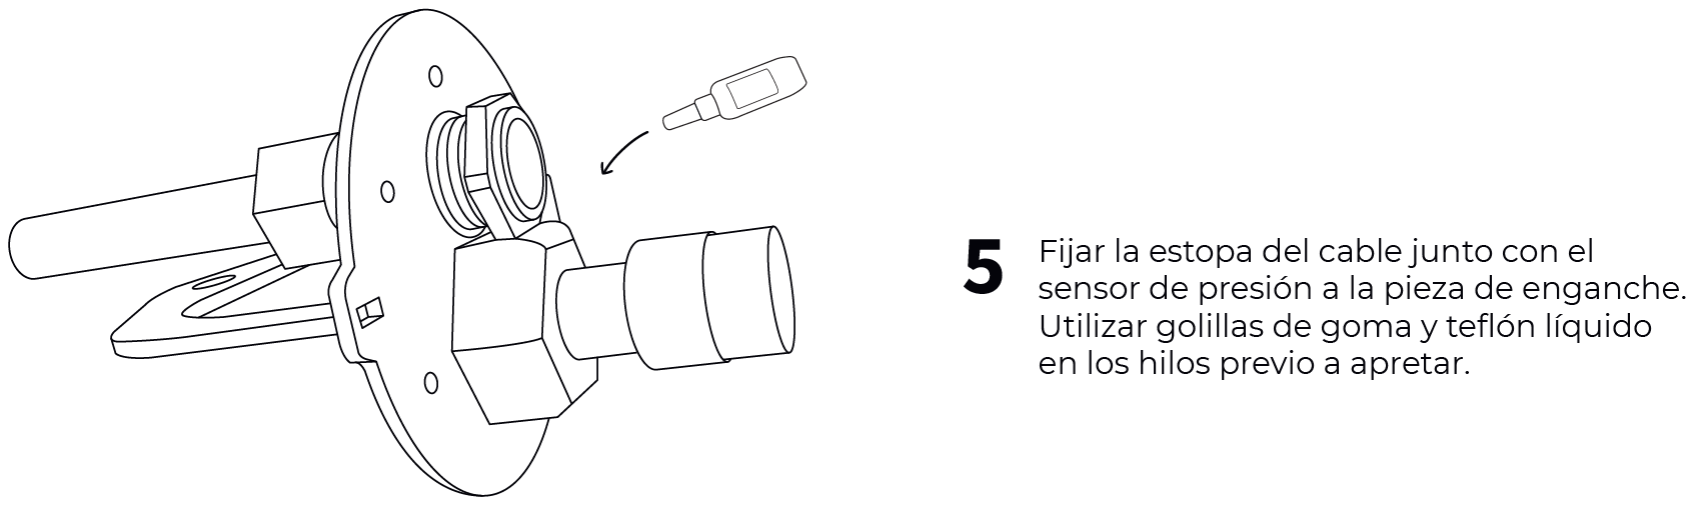
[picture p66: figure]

- Primero colocar el sensor de presión
- OJO: Hoyo para sensor de presión queda grande y o-ring pasa de largo => llenar de silicona.
- Lo mismo para el acople del cable de comunicación.
- Piezas superiores van fijas, se giran tuercas de abajo del acople y el sensor de presión.
- Colocar harto teflón en los hilos y que también selle los contactos entre las superficies de las tapas.

## 3.6. Paso 6

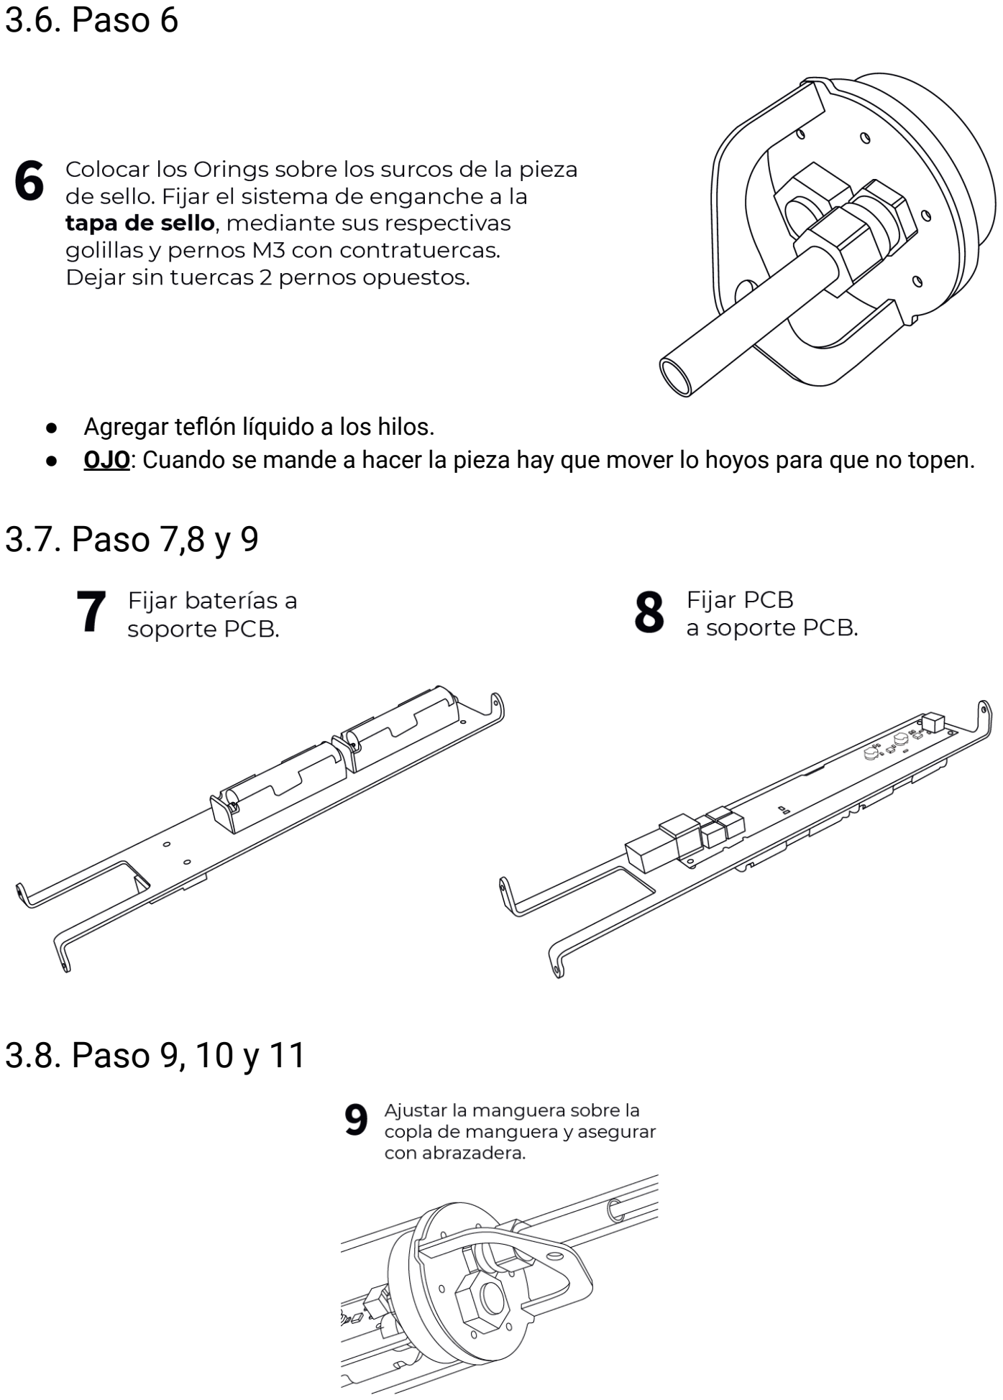
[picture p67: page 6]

- Agregar teflón líquido a los hilos.
- OJO: Cuando se mande a hacer la pieza hay que mover lo hoyos para que no topen.

## 3.7. Paso 7,8 y 9

## 3.8. Paso 9, 10 y 11

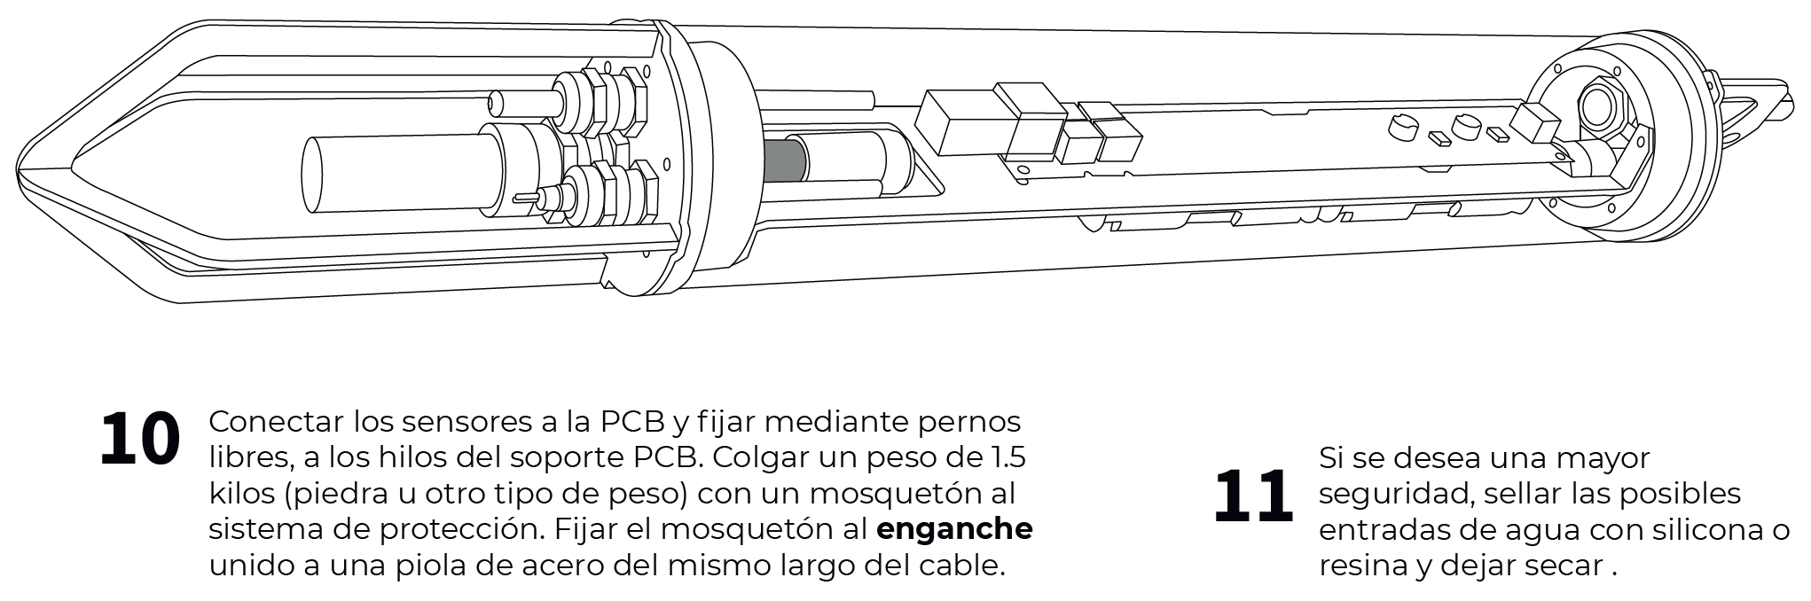
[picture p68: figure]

- P10: En lo relativo a conexión de electrónica y sensores, considerar:
- 10a. Conectar sensores de pH, temperatura y conductividad a pcb y ordenar los cables.
- 10b. Asegurarse que PCB tiene software cargado, está encendida y switch (SW2) de comunicación está en RS485.
- 10c. Pasar placa de soporte y pcb para que queden dentro del acrílico.
- 10d. Acoplar tapa inferior de la carcasa a acrílico y fijar mediante pernos libres en la tapa a la placa metálica de soporte en el interior del acrílico. Se deben ajustar los pernos para calzar con hilos de la placa de soporte.
- 10e. Conectar sensor de presión y cable UTP a la PCB por el extremo superior abierto de la carcasa.
- 10f.Acoplar tapa superior al acrílico y fijar mediante pernos libres de igual manera que antes.
- OJO: Con orientación de placa que soporta PCB.
- El lado con apertura más amplia va hacia los sensores.
- Porta baterías van hacia lado con patas más cortas.
- Poner vaselina sobre y bajo o-ring inferior. También en la orilla interior del tubo de acrílico.
- Lijar orilla de la circunferencia inferior de las aperturas del tubo de acrílico.
- OJO: Perno M3 que va en tapa superior sin tuerca, no aprieta la tapa.
- OJO: ¡La elección de hoyos para pernos en la parte superior para fijar la placa PCB es muy importante! Seleccionar para que el sensor de presión quede lo más lejos posible de la placa que sostiene la PCB.
- Se debe aplicar silicona a todas las uniones al finalizar el cierre.
- Una vez puesta la tapa limpiar con acetona restos sobrantes de silicona o vaselina para que no quede pegote.

## 3.9. Paso 12

- Probar la carcasa en ambiente controlado (laboratorio, casa) antes de llevarla a terreno.

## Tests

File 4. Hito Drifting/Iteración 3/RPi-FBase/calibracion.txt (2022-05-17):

CHANNEL_1= EC
CHANNEL_2= pH

Calibración EC: Time: 2021-03-11 13:50:05

Solución calibradora de 1413 microsiemens/cm

Valor en equilibrio
920-921

Valor en el aire
12

Calibración pH
Solución de 4.01

promedio 
228

Solución de 7.01

promedio 693 (692.93)

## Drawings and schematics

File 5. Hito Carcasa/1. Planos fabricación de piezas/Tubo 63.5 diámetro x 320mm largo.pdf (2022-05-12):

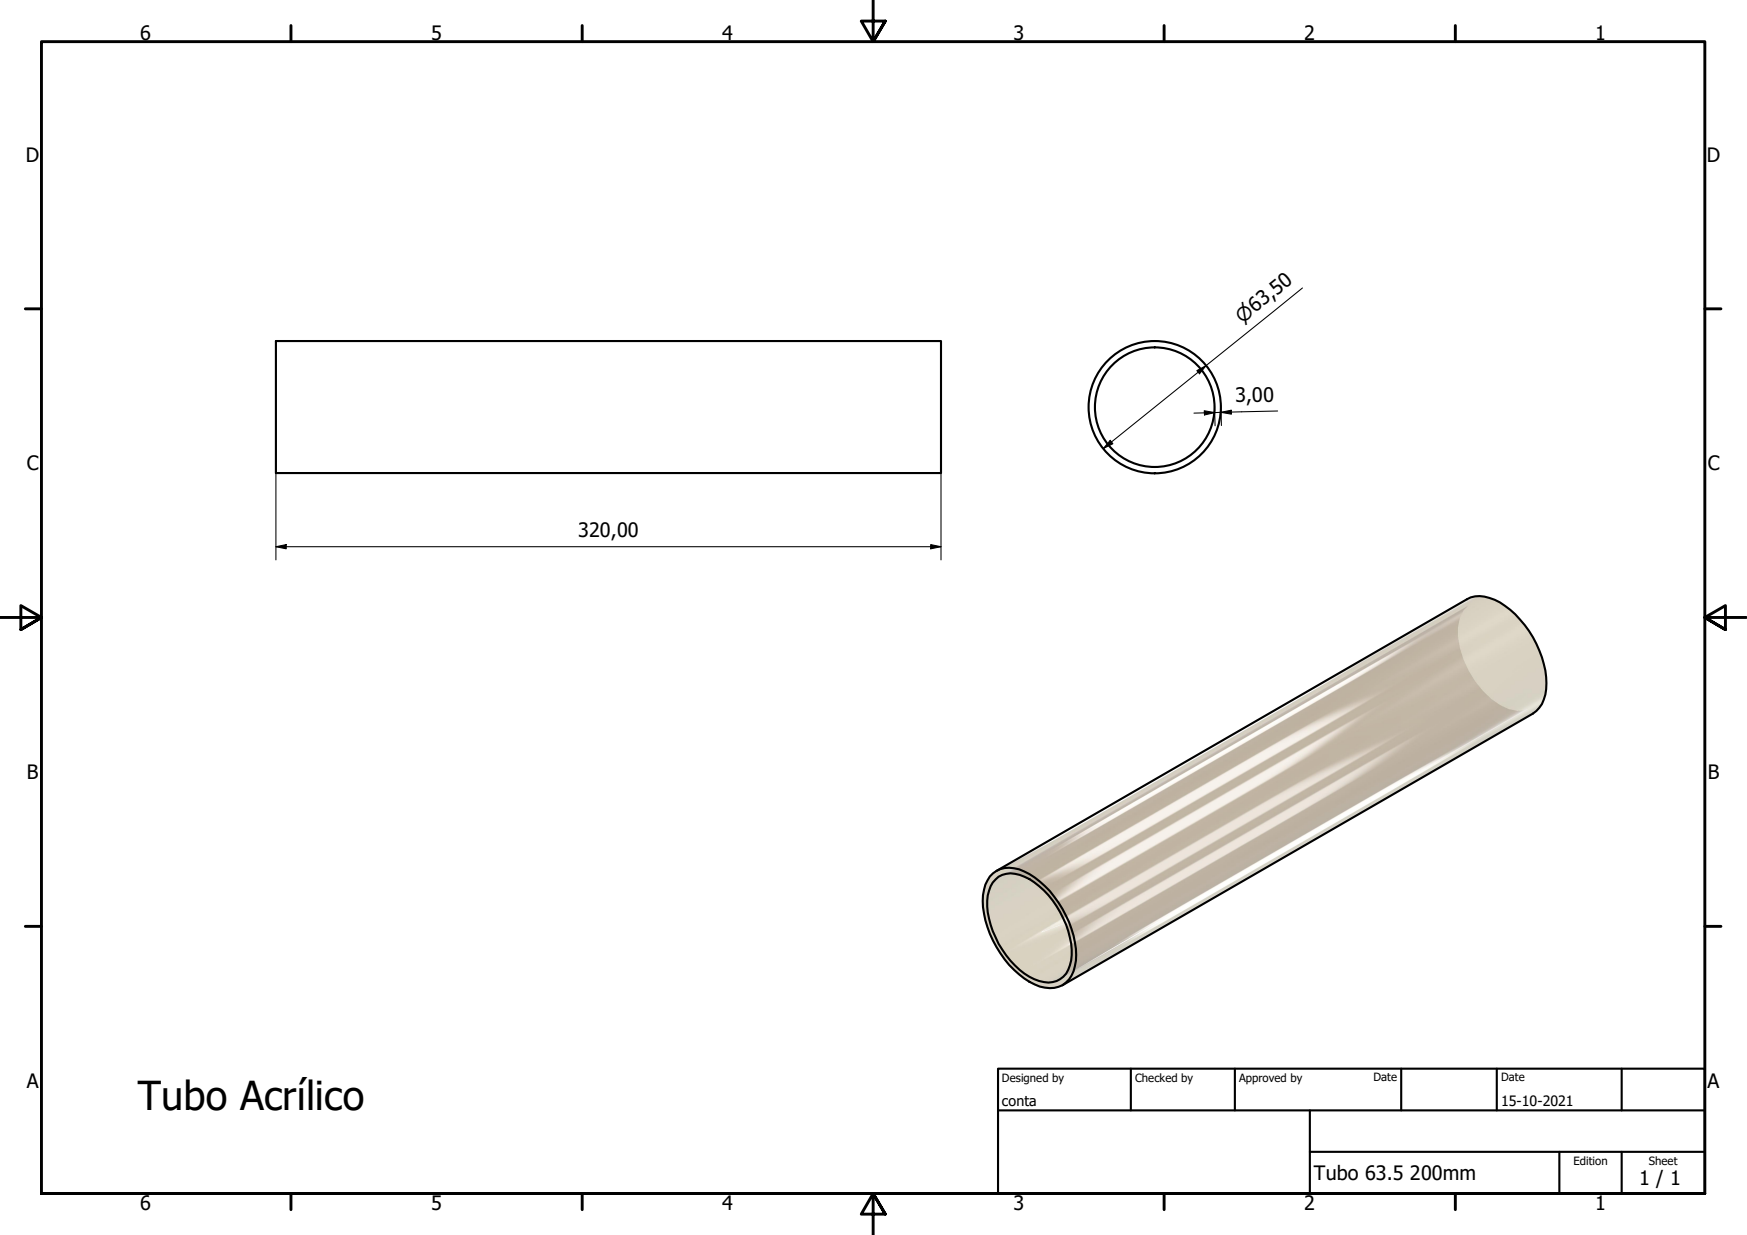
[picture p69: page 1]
Tubo 63.5 200mm; Designed by; Checked by; Approved by; Date; Tubo Acrtlico

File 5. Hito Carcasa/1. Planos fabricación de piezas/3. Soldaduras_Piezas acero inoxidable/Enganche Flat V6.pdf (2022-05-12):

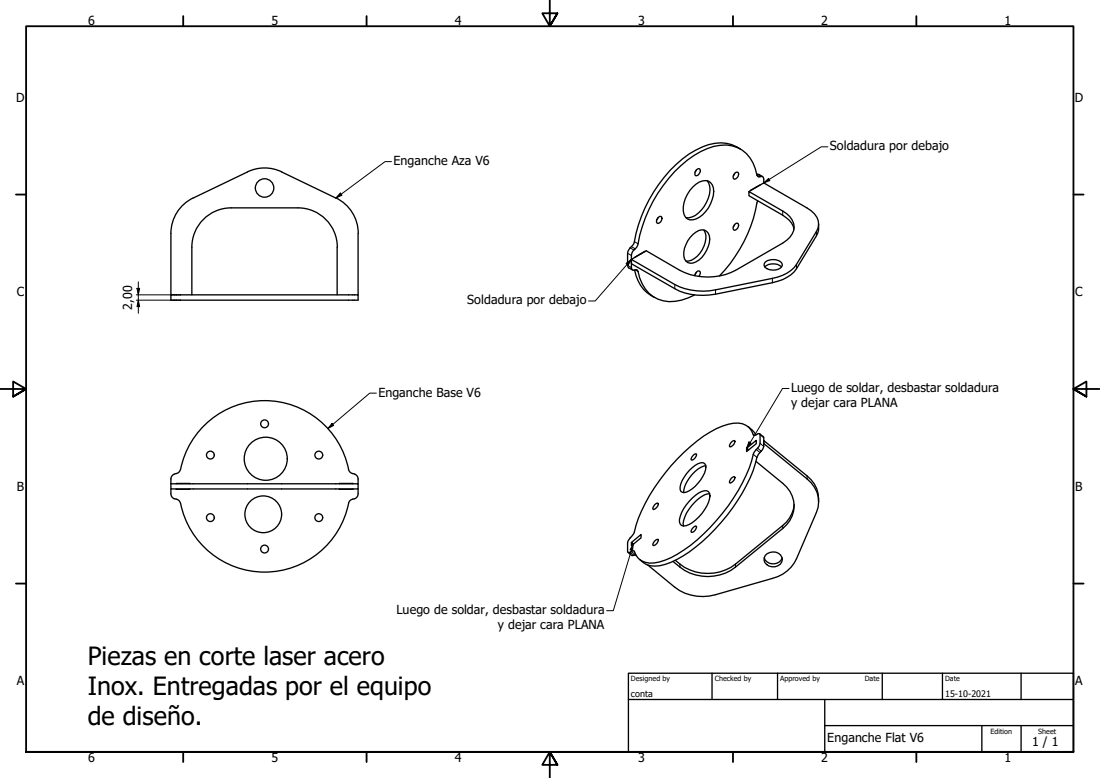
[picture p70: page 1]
Enganche Flat V6; Designed by; Checked by; Approved by; Date; Enganche Aza V6; Enganche Base V6

Soldadura por debajo

Luego de soldar, desbastar soldadura
y dejar cara PLANA

Piezas en corte laser acero
Inox. Entregadas por el equipo
de disexo.

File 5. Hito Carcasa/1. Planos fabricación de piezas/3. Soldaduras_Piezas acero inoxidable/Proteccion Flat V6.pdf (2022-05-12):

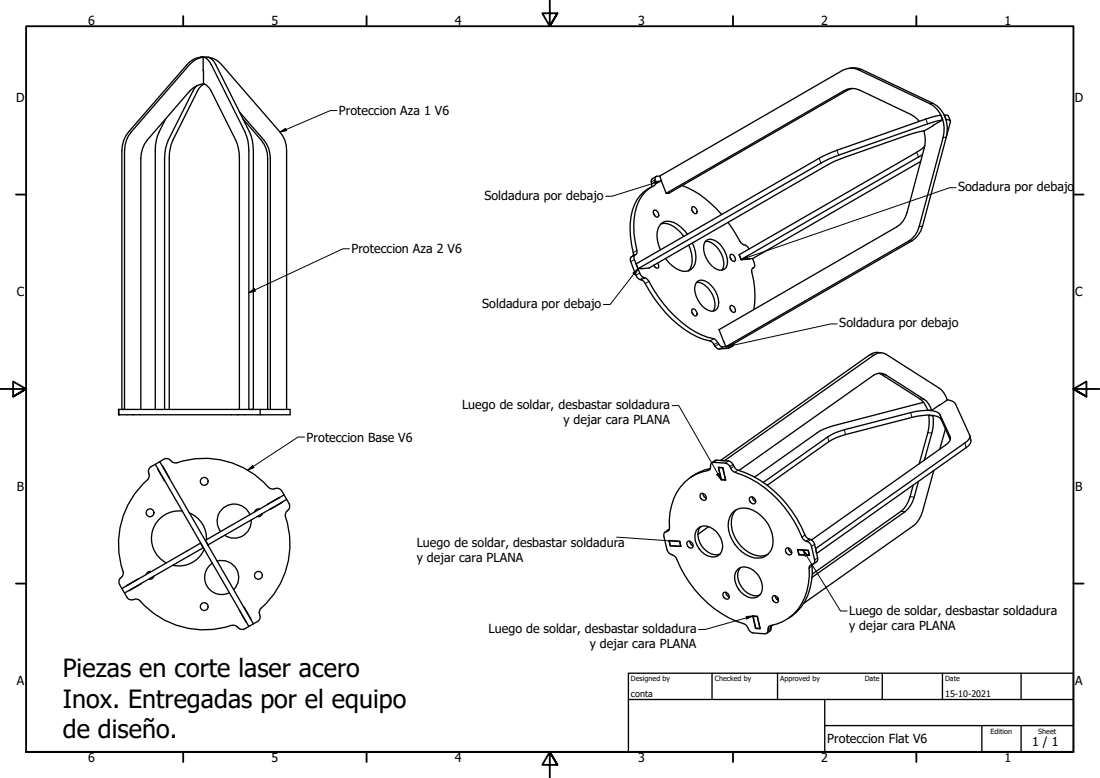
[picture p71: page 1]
Proteccion Flat V6; Designed by; Checked by; Approved by; Date; Proteccion Aza 1 V6; Proteccion Aza 2 V6; Proteccion Base V6

Sodadura por debajo

Soldadura por debajo

Luego de soldar, desbastar soldadura

y dejar cara PLANA

Piezas en corte laser acero
Inox. Entregadas por el equipo
de disexo.

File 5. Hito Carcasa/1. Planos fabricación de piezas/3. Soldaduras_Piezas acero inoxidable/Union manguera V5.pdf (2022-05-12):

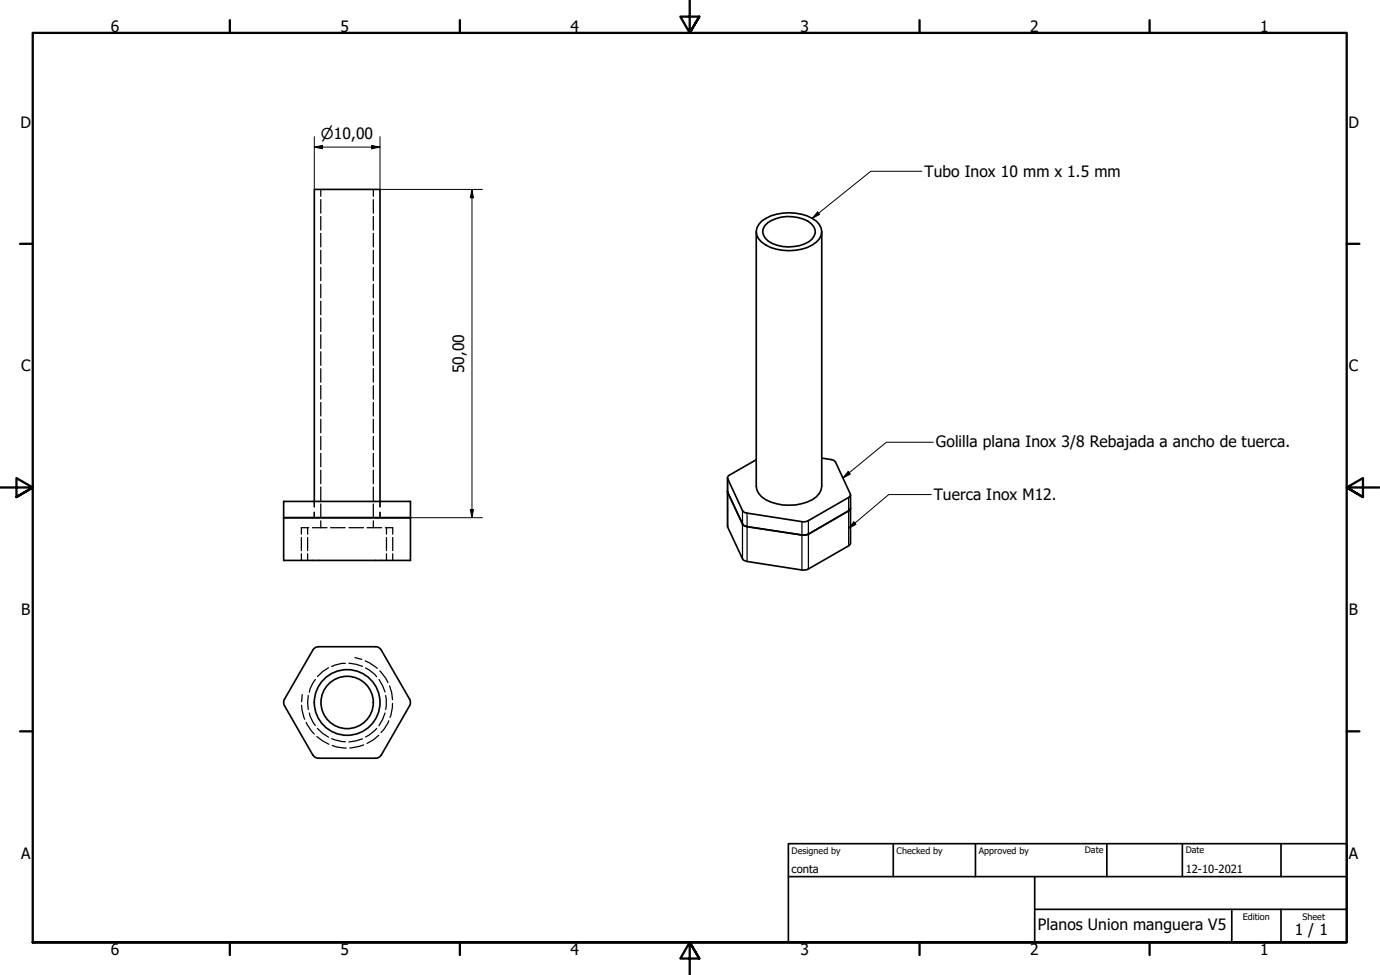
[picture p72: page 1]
Designed by; Checked by; Approved by; Date; Tuerca Inox M12.

Tubo Inox 10 mm x 1.5 mm

Golilla plana Inox 3/8 Rebajada a ancho de tuerca.

Planos Union manguera V5

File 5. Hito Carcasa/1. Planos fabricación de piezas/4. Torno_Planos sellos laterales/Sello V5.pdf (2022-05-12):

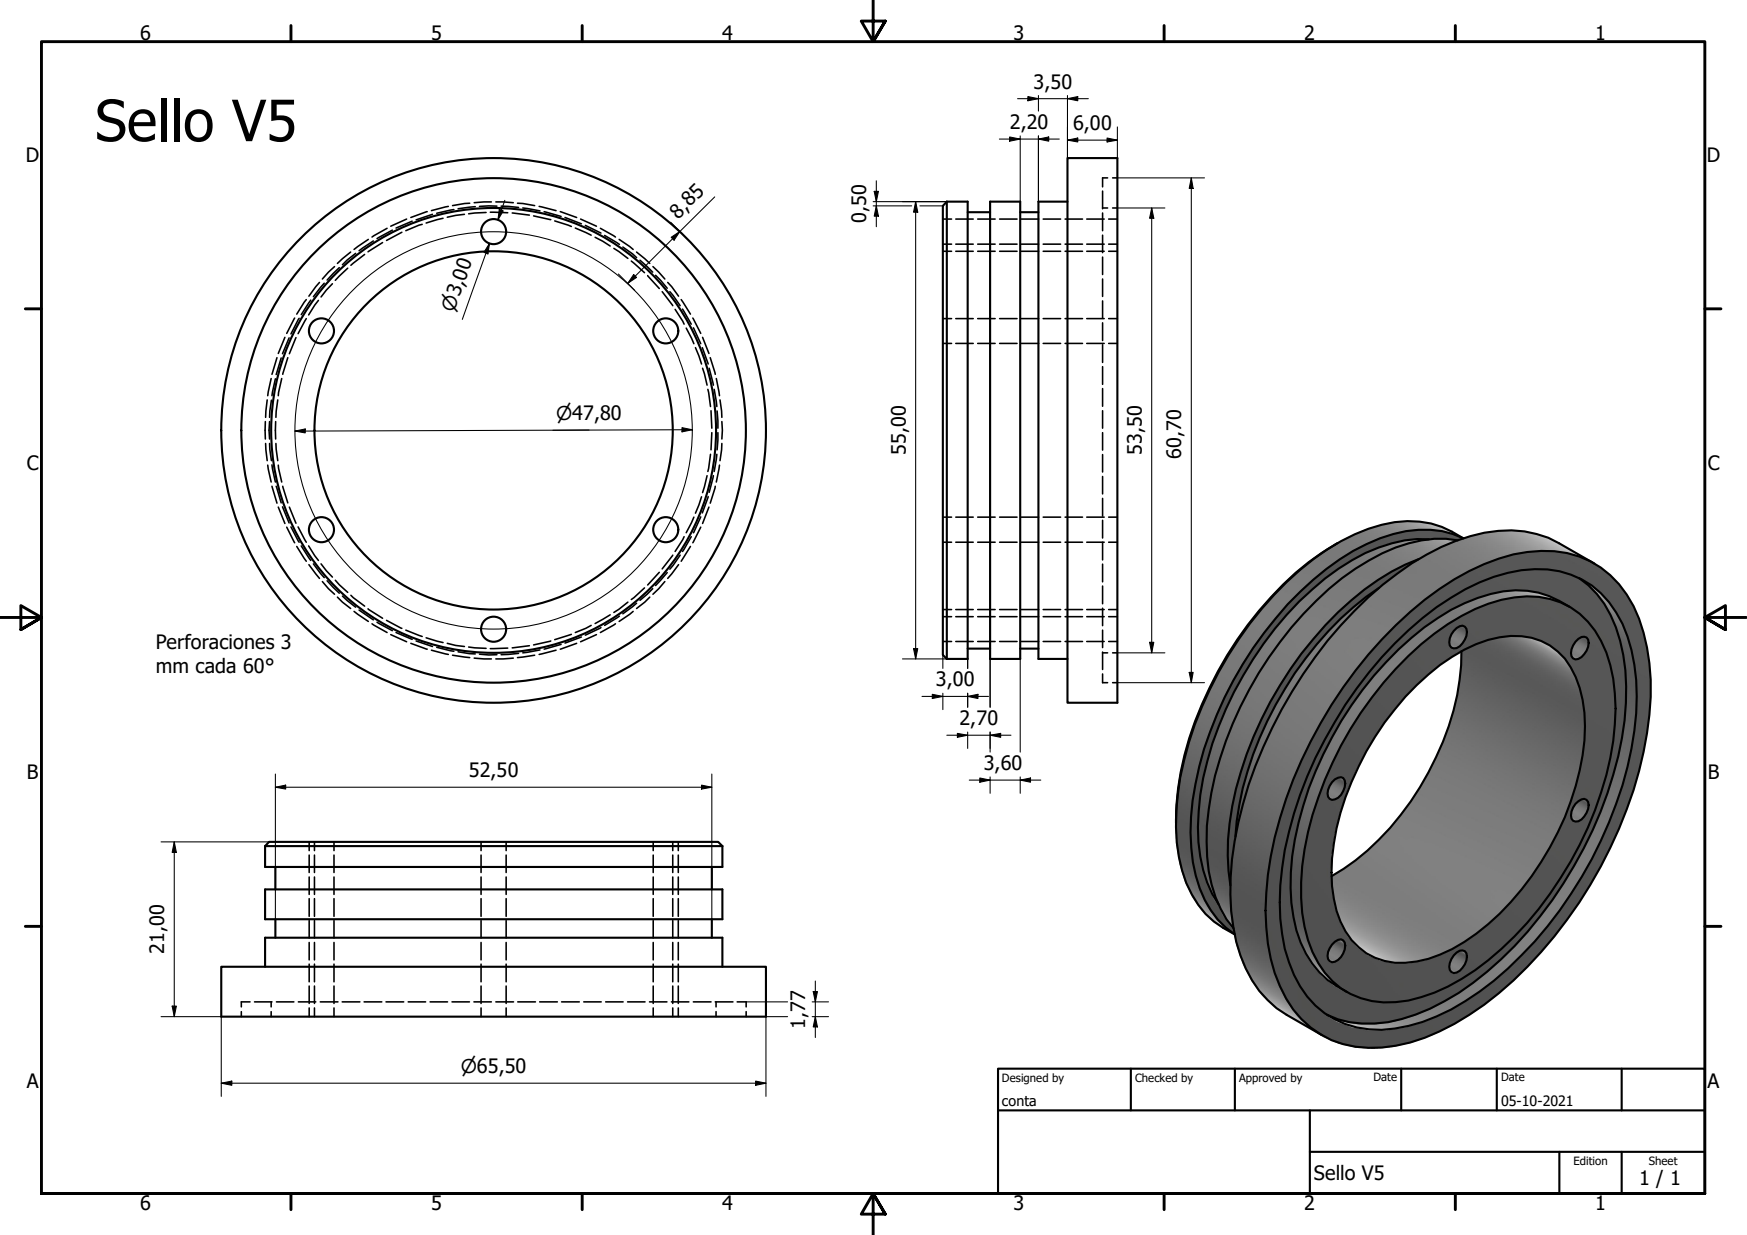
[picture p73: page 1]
Sello V5; Designed by; Checked by; Approved by; Date; Perforaciones 3 mm cada 60°

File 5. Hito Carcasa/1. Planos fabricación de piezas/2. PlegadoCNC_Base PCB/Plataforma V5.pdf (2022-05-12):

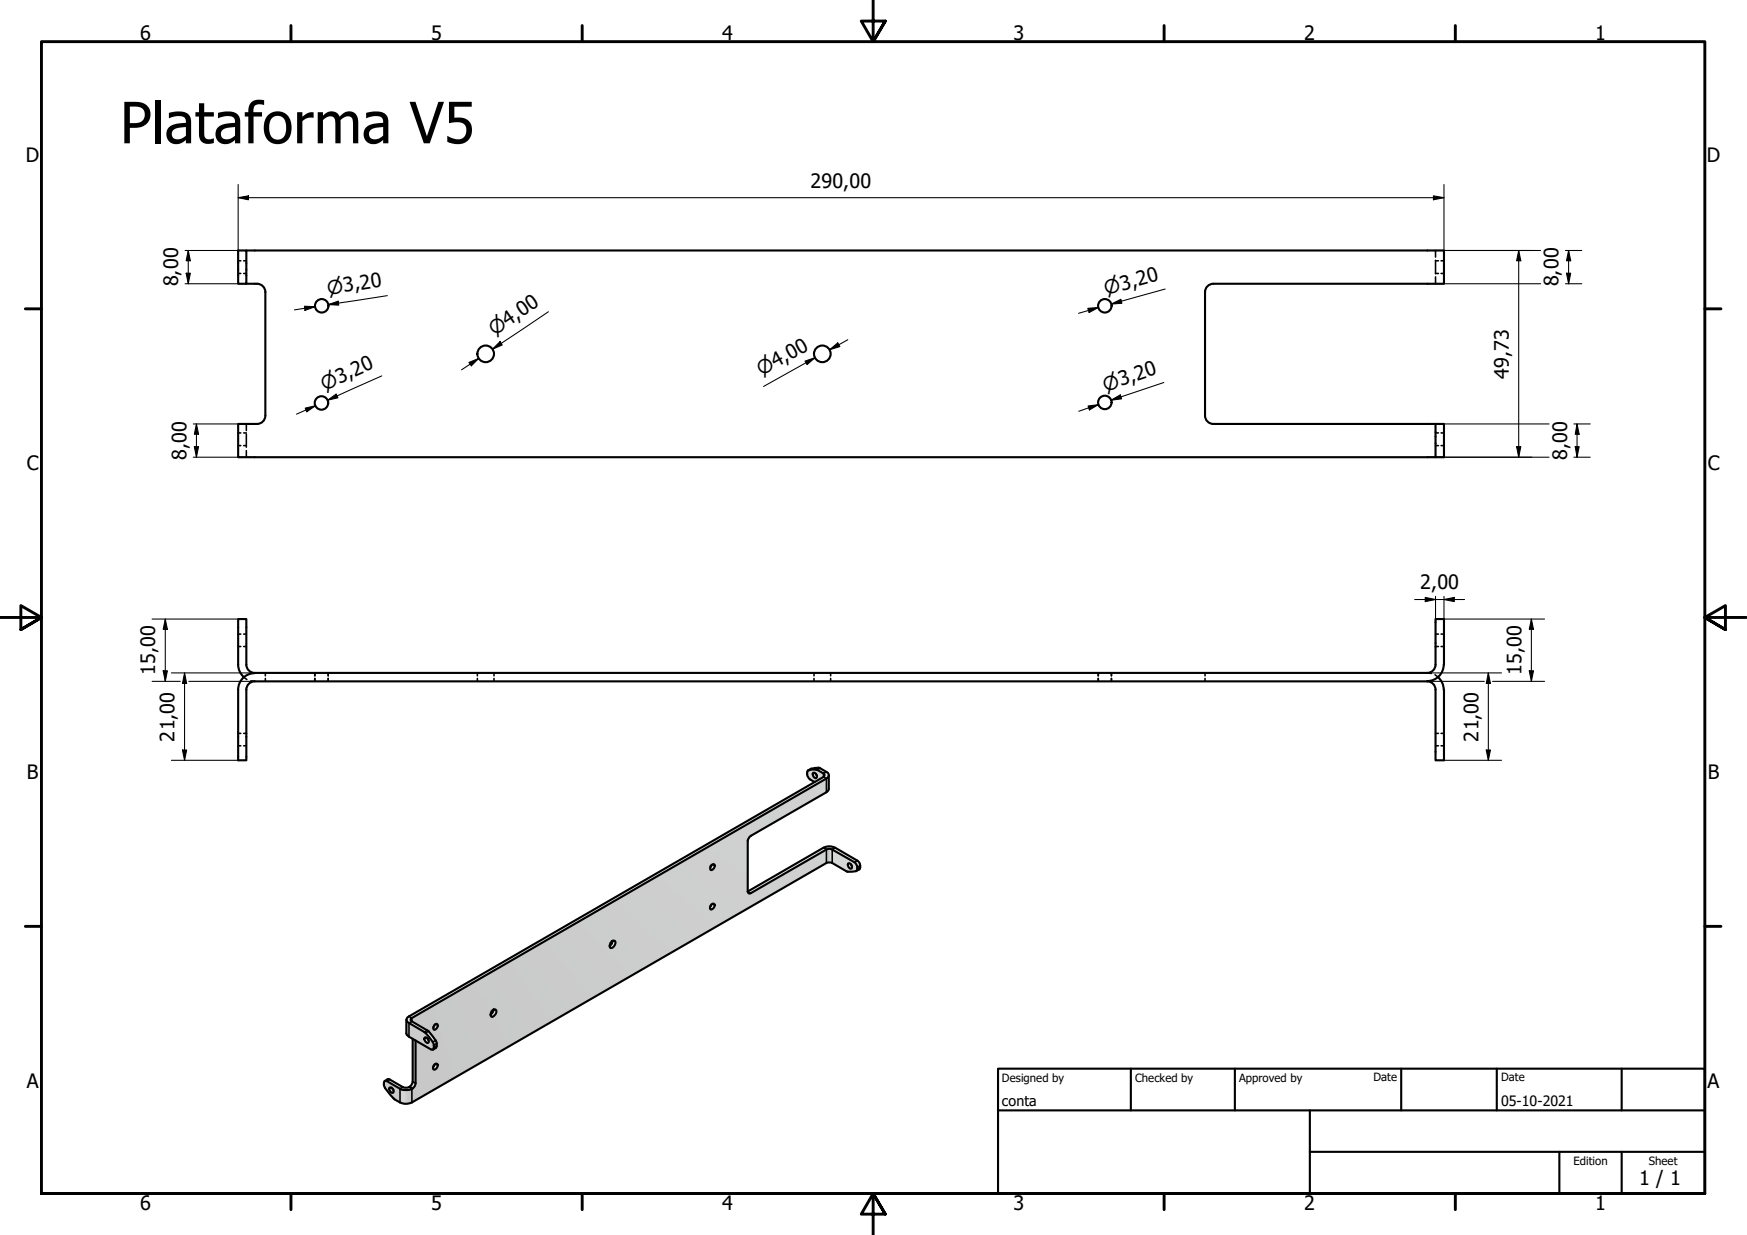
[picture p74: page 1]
Designed by; Checked by; Approved by; Date; Plataforma V5

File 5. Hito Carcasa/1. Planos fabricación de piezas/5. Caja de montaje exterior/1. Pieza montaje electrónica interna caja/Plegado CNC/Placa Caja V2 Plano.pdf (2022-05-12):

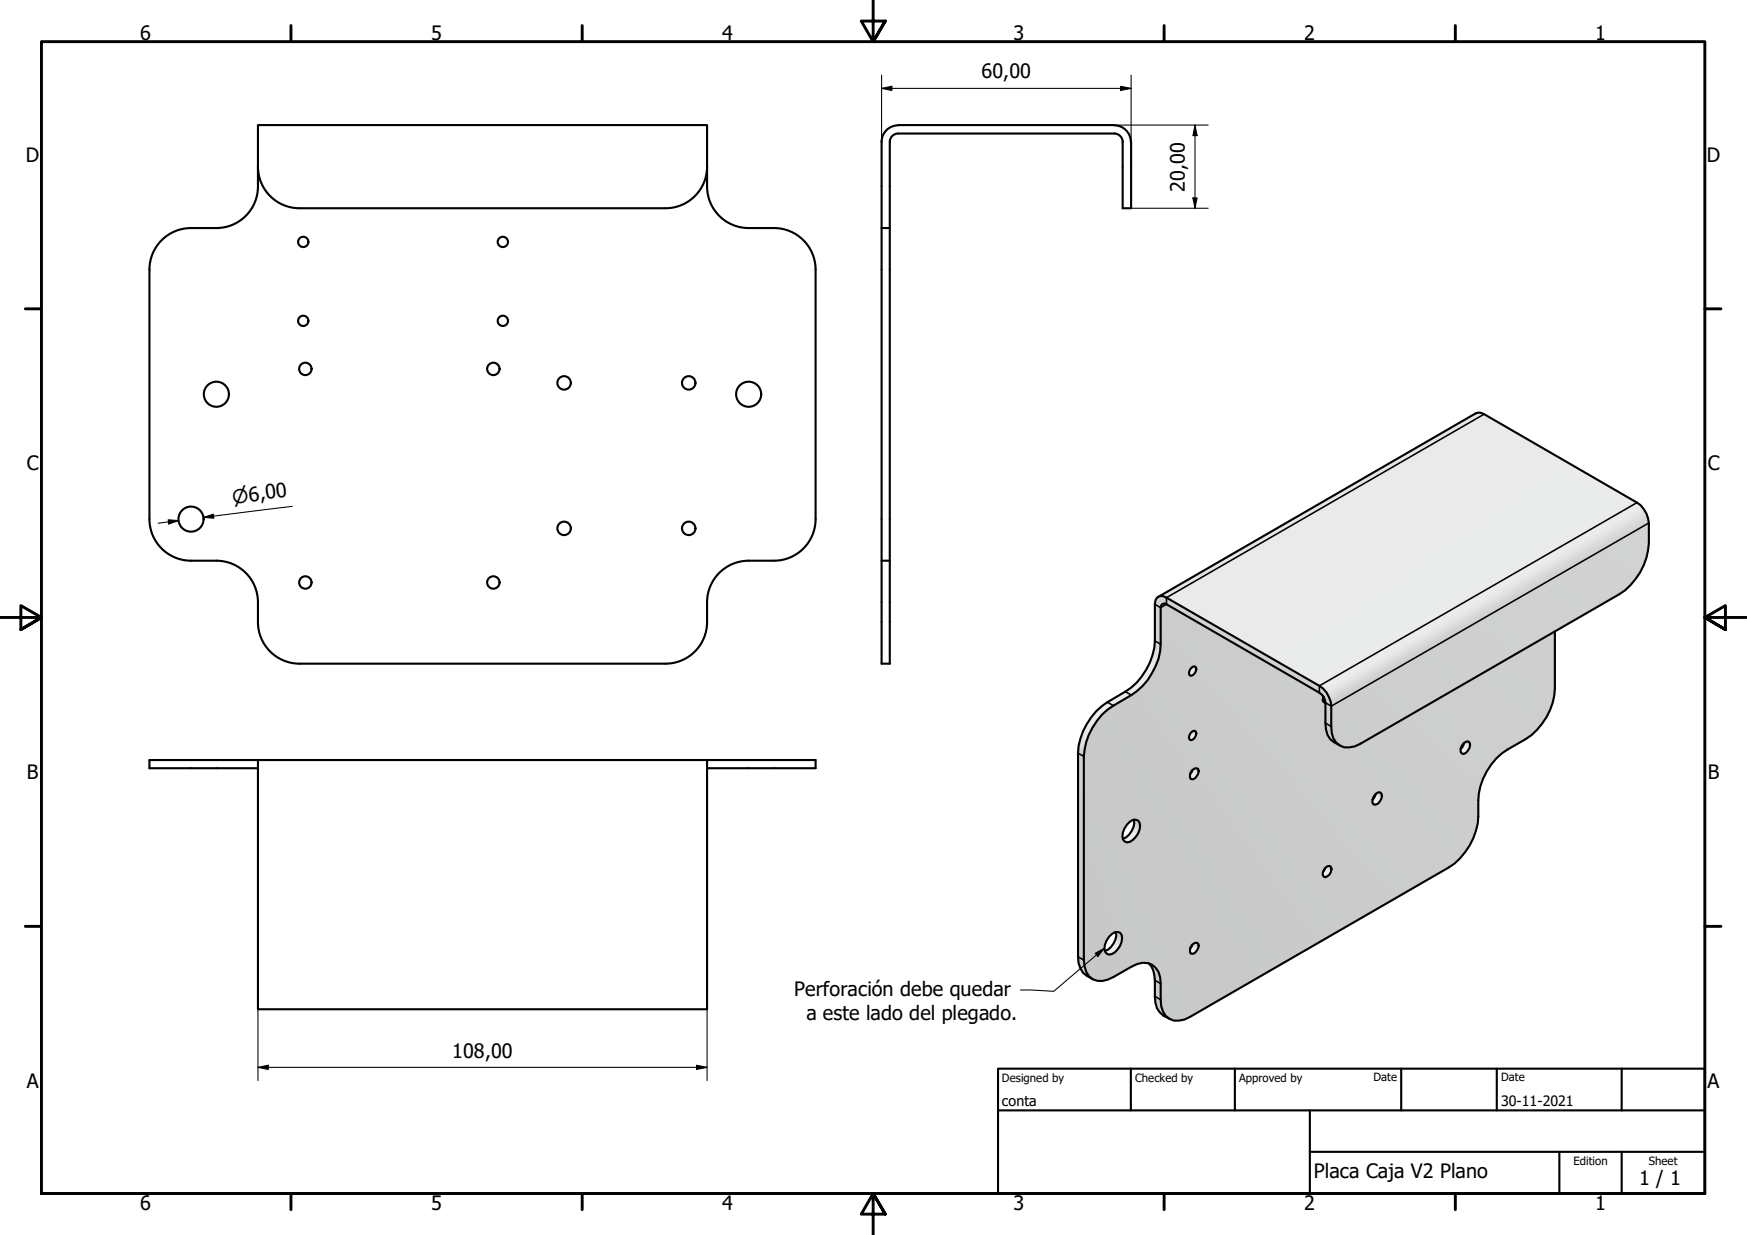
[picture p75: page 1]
Designed by; Checked by; Approved by; Date

Perforaciyn debe quedar
a este lado del plegado.

Placa Caja V2 Plano

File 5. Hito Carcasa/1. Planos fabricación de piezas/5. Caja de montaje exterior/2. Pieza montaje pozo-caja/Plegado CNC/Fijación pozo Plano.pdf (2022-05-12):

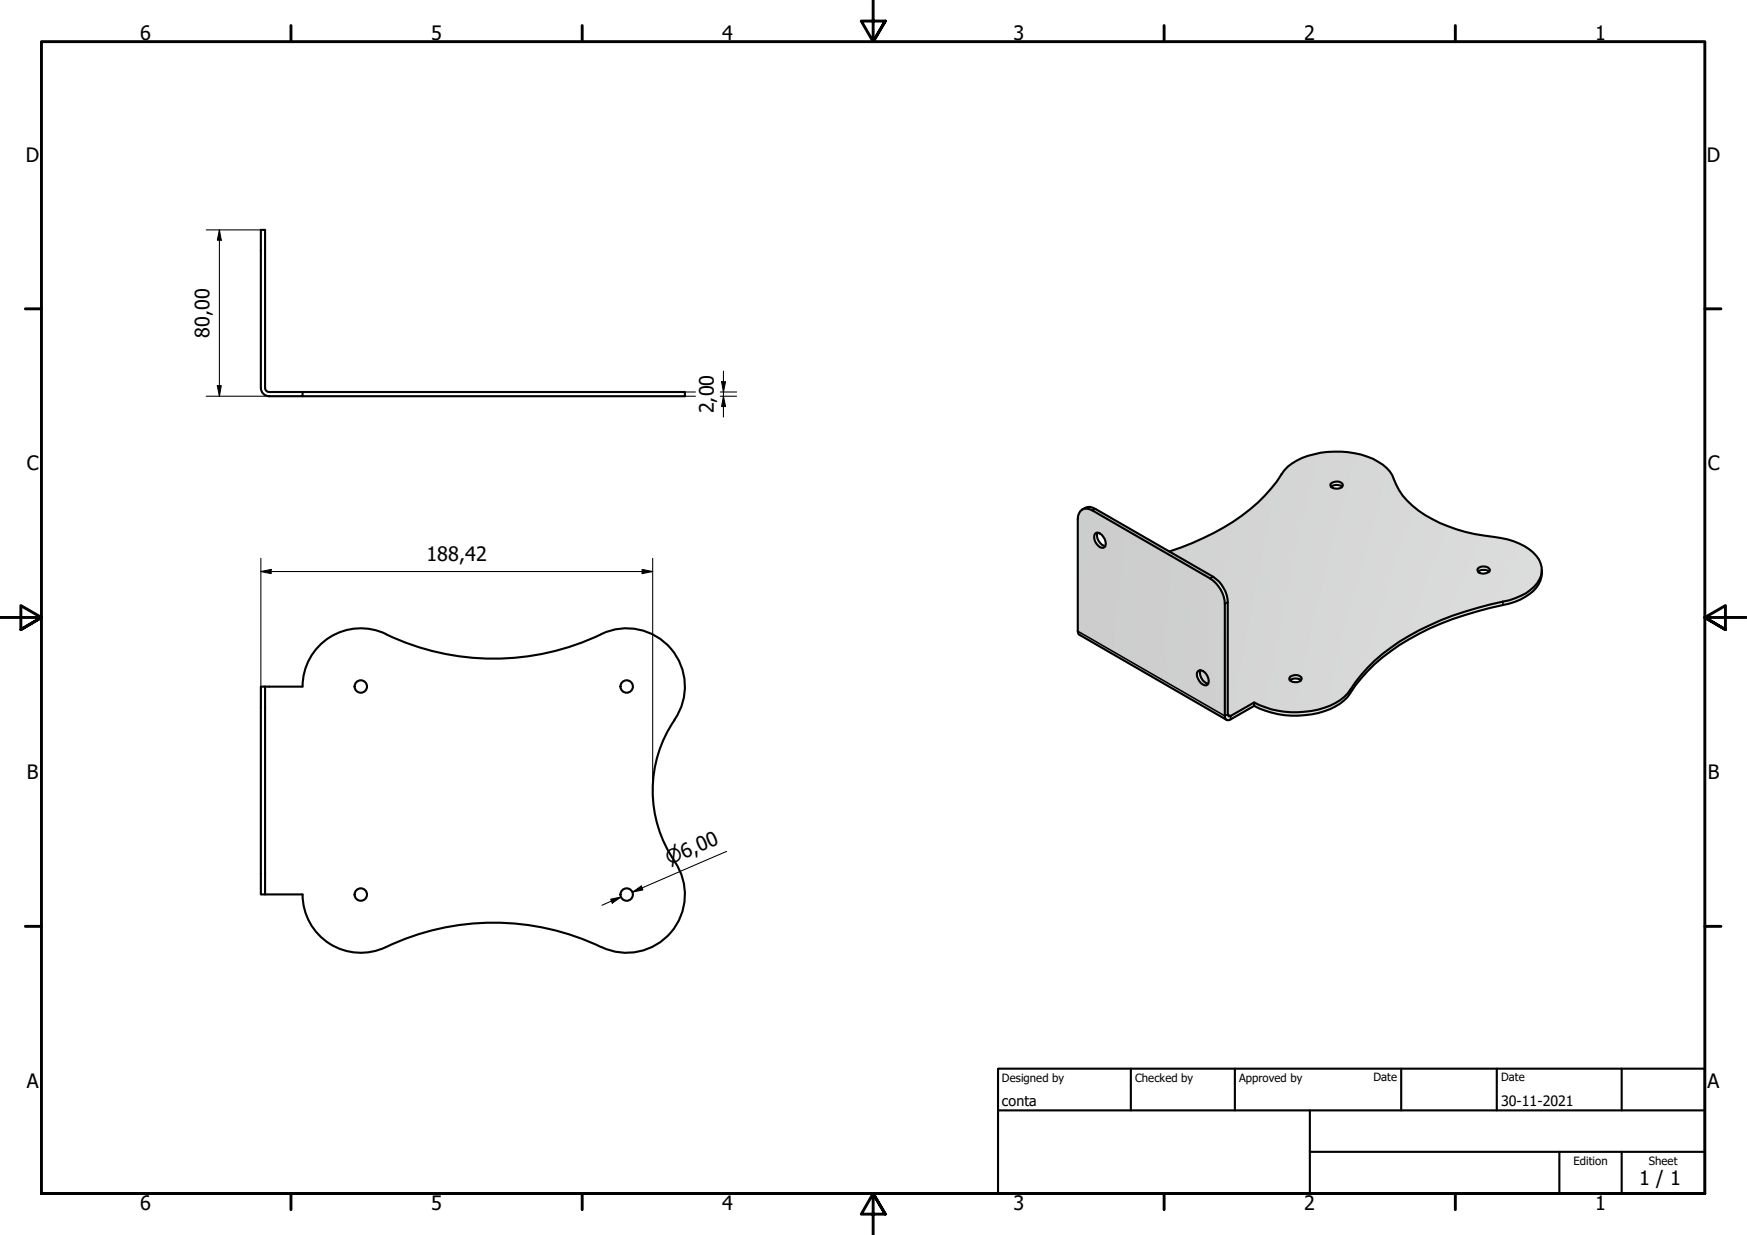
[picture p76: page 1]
Designed by; Checked by; Approved by; Date

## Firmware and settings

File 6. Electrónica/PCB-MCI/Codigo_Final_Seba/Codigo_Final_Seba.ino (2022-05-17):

// Librerías Nativas (instaladas con Arduino)
#include <Arduino.h>
#include <avr/sleep.h>
//#include <SoftwareSerial.h>

// Librerías externas (respaldadas en repositorio)
#include "SdFat.h" // Bill Greiman
#include "SensorPayload.h"
#include "RTClib.h"
#include <OneWire.h> 
#include <DallasTemperature.h>
#include <Adafruit_ADS1X15.h>

/* Using temperature sensor is optional.
 * If USE_DS18B20 is set to 0, a dummy temperature
 * will be given each call (check function ds18b20value)
 * */
#define USE_DS18B20 1

#if USE_DS18B20
#include <DallasTemperature.h>
#endif

// ----------------- Debug option ----------------------
#define DEBUG 0
#if DEBUG
#define debugPrint(x) Serial.print(x)
#define debugPrintln(x) Serial.println(x)
#else
#define debugPrint(x) {}
#define debugPrintln(x) {}
#endif
#define ENCODE_MODE BASE_MODE

// ----------------- Software Serial port --------------
//SoftwareSerial softSerial(8,9);

// ---------------------- DS18B20 ----------------------
// DS18B20 setup variables
#define ONE_WIRE_BUS 3
// Setup a oneWire instance to communicate with any OneWire devices  
OneWire oneWire(ONE_WIRE_BUS); 
#if USE_DS18B20
// Pass our oneWire reference to Dallas Temperature. 
DallasTemperature sensors(&oneWire);
#endif

// ---------------------- ADC ----------------------
Adafruit_ADS1015 adc;     /* Use this for the 12-bit version */

// ------------------ SensorPayload --------------------
#define N_READINGS_ENCODE 7
SensorPayload sp(N_READINGS_ENCODE * 7);

// ---------------------- RTC --------------------------
#define CLOCK_INTERRUPT_PIN 2
#define SENSE_FLAG 0x01
#define SEND_FLAG 0x02
RTC_DS3231 rtc;
uint32_t alarm_time;
uint32_t elapsed_time;
volatile uint8_t alarm_flag;

//------------------- LoPy timer -----------------------
unsigned long startTime;

// --------------------- File configuration variables --------------------------------
#define FILE_BASE_NAME "data"
#define TMP_FILE_NAME FILE_BASE_NAME "###.bin"
// Number of blocks of 512 bytes per file
const uint32_t FILE_BLOCK_COUNT = 2;
const uint8_t BASE_NAME_SIZE = sizeof(FILE_BASE_NAME) - 1;
const uint8_t FILE_NAME_DIM  = BASE_NAME_SIZE + 8;
char binName[FILE_NAME_DIM] = FILE_BASE_NAME "000.bin";
char first_pending_file[3] = {'#', '#', '#'};
uint8_t pending_blocks;
uint8_t next_to_send;

//----------------------- SD configuration variables ---------------------------------
// SD chip select pin.
#define CHIP_SELECT 10
// SD Error messages stored in flash.
#define error(msg) sd.errorHalt(F(msg))
SdFat sd;
SdBaseFile binFile;
block_type *sd_block;
uint16_t written_blocks;

//------------------------ Sensors configuration variables -----------------------  
// SENSING_FREQ_SECS must be less or equal to SENDING_FREQ_SECS
#define SENSING_FREQ_SECS 3
#define SENDING_FREQ_SECS 56 //168
#define N_SENSORS 5
// Typedef of function to read values from sensors
typedef float (*sensorValueFunction) (void);

/* Sensors present on the data logger. If there are repeated sensors on the datalogger,
write them multiple times in the array.
For example, if there are 3 DS18B20 sensors, the array must contain the TEMP_DS18B20 value three times.
*/
uint8_t registered_sensors[N_SENSORS] = {
                                        TDS_GRAVITY,
                                        PH_GRAVITY,
                                        TURB_GROVE,
                                        PRES_GRAVITY,
                                        TEMP_DS18B20
                                        };
/* User defined functions to read data from the registered_sensors array. Must return float and receive 
no parameters 
*/
float adcReader(int channel) {
    int16_t reading = adc.readADC_SingleEnded(channel); // return as RAW
    return (float)reading;
}

float tdsValue() { return adcReader(0); }
float phValue() { return adcReader(1); }
float turbValue() { return adcReader(2); }
float presValue() { return adcReader(3); }

float ds18b20value() {
#if USE_DS18B20
    sensors.requestTemperatures();
    float temp = sensors.getTempCByIndex(0);
#else
    static int call_number = 1;
    float temp = 0.0 + call_number;
    call_number++;
#endif
    return temp;
}

/* Array of pointers to functions to read data from sensors. The order of functions in the array must
follow the same order present in the registered_sensors array.
For example, if registered_sensors = { X, Y, Z }, then the function array must be
sensors_functions = {logDataX, logDataY, logDataZ}
*/

sensorValueFunction sensors_functions[N_SENSORS] = {
                                                   tdsValue,
                                                   phValue,
                                                   turbValue,
                                                   presValue,
                                                   ds18b20value
                                                   };

//--------------------------------- File Functions -----------------------------------------------

void createBinFile() {
    /**
    Create a new work file named TMP_FILE_NAME. If a previous version of TMP_FILE_NAME exists, it
    is removed and a new one is generated. The file generated has a size of FILE_BLOCK_COUNT * 512
    bytes, all initialized at value 0.
    **/
    // max number of blocks to erase per erase call
    const uint32_t ERASE_SIZE = 262144L;
    uint32_t bgnBlock, endBlock;
    // Delete old tmp file.
    if (sd.exists(TMP_FILE_NAME)) {
        debugPrintln(F("Deleting tmp file " TMP_FILE_NAME));
        if (!sd.remove(TMP_FILE_NAME)) {
            error("Can't remove tmp file");
        }
    }
    // Create new file.
    debugPrintln(F("\nCreating new file"));
    binFile.close();
    if (!binFile.createContiguous(TMP_FILE_NAME, 512 * FILE_BLOCK_COUNT)) {
        error("createContiguous failed");
    }
    // Get the address of the file on the SD.
    if (!binFile.contiguousRange(&bgnBlock, &endBlock)) {
        error("contiguousRange failed");
    }
    // Flash erase all data in the file.
    debugPrintln(F("Erasing all data"));
    uint32_t bgnErase = bgnBlock;
    uint32_t endErase;
    while (bgnErase < endBlock) {
        endErase = bgnErase + ERASE_SIZE;
        if (endErase > endBlock) {
            endErase = endBlock;
        }
        if (!sd.card()->erase(bgnErase, endErase)) {
            error("erase failed");
        }
        bgnErase = endErase + 1;
    }
    if (!sd.card()->writeStart(binFile.firstBlock())) {
        error("writeStart failed");
    }
    sd_block->count = 0;
    written_blocks = 0;
}

void renameBinFile() {
    /**
    Rename the current work file binFile with a new unique name based on binName and the existing
    files stored in the SD card. This functions requires the binFile to store an open file, otherwise
    the work file can't be renamed.
    **/
    while (sd.exists(binName)) {
        if (binName[BASE_NAME_SIZE + 2] != '9') {
            binName[BASE_NAME_SIZE + 2]++;
        } 
        else if (binName[BASE_NAME_SIZE + 1] != '9') {
            binName[BASE_NAME_SIZE + 2] = '0';
            binName[BASE_NAME_SIZE + 1]++;
        }
        else if (binName[BASE_NAME_SIZE] != '9') {
            binName[BASE_NAME_SIZE + 1] = '0';
            binName[BASE_NAME_SIZE]++;
        }
        else {
            error("Can't create file name");
        }
    }
    if (!binFile.rename(binName)) {
        error("Can't rename file");
    }
    debugPrint(F("File renamed: "));
    debugPrintln(binName);
    debugPrint(F("File size: "));
    debugPrint(binFile.fileSize()/512);
    debugPrintln(F(" blocks"));
}

// --------------------------------SD Setup ------------------------------------

void setup_sd() {
    /**
    Start the variables associated with the SD card.
    **/
    // Wait for USB Serial
    if(sizeof(block_type) != 512) {
        error("block_type must have 512 bytes of length");
    }
    while (!Serial) {
        SysCall::yield();
    }
    debugPrint(F("Initializing SD ... "));
    // Initialize at the highest speed supported by the board that is
    // not over 50 MHz. Try a lower speed if SPI errors occur.
    if (!sd.begin(CHIP_SELECT, SD_SCK_MHZ(16))) {
        sd.initErrorHalt();
    }
    // Use of SD buffer as data block
    sd_block = (block_type *)sd.vol()->cacheClear();
    if (sd_block == 0) {
        error("cacheClear failed");
    }
    debugPrintln(F("done"));
}
// ------------------------ Interruptions ---------------------------------------

void interrupt_sense() {
    /**
    Interrupt that sets the alarm_flag to trigger a sensing event.
    **/
    alarm_flag |= SENSE_FLAG;    
}

void interrupt_send() {
    /**
    Interrupt that sets the alarm_flag to trigger a sending event.
    **/
    alarm_flag |= SEND_FLAG;
}

void interrupt_both() {
    /**
    Interrupt that sets the alarm_flag to trigger a sensing and a sending event.
    **/
    alarm_flag |= (SENSE_FLAG|SEND_FLAG);    
}

// ------------------------ Sleep Routine ---------------------------------------

void sleep() {
    /**
    Set the Arduino Nano to sleep in Deep Sleep Mode (SLEEP_MODE_PWR_DOWN), after
    setting up the next RTC alarm.
    **/
    detachInterrupt(digitalPinToInterrupt(CLOCK_INTERRUPT_PIN));
    sleep_enable();
    uint32_t dist;
    if(elapsed_time < SENDING_FREQ_SECS) {
        dist = SENDING_FREQ_SECS - elapsed_time;
        if(dist > SENSING_FREQ_SECS) {
            attachInterrupt(digitalPinToInterrupt(CLOCK_INTERRUPT_PIN), interrupt_sense, FALLING);
            rtc.clearAlarm(1);
            alarm_time = rtc.now().unixtime() + SENSING_FREQ_SECS;
            rtc.setAlarm1(DateTime(alarm_time), DS3231_A1_Second);
            elapsed_time += SENSING_FREQ_SECS;
        }
        else if(dist < SENSING_FREQ_SECS) {
            attachInterrupt(digitalPinToInterrupt(CLOCK_INTERRUPT_PIN), interrupt_send, FALLING);
            rtc.clearAlarm(1);
            alarm_time = rtc.now().unixtime() + dist;
            rtc.setAlarm1(DateTime(alarm_time), DS3231_A1_Second);
            elapsed_time += SENSING_FREQ_SECS;
        }
        else {
            attachInterrupt(digitalPinToInterrupt(CLOCK_INTERRUPT_PIN), interrupt_both, FALLING);
            rtc.clearAlarm(1);
            alarm_time = rtc.now().unixtime() + dist;
            rtc.setAlarm1(DateTime(alarm_time), DS3231_A1_Second);
            elapsed_time = 0;
        }
    }
    else if(elapsed_time > SENDING_FREQ_SECS) {
        dist = elapsed_time - SENDING_FREQ_SECS;
        attachInterrupt(digitalPinToInterrupt(CLOCK_INTERRUPT_PIN), interrupt_sense, FALLING);
        rtc.clearAlarm(1);
        alarm_time = rtc.now().unixtime() + dist;
        rtc.setAlarm1(DateTime(alarm_time), DS3231_A1_Second);
        elapsed_time = dist;
    }
    else {
        attachInterrupt(digitalPinToInterrupt(CLOCK_INTERRUPT_PIN), interrupt_both, FALLING);
        rtc.clearAlarm(1);
        alarm_time = rtc.now().unixtime() + SENSING_FREQ_SECS;
        rtc.setAlarm1(DateTime(alarm_time), DS3231_A1_Second);
        elapsed_time = 0;
    }
    set_sleep_mode(SLEEP_MODE_PWR_DOWN);
    sleep_cpu();
}

void logData(reading_type *rt, uint8_t pos) {
    /**
    Log data from the sensor located in the position pos, inside the registered_sensors array.
    The data is stored in a reading_type struct, adressed by the pointer rt.
    **/
    rt->sensor = registered_sensors[pos];
    rt->ts = alarm_time;
    rt->val = sensors_functions[pos]();
    debugPrint(F("."));
}

void sendBuffer() {
    /**
    Send the current data stored in the SensorPayload sp.
    **/
    sp.addChecksum();
    int buf_size = sp.getCurrentSize();
    while(millis() - startTime < 1000); // Busy waiting used to wait one second for LoPy4 to awake.
    debugPrintln("Timer superado");
    int written = Serial.write(sp.getBuffer(), buf_size);
    sp.resetBuffer();
    debugPrint(F("Length of data sent: "));
    debugPrintln(written);
}

void sendCurrentBinFile() {
    /**
    Send the current open file stored in binFile, encoding the data stored inside it in the
    SensorPayload sp.
    **/
    if(!binFile.open(binName, O_READ)) {
        error("open failed");
    }
    while (binFile.read(sd_block, 512) == 512) {
        if(sd_block->count == 0) {
            break;
        }
        int encode_res;
        while(next_to_send < sd_block->count) {
            encode_res = sp.encodeReadings(sd_block, next_to_send, ENCODE_MODE);
            if(encode_res == 0) {
                sendBuffer();
            }
            next_to_send += encode_res;
        }
        next_to_send = 0;
    }
    binFile.close();
}

void wakeUpSender() {
    /**
    Send the value 0xFF to the LoPy4 to wake it up.
    **/
    debugPrintln("Sending 0xFF via serial");
    Serial.write(0xFF);
    startTime = millis();
}

//-------------------------- Main Program ------------------------------------------

void setup() {
    Serial.begin(9600);
    // ---------------------- RTC ----------------------
    if (!rtc.begin()) {
        debugPrintln(F("Couldn't find RTC"));
        while (1);
    }

    //if (rtc.lostPower()) {
    debugPrintln(F("RTC lost power, lets set the time!"));
    rtc.adjust(DateTime(F(__DATE__), F(__TIME__)));
    //}
    // ----------------------- RTC Alarms ---------------
    rtc.disable32K();
    pinMode(CLOCK_INTERRUPT_PIN, INPUT_PULLUP);
    rtc.writeSqwPinMode(DS3231_OFF);
    rtc.disableAlarm(1);
    rtc.disableAlarm(2);
    rtc.clearAlarm(1);
    rtc.clearAlarm(2);
    elapsed_time = 0;
    alarm_flag = 0;
#if USE_DS18B20
    // ---------------------- DS18B20 ----------------------
    debugPrintln(F("Starting DS18B20 sensor..."));
    sensors.begin();
    debugPrintln(F("Done"));
#endif
    // ---------------------- ADC ----------------------
    debugPrintln(F("Starting ADS1015..."));
    if (!adc.begin()) {
        debugPrintln("Failed to initialize ADS.");
        while (1);
    }
    debugPrintln(F("Done"));
    // ---------------------- SD ----------------------
    setup_sd();
    pending_blocks = 0;
    next_to_send = 0;
    // ---------------------- Binary File in SD ----------------------
    createBinFile();
}

void loop() {
    if(alarm_flag & SENSE_FLAG) {
        uint8_t available_slots = DATA_DIM - sd_block->count;
        if(available_slots < N_SENSORS) { // Block is full. Can't write all sensors inside the buffer
            debugPrintln(F("Sd Block is full! Writting to file"));
            while(sd.card()->isBusy()); // Busy waiting
            if (!sd.card()->writeData((uint8_t *)sd_block)) { // Write buffer to SD
                error("write data failed");
            }
            debugPrintln("Data written to file");
            if(++written_blocks == FILE_BLOCK_COUNT) { // If file is full, open another file
                debugPrintln(F("Current file is full! Generating another file"));
                if (!sd.card()->writeStop()) {
                    error("writeStop failed");
                }
                renameBinFile();
                binFile.close();
                createBinFile();
                if(first_pending_file[0] == '#' && pending_blocks) { // Store the number of the first file generated 
                    first_pending_file[0] = binName[BASE_NAME_SIZE];
                    first_pending_file[1] = binName[BASE_NAME_SIZE+1];
                    first_pending_file[2] = binName[BASE_NAME_SIZE+2];
                    pending_blocks = 0;
                }
                next_to_send = 0;
            }
            else {
                if(next_to_send == sd_block->count) { // All data in buffer was sent
                    next_to_send = 0;
                }
                else if(first_pending_file[0] == '#') { // There is no pending file
                    ++pending_blocks;
                }
                sd_block->count = 0;
            }
        }
        for(uint8_t i=0; i<N_SENSORS; i++) { // Write data from all sensors
            logData(&sd_block->data[sd_block->count++], i);
        }
        alarm_flag &= ~SENSE_FLAG;
    }
    if(alarm_flag & SEND_FLAG) {
        wakeUpSender();
        if(first_pending_file[0] != '#') { // There are pending files to send
            debugPrintln(F("There are pending files to send"));
            while(sd.card()->isBusy()); // Busy waiting
            if(sd_block->count) { // Write only if there is data in buffer
                if (!sd.card()->writeData((uint8_t *)sd_block)) {
                    error("write data failed");
                }
            }
            if (!sd.card()->writeStop()) {
                error("writeStop failed");
            }
            renameBinFile();
            binFile.close();
            binName[BASE_NAME_SIZE] = first_pending_file[0];
            binName[BASE_NAME_SIZE+1] = first_pending_file[1];
            binName[BASE_NAME_SIZE+2] = first_pending_file[2];
            while(sd.exists(binName)) {
                debugPrintln(binName);
                sendCurrentBinFile();
                if (binName[BASE_NAME_SIZE + 2] != '9') {
                    binName[BASE_NAME_SIZE + 2]++;
                }
                else if (binName[BASE_NAME_SIZE + 1] != '9') {
                    binName[BASE_NAME_SIZE + 2] = '0';
                    binName[BASE_NAME_SIZE + 1]++;
                }
                else if (binName[BASE_NAME_SIZE] != '9') {
                    binName[BASE_NAME_SIZE + 1] = '0';
                    binName[BASE_NAME_SIZE]++;
                }
            }
            if(sp.getCurrentSize()) {
                sendBuffer(); // There is remaining data not sent
            }
            createBinFile();
            first_pending_file[0] = '#';
            first_pending_file[1] = '#';
            first_pending_file[2] = '#';    
        }
        else if(pending_blocks) { // There are blocks in the current binary file that hasn't been sent
            debugPrintln(F("There are pending blocks to send"));
            while(sd.card()->isBusy()); // Busy waiting
            if(sd_block->count) { // Write only if there is data in buffer
                if (!sd.card()->writeData((uint8_t *)sd_block)) {
                    error("write data failed");
                }
            }
            if (!sd.card()->writeStop()) {
                error("writeStop failed");
            }
            renameBinFile();
            binFile.close();
            debugPrintln(binName);
            sendCurrentBinFile();
            if(sp.getCurrentSize()) {
              sendBuffer(); // There is remaining data not sent
            }
            createBinFile();
            pending_blocks = 0;
        }
        else { // There is data in buffer to send
            debugPrintln(F("There is data in buffer to send"));
            int encode_res;
            while(next_to_send < sd_block->count) {
                encode_res = sp.encodeReadings(sd_block, next_to_send, ENCODE_MODE);
                sendBuffer();
                next_to_send += encode_res;
            }
        }
        alarm_flag &= ~SEND_FLAG;
    }
    sleep();
}

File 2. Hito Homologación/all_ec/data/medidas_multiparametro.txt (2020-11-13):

N,multiparámetro,solución,comment
0,1685,sol. 1413 uS,prueba MP
0,fuera de rango,sol. 1288 uS,prueba MP
0,,,se calibra sensor a 1413 uS/cm
0,1412,sol. 1413 uS,MP antes de medida #1
1 - 14,…,"""""",medidas con sensores
14,1428,"""""",MP luego de medida #14
15 - 29,…,"""""",medidas con sensores
29,1451,"""""",MP luego de medida #29
30,out of range,sol. 12880 uS,MP antes de medida #30
30 - 44,…,"""""",medidas con sensores

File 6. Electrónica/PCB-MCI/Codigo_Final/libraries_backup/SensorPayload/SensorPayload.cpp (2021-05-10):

#include "SensorPayload.h"

int8_t getSign(float val) {
    return val > 0 ? 1 : -1;
}

// ---------- Public methods ----------------

SensorPayload::SensorPayload(uint16_t buf_size) {
    _buffer_size = buf_size;
    _pointer = 0;
    _buffer = new uint8_t[buf_size+2]; //Add two bytes for Checksum
}

SensorPayload::~SensorPayload() {
    delete _buffer;
}

uint8_t *SensorPayload::getBuffer() {
    return _buffer;
}

uint16_t SensorPayload::getCurrentSize() {
    return _pointer;
}

void SensorPayload::resetBuffer() {
    _pointer = 0;
}

uint16_t SensorPayload::availableSize() {
    if(_pointer > _buffer_size){
        return 0;
    }
    return _buffer_size - _pointer;
}

void SensorPayload::addChecksum() {
    if(_pointer < 1) {
        return;
    }
    uint32_t sum1 = 0;
    uint32_t sum2 = 0;
    for(uint8_t i=0; i<_pointer; ++i) {
        sum1 += _buffer[i];
        sum2 += sum1;
    }
    sum1 %= 255;
    sum2 %= 255;
    _buffer[_pointer] = 255 - ((sum1 + sum2) % 255);
    _buffer[_pointer+1] = 255 - ((sum1 + _buffer[_pointer]) % 255);
    _pointer += 2;
}

int SensorPayload::encodeReadings(block_type *block, uint8_t next_to_encode, uint8_t encode_mode) {
    if(next_to_encode < block->count) {
        switch(encode_mode) {
            case(REP_MODE):
                return encodeRepeatedReadings(block, next_to_encode);
            case(DIF_MODE):
                return encodeDiferentialReadings(block, next_to_encode);
            default:
                return encodeBaseReadings(block, next_to_encode);
        }
    }
    return 0;
}

// ---------- Private methods ----------------

int SensorPayload::encodeBaseReadings(block_type *block, uint8_t next_to_encode) {
    int n_encoded = 0;
    uint16_t available = availableSize();
    while(available > 6 && next_to_encode < block->count) {
        encodeBaseSensingUnit(block->data[next_to_encode++]);
        ++n_encoded;
        available = availableSize();
    }
    return n_encoded;
}

void SensorPayload::encodeBaseSensingUnit(reading_type reading, uint8_t header) {
    _buffer[_pointer++] = reading.sensor | header;
    _buffer[_pointer++] = reading.ts >> 24;
    _buffer[_pointer++] = reading.ts >> 16;
    _buffer[_pointer++] = reading.ts >> 8;
    _buffer[_pointer++] = reading.ts;
    uint16_t store_value;
    if(reading.val < 0) {
        store_value = (uint16_t)(reading.val*-10);
        _buffer[_pointer++] = 128 | (store_value >> 8);
    }
    else {
        store_value = (uint16_t)(reading.val*10);
        _buffer[_pointer++] = 127 & (store_value >> 8);
    }
    _buffer[_pointer++] = store_value;
}

void SensorPayload::encodeBaseSensingUnit(reading_type reading, int8_t sign, uint16_t val, uint8_t header) {
    _buffer[_pointer++] = reading.sensor | header;
    _buffer[_pointer++] = reading.ts >> 24;
    _buffer[_pointer++] = reading.ts >> 16;
    _buffer[_pointer++] = reading.ts >> 8;
    _buffer[_pointer++] = reading.ts;
    if(sign < 0) {
        _buffer[_pointer++] = 128 | (val >> 8);
    }
    else {
        _buffer[_pointer++] = 127 & (val >> 8);
    }
    _buffer[_pointer++] = val;
}


int SensorPayload::encodeRepeatedReadings(block_type *block, uint8_t next_to_encode) {
    uint16_t available;
    int n_encoded = 0;
    while(next_to_encode < block->count) {
        available = availableSize();
        if(available < 7) { // No space available
            return n_encoded;
        }
        if(available < 14) { // Only 7 bytes available
            encodeBaseSensingUnit(block->data[next_to_encode]);
            return n_encoded + 1;
        }
        if(block->count - next_to_encode < 3) { // There are less than 3 readings to encode
            encodeBaseSensingUnit(block->data[next_to_encode++]);
            if(next_to_encode < block->count) {
                encodeBaseSensingUnit(block->data[next_to_encode]);
                return n_encoded + 2;
            }
            return n_encoded + 1;
        } // At this point there are at least 3 readings to encode and 14 bytes of encoding space 
        int8_t first_sign = getSign(block->data[next_to_encode].val);
        uint16_t first_val = (uint16_t)(block->data[next_to_encode].val*first_sign*10);
        int8_t next_sign = getSign(block->data[next_to_encode+1].val);
        uint16_t next_val = (uint16_t)(block->data[next_to_encode+1].val*next_sign*10);
        if(first_sign != next_sign || first_val != next_val) {
            encodeBaseSensingUnit(block->data[next_to_encode], first_sign, first_val);
            ++next_to_encode;
            ++n_encoded;
            continue;
        }
        next_sign = getSign(block->data[next_to_encode+2].val);
        next_val = (uint16_t)(block->data[next_to_encode+2].val*next_sign*10);
        if(first_sign != next_sign || first_val != next_val) {
            encodeBaseSensingUnit(block->data[next_to_encode], first_sign, first_val);
            encodeBaseSensingUnit(block->data[next_to_encode+1], first_sign, first_val);
            next_to_encode += 2;
            n_encoded += 2;
            continue;
        }
        uint16_t time_interval = (uint16_t)(block->data[next_to_encode+1].ts - block->data[next_to_encode].ts);
        uint16_t num_of_values = 2;
        encodeBaseSensingUnit(block->data[next_to_encode], first_sign, first_val, 176); // BaseSensingUnit with Repeated header
        next_to_encode += 3;
        n_encoded += 3;
        while(next_to_encode < block->count) {
            next_sign = getSign(block->data[next_to_encode].val);
            next_val = (uint16_t)(block->data[next_to_encode].val*next_sign*10);
            if(first_sign != next_sign || first_val != next_val) {
                break;   
            }
            ++next_to_encode;
            ++n_encoded;
            ++num_of_values;
        }
        encodeRepeatedSensingUnit(block->data[next_to_encode-1].sensor, time_interval, num_of_values);
    }
    return n_encoded;
}

void SensorPayload::encodeRepeatedSensingUnit(uint8_t sensor, uint16_t time_interval, uint16_t num_of_values) {
    _buffer[_pointer++] = sensor | 176;
    _buffer[_pointer++] = time_interval >> 8;
    _buffer[_pointer++] = time_interval;
    _buffer[_pointer++] = 0;
    _buffer[_pointer++] = 0;
    _buffer[_pointer++] = num_of_values >> 8;
    _buffer[_pointer++] = num_of_values;
}
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

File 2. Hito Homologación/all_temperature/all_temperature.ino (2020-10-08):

#include <OneWire.h>
#include <DallasTemperature.h> // DS18B20
#include <Wire.h> // SHT20

#define PRINT_NO_OF_DECIMALS 3
#define COL_SEP "; "
#define USE_SHT20 0 // SHT20 is not waterproof!
// ------------------------- TEMPERATURE -------------------------

// DS18B20
#define TEMP_DS18B20_PIN 5
#define DS18B20_BIT_RESOLUTION 9
OneWire onewire_bus(TEMP_DS18B20_PIN);
DallasTemperature temp_ds18b20(&onewire_bus);

uint8_t ds18b20_addrs[][8] = {{0x28, 0x55, 0x9E, 0x0E, 0x21, 0x19, 0x01, 0xE4},
                              {0x28, 0x53, 0x8B, 0xB0, 0x1B, 0x19, 0x01, 0xC8},
                              {0x28, 0x51, 0xA5, 0x56, 0xB5, 0x01, 0x3C, 0x67},
                              {0x28, 0xF0, 0x58, 0x56, 0xB5, 0x01, 0x3C, 0x46},
                              {0x28, 0x6B, 0xA6, 0x56, 0xB5, 0x01, 0x3C, 0x0B}};

// SHT20
#include <Wire.h>
#if USE_SHT20
#define I2C_MUX_PIN 4
#define MUX_SHT20_1 HIGH // Only this device is in this bus
#define MUX_SHT20_2 LOW // Main bus is here
#endif //USE_SHT20

// Thermistor
#define THERMISTOR_PIN A0
// RT: Thermistor resistance [Ohm] = M*( Temp [°C] ) + N
// RA: Auxiliary resistor
#define M_THERMISTOR -287.59921
#define N_THERMISTOR 17429.89389
#define RA_THERMISTOR 10000 // 10 KOhm
#define VCC_THERMISTOR 5 // V
/*
 *   VCC
 *    |
 *    RT
 *    ├---> Vin (to Arduino)
 *    RA
 *    |
 *   GND
 **/
float measure_thermistor(float vin) {
    // Equation derived from voltage divider above
    return vin; //(1/M_THERMISTOR)*( RA_THERMISTOR*(VCC_THERMISTOR-vin)/vin - N_THERMISTOR );
}

// Temp Atlas
//#define TEMP_ATLAS_I2C_ADDR 102
//#define TEMP_ATLAS_WAIT     600
#include <SoftwareSerial.h>
#define TEMP_ATLAS_SERIAL_RX 2
#define TEMP_ATLAS_SERIAL_TX 3
SoftwareSerial temp_atlas(TEMP_ATLAS_SERIAL_RX, TEMP_ATLAS_SERIAL_TX);
String temp_atlas_string = "";

// general
String input_str;
unsigned long t0;

void setup() {
    Serial.begin(9600);

    // Temp
    temp_ds18b20.begin();
    temp_ds18b20.setWaitForConversion(false); // <- Must wait manually! (bitResolution = 9 for OneWire)

#if USE_SHT20
    pinMode(I2C_MUX_PIN, OUTPUT);
    digitalWrite(I2C_MUX_PIN, MUX_SHT20_2); // default I2C bus

    Wire.begin();
    Serial.println(F("[TEMP] Will init SHT20 1..."));
    sht20_begin(&Wire);

    delay(10);
    Serial.println(F("[TEMP] SHT20 2..."));
    digitalWrite(I2C_MUX_PIN, MUX_SHT20_1);
    sht20_begin(&Wire);
    digitalWrite(I2C_MUX_PIN, MUX_SHT20_2);
#endif //USE_SHT20

    // Thermistor
    pinMode(THERMISTOR_PIN, INPUT);

    // (Atlas only need I2C)
    temp_atlas.begin(9600);
    temp_atlas_string.reserve(20);
    // Temp Atlas Serial doesn't respond first two measurements
    for (int i=0; i<2; i++) {
      temp_atlas.print("r");
      temp_atlas.print('\r');
      while (temp_atlas.available() > 0) {
        temp_atlas.read();
      }
    }
    // Make sure *OK echo is turned off
    temp_atlas.print("*OK,0");
    temp_atlas.print('\r');
    while (temp_atlas.available() > 0) {
      temp_atlas.read();
    }

    Serial.println(F("[Temp done]"));

    delay(500); 
    Serial.println(F("Setup done."));
}

void loop() {
  measuringMenu();
}

// -------------------- MEASURING --------------------

void measuringMenu() {
    while (1) {
        Serial.println(F("\nMEASURING menu:"));
        Serial.println(F("[1] All temperature sensors"));
        while (!Serial.available());
        input_str = Serial.readString();
        switch (input_str.charAt(0)) {
            case '1':
                measuringInterface(measureTemp);
                return;
            default:
                Serial.println(F("[Not an option]"));
                continue;
        }

    }
}

void measuringInterface(void (*measuringCallback)(int)) {
    int index = 1;
    Serial.println(F("[0 to stop, anything else to take one measurement]"));
    while (1) {
        while (!Serial.available());
        input_str = Serial.readString();
        switch (input_str.charAt(0)) {
            case '0':
                return;
            default:
                measuringCallback(index);
                index++;
        }
    }
}

// ------------------------- TEMPERATURE -------------------------

void measureTemp(int index) {
    if (index == 1) {
#if USE_SHT20
        Serial.println("#" COL_SEP "t" COL_SEP "DS18B20.1" COL_SEP "DS18B20.2" COL_SEP "DS18B20.3" COL_SEP "DS18B20.4" COL_SEP "DS18B20.5"
                           COL_SEP "SHT20.1" COL_SEP "SHT20.2" COL_SEP "Atlas"); // CSV Header
#else
        Serial.println("#" COL_SEP "t" COL_SEP "DS18B20.1" COL_SEP "DS18B20.2" COL_SEP "DS18B20.3" COL_SEP "DS18B20.4" COL_SEP "DS18B20.5"
                           COL_SEP "termistor" COL_SEP "Atlas"); // CSV Header
#endif //USE_SHT20
        if (temp_ds18b20.getDeviceCount() != 5) {
            Serial.println("[Error: expected 5 DS18B20 sensors]");
            return;
        }
        t0 = 0; // reset time
    }

    Serial.print(index, DEC);
    Serial.print(COL_SEP);

    Serial.print(millis() - t0, DEC);
    Serial.print(COL_SEP);
    for (int i = 0; i < 5; i++) {
        temp_ds18b20.requestTemperaturesByAddress(ds18b20_addrs[i]); 
    }

    temp_ds18b20.blockTillConversionComplete(DS18B20_BIT_RESOLUTION); // Modify DallasTemperature.h, move `blockTillConversionComplete` to public:

    float temp;
    // DS18B20
    for (int i = 0; i < 5; i++) {
        temp = temp_ds18b20.getTempC(ds18b20_addrs[i]);
        Serial.print(temp, PRINT_NO_OF_DECIMALS);
        Serial.print(COL_SEP);
    }
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

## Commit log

2020-03-23 Create base repository structure
    [data-logger-circuit.fzz]
2020-04-07 Create v2 of data logger circuit
    [data-logger-v2.fzz]
2020-04-07 Add arduino RTC examples
2020-04-08 Added debounce capacitor
    [data-logger-v2.fzz]
2020-04-13 Fix data logger connection diagram
    [data-logger-v2.fzz]
2020-04-13 Fix wiring for SD card module
    [data-logger-v2.fzz]
2020-04-21 Fix pin number according to data-logger-v2.fzz
2020-05-20 Analog sensor to SD and Screen
2020-05-28 Preliminary Arduino library for data logging
2020-06-09 Fixing U8x8 and I2C issue.
    An earlier version of this sketch used the
    U8X8_SSD1306_128X64_NONAME_SW_I2C driver. However, this driver
    conflicted with the Wire.h library, as noted here:
    https://forum.arduino.cc/index.php?topic=482386.0
2020-06-11 Cambio de nombre
2020-08-26 Adding PH sensors examples
2020-10-05 Measuring all temperature sensors simultaneously
2020-10-19 Experimental data
    [2020-10-07_data_sensores_homologacion.csv, 2020-10-14_data_ph.csv]
2020-11-13 EC measurements
    [2020-10-22_data_ECGravity.csv, 2020-10-22_data_TDSGravity1.csv, 2020-10-22_data_TDSGravity2.csv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]
2020-11-26 agrega codigo para multi sensor con escritura en SD
2020-12-17 agrega define faltantes y quita SensorPayload
2021-01-06 agrega modulo de codificacion
2021-01-06 agrega modulo de decodificacion
2021-01-06 agrega codigo de nodo sensor segunda version
2021-01-11 ordena carpetas
    [2020-10-07_data_sensores_homologacion.csv, 2020-10-14_data_ph.csv, 2020-10-22_data_ECGravity.csv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]
2021-01-13 data-logger/libraries ready to copy to Arduino/libraries
2021-01-22 Calibration script
2021-03-08 Adding watchdog timer for connection issues.
    [RPi_FireBase.py]
2021-05-10 add arduino code used in energy measurement
2021-05-10 add SensorPayload library
2021-05-10 add code to measure current using INA219
2021-05-10 add current data
    [arduino_5m_5v_base.csv, arduino_5m_5v_dif.csv, arduino_5m_5v_rep.csv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]
2021-05-18 Documenting calibration
2021-08-14 LoPy SD, datos desde Arduino
2021-08-23 Writing using expansion board SD socket. Renaming external SD version.
2021-08-27 Fixing P4 pin collision bug
    [boot.py, main.py]
2021-08-27 Measuring pressure with LoPy
2021-10-20 Códigos de prueba PCB MCI
2021-10-25 testing decoding from mci pcb files
2021-10-27 SensorPayload can run without an Arduino
2021-11-10 Debugging arduino_nodo_sensor
2021-11-11 Cleaning arduino_nodo_sensor debugging
2021-11-12 Datos de prueba codificador Nov 11
    [data###.csv, data000.csv, data001.csv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]
2021-11-12 Create Presión (Nivel de Agua).md
2021-11-12 Update Presión (Nivel de Agua).md
2021-11-12 archivos de datos
2021-11-16 Sketchs para experimentos iteración 4
2021-11-16 espacio de prueba
2021-11-16 prueba de commit
2021-12-10 Se agrega descripción de sketches
2021-12-19 print message modified
2022-01-04 Ordenando carpetas
    [2020-10-07_data_sensores_homologacion.csv, 2020-10-14_data_ph.csv, 2020-10-22_data_ECGravity.csv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]
2022-01-05 Added 4 channel ADC
2022-01-05 Added libraries for Código_Final_Seba.ino
    [CPPLINT.cfg]
2022-01-05 Updated debug prints
2022-01-06 Update para no guardar en SD (test)
2022-01-14 Revert "Update para no guardar en SD (test)"
    This reverts commit 7ff944f2156a89784902e955a7b34d48174699b4.
    [Codigo_Final_Seba.ino]
2022-04-01 orden repo
    [CPPLINT.cfg]
2022-04-18 prueba de cambio
2022-04-25 ADD: Se agrega la informacion del capitulo de comunicacion inalambrica
2022-04-25 CHG: Se modifica extension de archivo de imagen
2022-04-25 CHG: Se modifica extension de archivos de imagen
2022-05-12 Cambio carcasa
    [Armado Ensamble.stp, Enganche Aza V6 x 1 unidad.dwg, Enganche Base V6 x 1 unidad.dwg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]
